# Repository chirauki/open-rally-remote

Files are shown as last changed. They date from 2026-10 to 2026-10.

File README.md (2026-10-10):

# Open Rally Remote

An open-source Bluetooth handlebar remote for motorcycle navigation and digital roadbooks. The project aims to keep the unit compact, rugged, affordable, and buildable one unit at a time by individual makers.

## Project status

Requirements and the first-version concept are being defined. No hardware design or compatibility claim has been validated yet.

See the [project brief](docs/project-brief.md) for the current goals, proposed design, constraints, and development plan. The current [control mapping draft](docs/control-mapping.md) records proposed app profiles and the compatibility checks still needed. The [prototype plan](docs/prototype-plan.md) compares controller candidates and lays out a bench proof of concept. The [XIAO breadboard assembly guide](docs/breadboard-assembly.md) gives a Spain-sourced bill of materials and wiring diagram for the temporary input fixture.

The proposed [firmware specification](docs/firmware-spec.md) defines the first BLE HID approach, input and gesture behavior, app-profile boundaries, bench validation, and the product requirement for phone-based BLE firmware updates.

The [development environment guide](docs/development-environment.md) explains how to set up Arduino IDE 2 for the purchased XIAO nRF52840, upload a smoke-test sketch, and use the Serial Monitor. The [mechanical CAD notes](docs/mechanical-concept.md) document the current NAVCOMM-referenced split-ring concept, with broad tapered shoulders joining the control pod to the clamp, raised external controls, and a 23 mm target width along the bar.

The [battery study](docs/battery-study.md) compares battery options and settles on a removable remote with a fixed LiPo pouch, shared between bikes on a bayonet base and charged off the bike (issue #1). It waits on bench and bike measurements; no CAD has changed yet.

The [joystick PCB](electronics/joystick-pcb/README.md) is a KiCad design for the four joystick switches and the 5 V input protection, with Gerbers and a BOM; it has not been built yet.

The first [XIAO diagnostic firmware](firmware/xiao-nrf52840/README.md) reads the breadboard switches and sends BLE HID keyboard events. It compiles and reads the joystick center as a chord of the direction switches, but has not yet been tested on the purchased hardware; app profiles and mobile OTA updates remain future work.

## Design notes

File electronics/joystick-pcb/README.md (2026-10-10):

# Joystick PCB — V0.23

The joystick PCB carries the four C&K KSC2 switches under the stick's cross disc, and the 5 V input protection for the whole remote. It fits the V0.23 enclosure ([CAD](../../mechanical/cad/complete-remote-v0.23.scad), [notes](../../docs/mechanical-concept.md)).

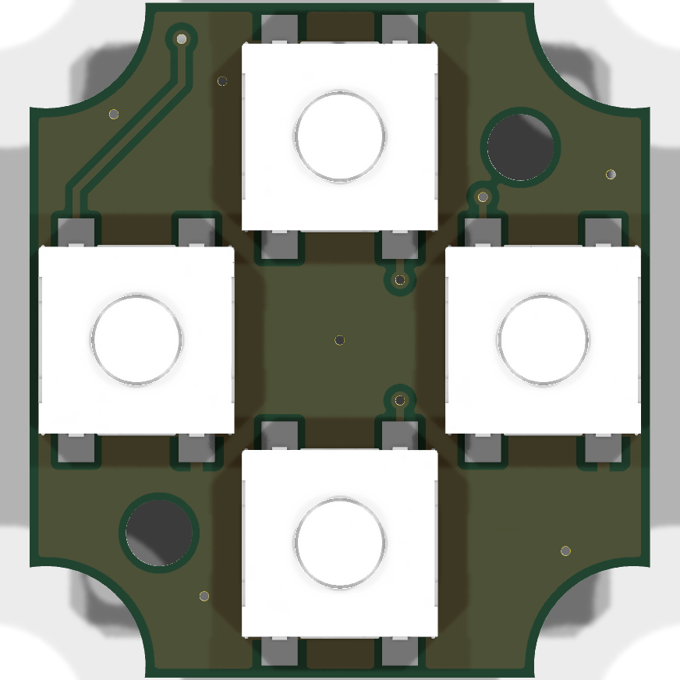
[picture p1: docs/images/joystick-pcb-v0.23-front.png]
Front: the four switches, facing the cover.


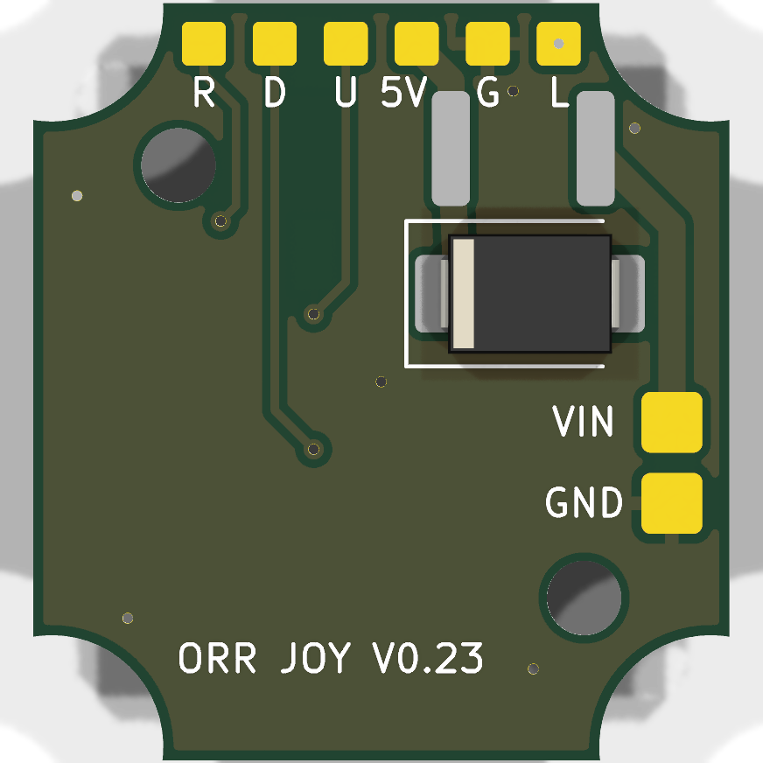
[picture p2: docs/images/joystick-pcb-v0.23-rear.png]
Rear: input pads, PTC fuse (pads only, no 3D model in the stock library), TVS diode and the six wire pads to the XIAO.


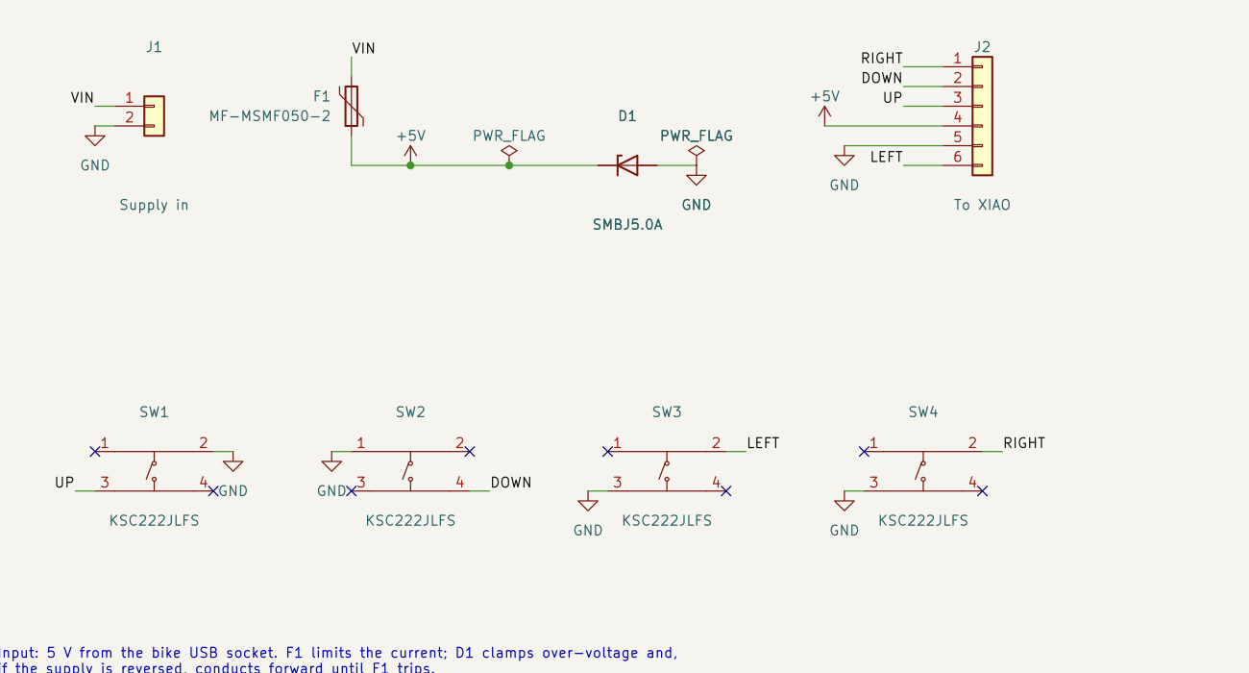
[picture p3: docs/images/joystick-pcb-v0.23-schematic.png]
Schematic.


Status: designed and checked in KiCad (ERC, DRC and schematic parity clean). Not yet built.

## Board

- Two layers, 1.6 mm FR-4, 1 oz copper. Ground pour on both sides.
- Outline 20.6 × 22.4 mm, with a 3.3 mm radius notch at each corner for the lower cover-screw bosses. The same numbers are in the CAD (`joy_pcb_hx`, `joy_pcb_hy`, `joy_pcb_notch_r`).
- Rules: 0.2 mm clearance, 0.25 mm signal tracks, 0.8 mm supply tracks, 0.6/0.3 mm vias, 0.3 mm copper to edge. These are within standard JLCPCB and PCBWay limits.
- Two Ø2.2 mm holes for M2 × 8 button-head screws into the joystick plate standoffs. The head must be no more than Ø3.5 × 1.1 mm (ISO 7380 style): a pan head touches a 12 mm wide USB-C plug in the XIAO when the cover is off.

Board coordinates are seen from the front (switch side, facing the cover). +x is the rider's right, +y is down the facet, away from button C.

## Circuit

| Net | Front | Rear |
|---|---|---|
| UP, DOWN, LEFT, RIGHT | One pad of each switch | Wire pads U, D, L, R to XIAO D3, D4, D5, D6 |
| GND | The diagonally opposite pad of each switch | Wire pad G to XIAO GND; input pad GND |
| VIN | — | Input pad VIN, through F1 |
| +5V | — | After F1; clamped by D1; wire pad 5V to the XIAO 5V pin |

- **Switches.** Each switch uses one diagonal pair of its four pads. Whether the part pairs pads 1-2 or 1-3 internally, a diagonal pair always spans the contact, so the internal pairing does not need to be confirmed. The other two pads are soldered but not connected.
- **Centre press.** There is no fifth switch. Pushing the stick straight in closes all four; the firmware reads the chord as the centre press (see the [firmware specification](../../docs/firmware-spec.md)).
- **F1.** Bourns MF-MSMF050-2, PTC resettable fuse, 1812: 0.5 A hold, 1 A trip, 15 V maximum.
- **D1.** Littelfuse SMBJ5.0A, unidirectional TVS, 600 W, 5.0 V stand-off. It clamps transients on the supply. If the supply is reversed, it conducts forward and F1 trips. The 15 V rating of F1 also covers a supply wired to 12 V by mistake; 6 V polyfuses, common in 1206, would not.
- The XIAO takes its supply from the 5V wire pad, not from the cable directly. In Seeed's XIAO nRF52840 V1.2 schematic (KiCad project dated 2026-08-28, from the Seeed wiki), the 5V header pin is the same net as the USB-C VBUS pins, with no diode or switch between them. The Schottky diode on the XIAO sits after that net, in front of its 3.3 V regulator. So the bike supply and a USB-C cable would be connected straight together, and each could feed current into the other. F1 limits that current to its 0.5 A hold rating, but that is still enough to stress a computer's USB port or the bike's socket. Do not connect USB-C while the bike supply is connected. The board revision bought may differ from V1.2; check its silkscreen.

## Placement against the enclosure

The CAD checks the PCB against the housing, cover, gasket, plate, stick, XIAO and USB-C plug:
- Front: the switch bodies and pads; the two standoffs clear the pads.
- Rear, everywhere: 1.0 mm for solder joints, vias and screw heads (1.1 mm).
- Rear, upper half (towards button C) and the two side strips |x| ≥ 6.3 mm: 3.0 mm. All rear parts and wire pads are in these zones. The lower middle stays low because a USB-C plug in the XIAO (cover off) passes close behind it.

Route the supply cable from the gland along the side wall to the VIN and GND pads, and the six XIAO wires from the top edge.

## Parts

| Ref | Part | LCSC | Side |
|---|---|---|---|
| SW1–SW4 | C&K KSC222JLFS, sealed tact switch, 2 N | C221728 | Front |
| F1 | Bourns MF-MSMF050-2 | C17313 | Rear |
| D1 | Littelfuse SMBJ5.0A | C83333 | Rear |
| J1, J2 | Wire pads (no part) | — | Rear |

The LCSC numbers were checked against the LCSC listings and the EasyEDA part data on 2026-10-10; stock and prices change.

The KSC2 land pattern comes from the LCSC/EasyEDA footprint for C221728. Its pads reach 0.95 mm beyond the body, so the joints can be reached with a fine iron tip or hot air.

## Fabrication files

`fab/` holds the outputs for the current board:
- `joystick-gerbers.zip` and `gerbers/`: copper, mask, paste, silkscreen, outline, and separate plated and non-plated Excellon drill files.
- `joystick-bom.csv`: grouped BOM with MPN and LCSC numbers.
- `joystick-pos.csv`: placement file (KiCad format, mm). JLCPCB expects its own column names and often needs rotation corrections for some parts; check the placement preview before ordering assembly.
- `joystick-schematic.pdf`.

Assembly on both sides costs more at most assembly services. Ordering assembly of the front (four switches) and hand-soldering F1 and D1 on the rear is the cheaper option; both are large parts.

## Regenerating

The board and schematic are generated by script, so the CAD numbers and the KiCad files stay in step. Edit `design.py` (placement, nets, routing), then run from this directory:

```
/Applications/KiCad/KiCad.app/Contents/Frameworks/Python.framework/Versions/Current/bin/python3 gen_pcb.py
```

`gen_pcb.py` writes `joystick.kicad_pcb` and calls `gen_sch.py` for `joystick.kicad_sch`. Then check and export:

```
K=/Applications/KiCad/KiCad.app/Contents/MacOS/kicad-cli
$K sch erc --severity-all joystick.kicad_sch
$K pcb drc --schematic-parity --severity-all joystick.kicad_pcb
$K pcb export gerbers --layers F.Cu,B.Cu,F.Paste,B.Paste,F.SilkS,B.SilkS,F.Mask,B.Mask,Edge.Cuts --subtract-soldermask -o fab/gerbers/ joystick.kicad_pcb
$K pcb export drill --format excellon --excellon-separate-th --generate-map --map-format gerberx2 -o fab/gerbers/ joystick.kicad_pcb
$K pcb export pos --format csv --units mm --side both --exclude-dnp -o fab/joystick-pos.csv joystick.kicad_pcb
$K sch export bom --fields 'Reference,Value,Footprint,Manufacturer,MPN,LCSC,${QUANTITY}' --labels 'Reference,Value,Footprint,Manufacturer,MPN,LCSC,Qty' --group-by 'Value,Footprint' --exclude-dnp -o fab/joystick-bom.csv joystick.kicad_sch
```

Tested with KiCad 10.0.6 on macOS. Run without a configured KiCad (no global library tables), ERC and DRC also report that the stock `Fuse`, `Diode_SMD` and symbol libraries are not configured; those warnings go away once KiCad has been opened once and has created its default tables.

The project tables (`fp-lib-table`, `sym-lib-table`) add the local `orr` library: the KSC2 footprint and 3D model, the wire-pad footprints, the standoff hole and the KSC222JLFS symbol.

## Open points

- Measure the switch height on the real parts: together with the printed plate, ball, disc and standoffs it sets the 0.05 mm rest gap under the disc.
- Decide whether to add a series Schottky diode after F1, so that USB-C can stay connected with the bike supply on. It would cost about 0.3–0.4 V at the XIAO, ahead of its own diode and regulator, and it needs a place on the rear of the board.
- Check the placement file rotations with the assembler's preview.

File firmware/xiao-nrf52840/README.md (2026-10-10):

# XIAO nRF52840 Bench Firmware

This folder contains the first diagnostic firmware for the Seeed XIAO nRF52840. It reads the switches and acts as a BLE HID keyboard. It is for bench testing only; it does not implement the final TerraPirata, OsmAnd, or DMD2 profiles and is not suitable for use while riding.

## Upload

Follow the [development environment guide](../../docs/development-environment.md), then open `open-rally-remote.ino` in Arduino IDE 2. Select **Seeed XIAO nRF52840** and the XIAO's USB port, then click **Verify** and **Upload**.

The sketch uses the `Seeed nRF52 Boards` package and its bundled Adafruit Bluefruit BLE HID library. It also includes `Adafruit_TinyUSB.h` to support the XIAO's USB serial diagnostics with this board package.

## Wiring

Wire each normally-open switch between its GPIO and GND:

| XIAO pin | Input | Diagnostic output |
|---|---|---|
| D0 | Button A | Short `A`, long `B`, double `C` |
| D1 | Button B | Short `D`, long `E`, double `F` |
| D2 | Button C | Short `G`, long `H`, double `I` |
| D3 | Joystick up | Hold Up Arrow |
| D4 | Joystick down | Hold Down Arrow |
| D5 | Joystick left | Hold Left Arrow |
| D6 | Joystick right | Hold Right Arrow |
| D7 | Joystick center switch, breadboard only | Short `J`, long `K`, double `L` |

The V0.22/V0.23 hardware has no D7 switch: pushing the stick straight in closes all four direction switches, and the sketch reads three or more closed together as the center press (see the [firmware specification](../../docs/firmware-spec.md#5-input-processing-and-gesture-rules)). This is the default, `CENTER_FROM_CHORD = true`, and D7 is then not read. For the breadboard, where a straight push cannot be made, set `CENTER_FROM_CHORD` to `false` near the top of the sketch to read a separate center switch on D7.

In chord mode, a direction key-down is held back for the 40 ms chord window (`CHORD_WINDOW_MS`) after the first direction closes:
- If three or more directions close inside the window, the sketch sends the center gesture and no arrow key until all directions are released.
- If two opposite directions are closed, no arrow key is sent.
- A tilt released inside the window is sent as one arrow tap.
- A push slower than the window first sends the arrow of the first switch, then releases it and sends the center gesture.

All connected pins use `INPUT_PULLUP`: open/released reads HIGH, pressed reads LOW. Do not connect an input to 3.3 V or 5 V.

## First test

1. Upload the sketch and open the Serial Monitor at 115200 baud.
2. Pair **Open Rally Remote** from the phone's Bluetooth settings.
3. Open a keyboard tester or a harmless text field, then press each control. Letters identify discrete gestures; joystick directions send held arrow-key reports.
4. Confirm short presses, long presses, double presses and release behavior. On the joystick, confirm that a straight push gives one center gesture and no arrow key, and that tilts and diagonals give no center gesture.

The short event is intentionally delayed by the 300 ms double-press window. Initial timings are set near 30 ms debounce, 600 ms long press, 300 ms double press, 40 ms chord window and 50 ms key-down duration. With the chord window, an arrow key-down follows the switch by about 70 ms.

The letters are diagnostic keys and may trigger actions in a navigation app. Do not test this firmware in an app while riding. The target app profiles and BLE firmware update/OTA support are not implemented in this sketch.

## Build check

The sketch was compiled on 2026-10-10 with `arduino-cli` and Seeed nRF52 Boards 1.1.13 for `Seeeduino:nrf52:xiaonRF52840`, in both center modes, with no warnings from the sketch. The package's own GCC 9 toolchain is an Intel binary and did not run on the Apple Silicon build machine without Rosetta, so the check used Arm GNU Toolchain 13.3. The Arduino IDE on a machine that runs the package toolchain may still report something different.

The chord logic was also run on the host against mocked switch timelines (tilt, short tilt, diagonal, staggered push, long and double push, slow push, opposite pair). It has not yet run on the XIAO or the real switches.

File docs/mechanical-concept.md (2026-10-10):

# Complete Mechanical CAD — V0.23 Joystick PCB

V0.23 fits the V0.22 joystick to a real PCB, now designed in KiCad: the [joystick PCB](../electronics/joystick-pcb/README.md) carries the four switches and the 5 V input protection. The housing, cover, gasket, stick and knob are unchanged from V0.22; the joystick plate's standoffs moved. The changes are listed under [Changes from V0.22](#changes-from-v022).

V0.22 put a joystick back on the lower facet, built from low-cost parts, and widened the control end of the pod from 23 to 26 mm. The clamp ring and the rear of the pod stay 23 mm wide along the bar.

The joystick is a steel pin with a printed ball. The ball pivots against a seat in a printed joystick plate. Under the ball, a cross-shaped disc rests on four C&K KSC2 sealed tact switches, whose springs centre the stick. Tilting the stick presses one switch; pushing it straight in presses all four, which the firmware reads as the centre press. The parts cost a few euros. The Ruffy MHS of V0.20 was listed at about £149, and the APEM NV, the closest commercial alternative found, at $143.

All printed housing parts are still slices of one outer solid: the convex hull of the pod outline and the Ø44 mm clamp circle, 23 mm wide along the bar, plus the 26 mm control end. Offsets of the folded front cut the cover and gasket from it; the diametral clamp split cuts the cap. Supplier and purchase unknowns remain open and are listed at the end; they are marked `MEASURE` in the CAD.

The remote mounts on the left side of the bar only, never the right. The turn-signal switch that the folded front clears is on the left switchgear.

**Current parametric concept:** [complete-remote-v0.23.scad](../mechanical/cad/complete-remote-v0.23.scad)

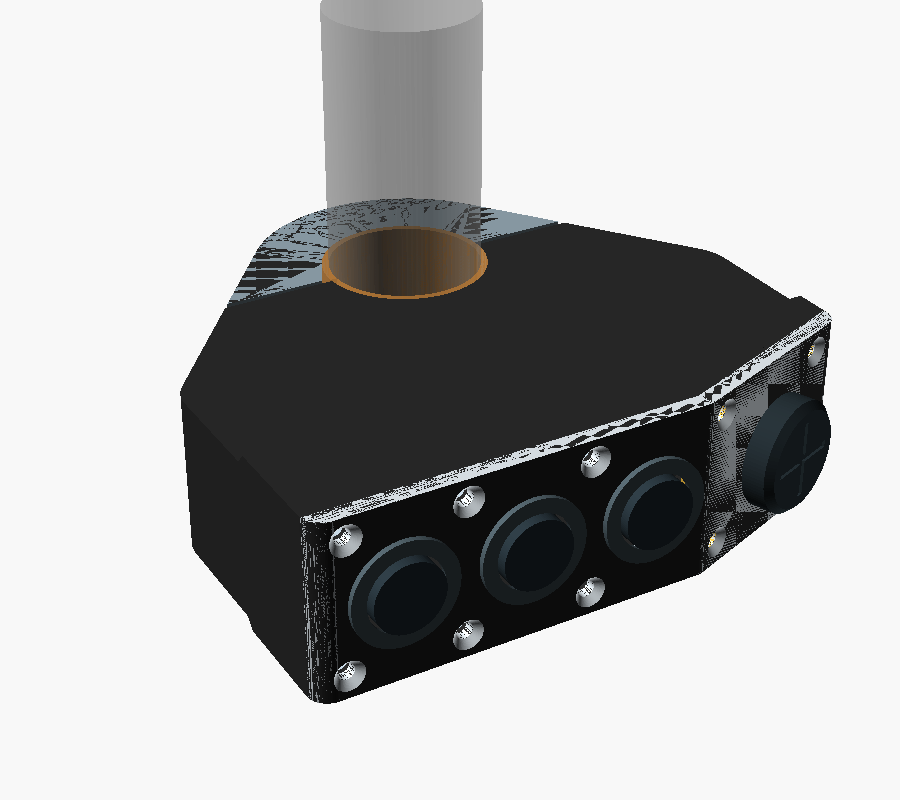
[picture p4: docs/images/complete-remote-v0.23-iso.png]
V0.23 assembly, isometric view from the control side.


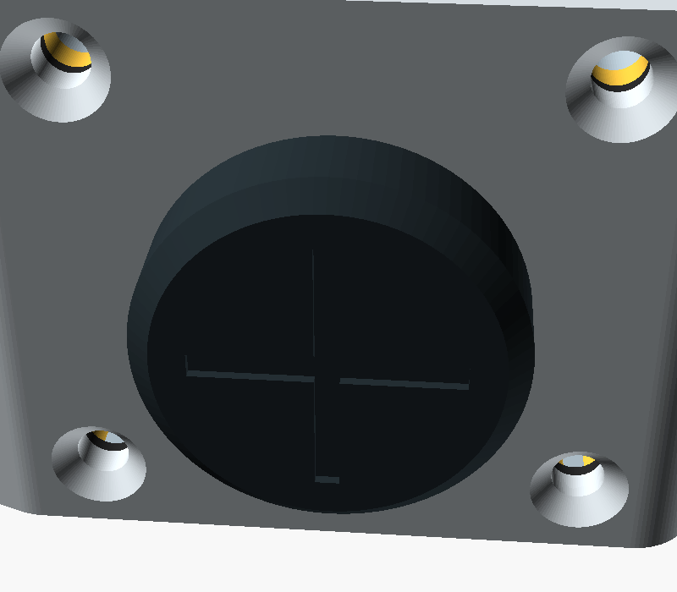
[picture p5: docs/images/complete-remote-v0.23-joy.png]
V0.23 joystick knob on the lower facet, between the four lower cover screws. The engraved cross shows the four directions.


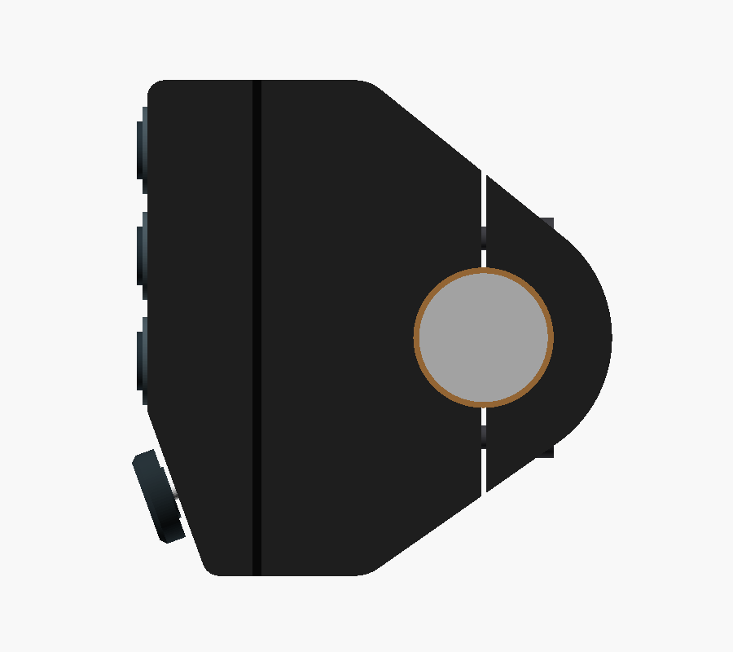
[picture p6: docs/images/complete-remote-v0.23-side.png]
V0.23 seen along the bar: the upper facet with buttons A, B, C and the lower facet with the joystick, turned 20 degrees toward the bar.


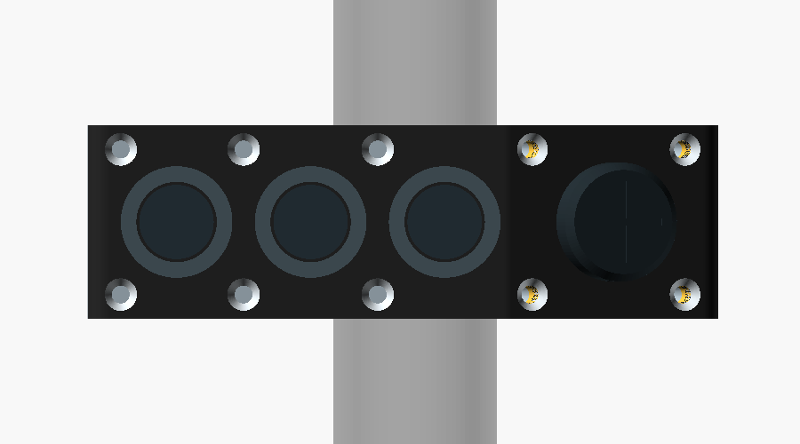
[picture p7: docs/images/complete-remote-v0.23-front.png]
V0.23 control cover seen from the rider's side.


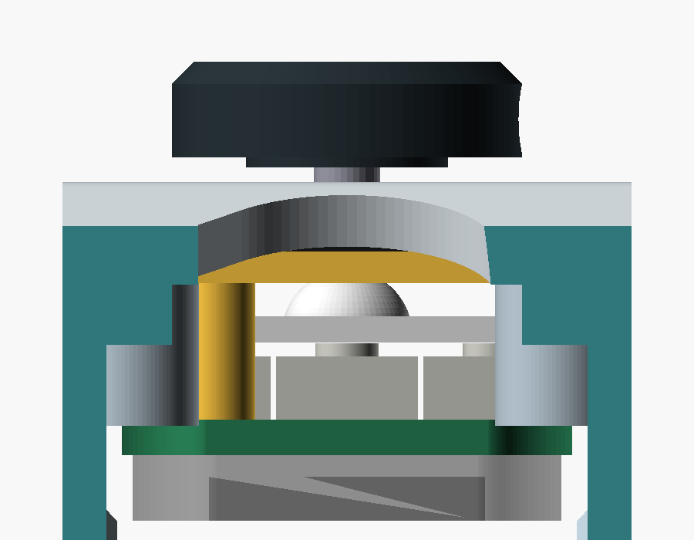
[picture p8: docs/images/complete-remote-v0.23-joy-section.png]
V0.23 section through the joystick axis, drawn with the cover at the bottom: knob, cover, sheet gasket gripping the stick, joystick plate with the ball seat, ball and cross disc, switches, PCB on its standoffs, and the rear component zone behind it.


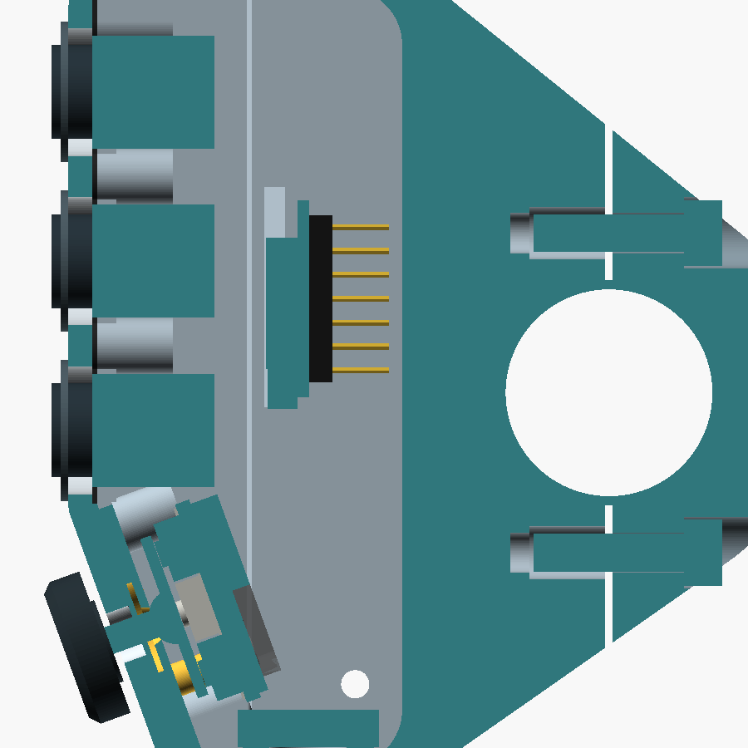
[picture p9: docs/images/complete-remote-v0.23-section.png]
V0.23 section through the middle of the pod.


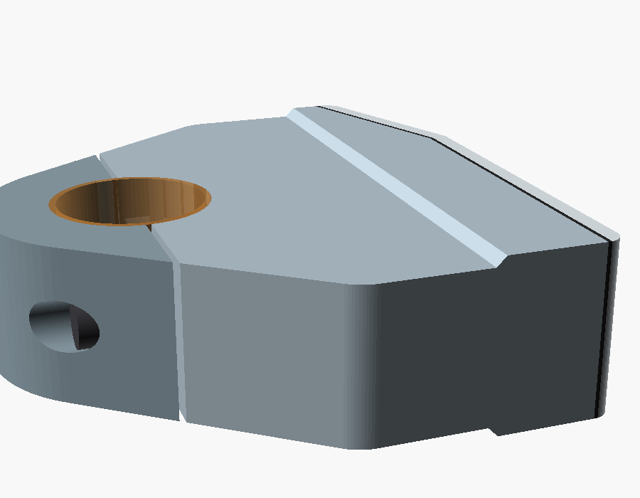
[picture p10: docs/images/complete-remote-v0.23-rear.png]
V0.23 from the back and below: the 45° chamfer between the 26 mm control end and the 23 mm clamp.


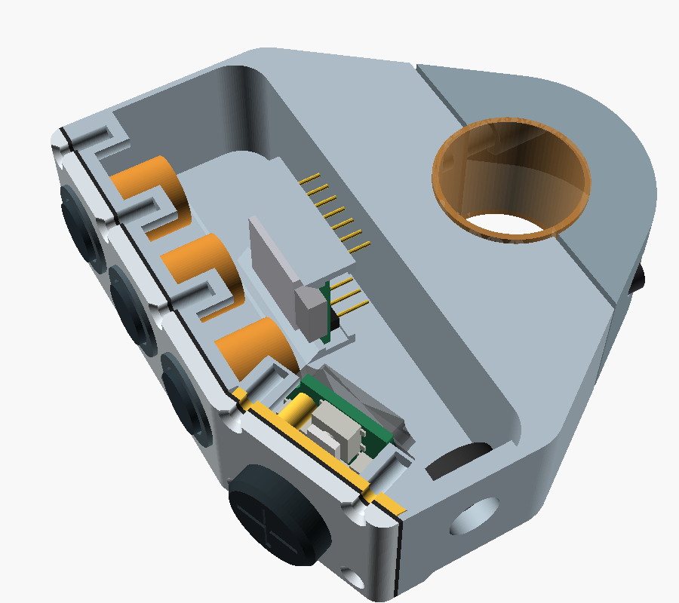
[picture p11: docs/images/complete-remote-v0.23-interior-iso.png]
V0.23 interior with the upper axial wall removed. The joystick plate (yellow), the stick and the PCB sit behind the lower facet.


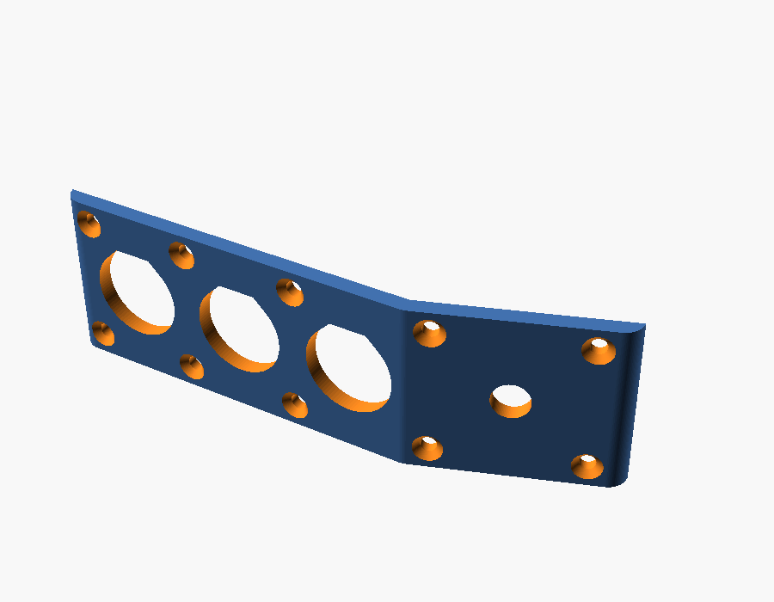
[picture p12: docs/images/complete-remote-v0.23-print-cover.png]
V0.23 cover in its print orientation, on its axial face.


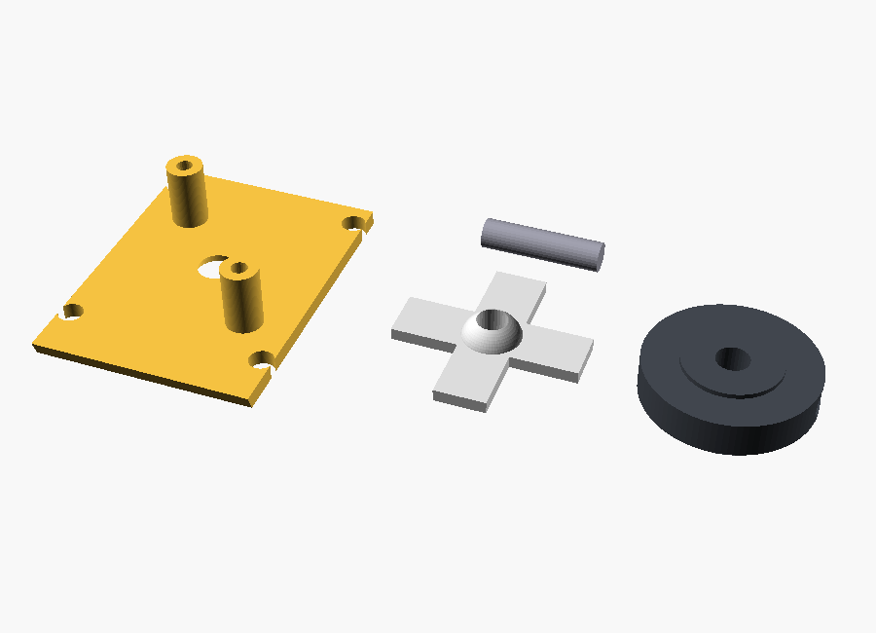
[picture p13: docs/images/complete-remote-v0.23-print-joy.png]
V0.23 joystick parts in their print orientations: the plate on its sheet side with the two PCB standoffs up, the ball and disc on the disc, the knob on its top face, and the Ø3 × 12 mm steel pin (bought).


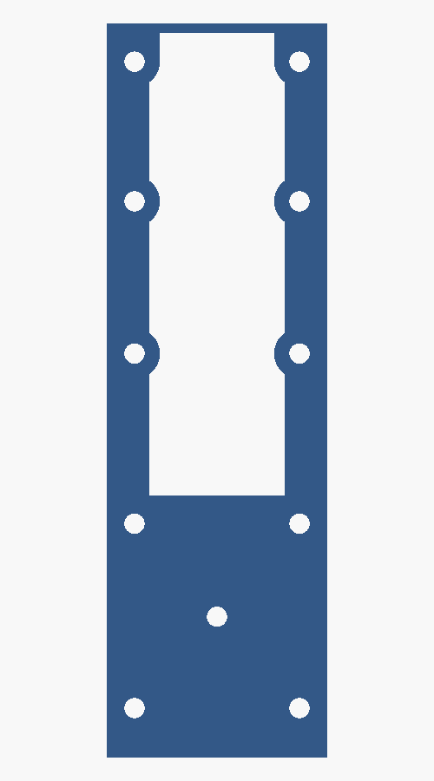
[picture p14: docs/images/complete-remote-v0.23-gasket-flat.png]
V0.23 gasket unfolded flat: wall land on the upper facet, a full sheet with the stick hole on the lower facet.


All images are direct OpenSCAD renders of the V0.23 file. The PCB images are on the [joystick PCB page](../electronics/joystick-pcb/README.md).

## Changes from V0.22

The LCSC land pattern for the KSC222JLFS (C221728) puts its pads 0.95 mm outside the switch body, on two opposite sides. The V0.22 layout had not allowed for that.
- **Switch orientation.** All four switches turn 90°. The pad rows of the up and down switches run along the facet; those of the two bar-axis switches run across it. The nearest pads of neighbouring switches are then 1.55 mm apart.
- **Standoffs.** They move from (∓5.6, ±5.4) to (∓6.0, ±6.4) mm in the joystick frame, 0.55 mm clear of the switch pads.
- **PCB outline.** A 20.6 × 22.4 mm rectangle with a 3.3 mm radius notch around each lower cover-screw boss. The boss ends reach 0.25 mm past the PCB front face, so the board must clear them. The CAD and the KiCad board use the same numbers.
- **Rear zone.** 1.0 mm behind the whole board for solder joints, vias and screw heads, and 3.0 mm in the upper half and in the two side strips for the TVS diode (2.45 mm maximum), the PTC fuse and the soldered wires. The lower middle stays at 1.0 mm because a USB-C plug in the XIAO passes close behind it when the cover is off.
- **PCB screws.** M2 × 8 button heads, at most Ø3.5 × 1.1 mm. A pan head (1.6 mm) would touch the 12 mm wide USB-C overmold envelope with the cover off.
- **Power input.** The supply cable now goes to the joystick PCB, through a PTC fuse and a TVS diode, and the PCB feeds the XIAO's 5V pin.
- **Firmware.** The specification now describes the four-switch chord as the centre press; D7 is unused. The diagnostic sketch implements the chord; a separate centre switch on D7 remains as a build option for the breadboard.

## V0.22 changes from V0.21, still current

V0.21 replaced the joystick with four Ø7 mm keys. That direction was dropped, for three reasons:
- Ø7 mm keys with 1.6 mm between them are too small for gloves; a reference guideline asks for at least Ø10 mm for a bare fingertip.
- On the 20° lower facet, flat keys are hard to see, and the thumb has to press them from below.
- A joystick sticks out and is pushed sideways, so it works on that facet.

V0.22 keeps from V0.21 the sheet gasket and the plate that clamps it, and replaces the keys with a joystick.

- **Joystick mechanism.** In the joystick frame, from the outside in:
  - A Ø16 mm knob stands 5.5 mm proud. A Ø9.2 mm hub on its underside is 0.7 mm above the cover; its rim is 1.15 mm above.
  - The stick is a Ø3 × 12 mm steel dowel pin (ISO 8734). It passes through a Ø5.6 mm hole in the cover, and the sheet gasket grips it through a Ø2.4 mm hole. Steel is stronger than a printed Ø3 mm stick, and its smooth surface seals better against the sheet.
  - A printed Ø6 mm ball bears against the back edge of a Ø3.6 mm hole in the 1.5 mm joystick plate. That edge is the pivot, 7.0 mm behind the outer face. The pin is pressed into a bore through the ball and disc.
  - A cross disc, 1.2 mm thick, under the ball rests 0.05 mm above the actuators of four KSC2 switches. The switches are 6.75 mm from the axis, two along the facet (up toward button C, down) and two along the bar.
  - The PCB screws to two standoffs on the plate. Its front face is 10.85 mm behind the outer face; the rear zone ends at 13.45 mm, or 15.45 mm where the rear parts are (V0.23). The MHS body reached 16 mm.
  - The ball and disc are one printed part. The knob slides onto the pin from outside after assembly, and an M2 × 4 grub screw in a radial M2 heat-set insert clamps it. It comes off with a hex key; nothing is glued.
- **Feel and limits.**
  - A direction trips at no more than 4.7° of tilt. At that point the knob top has moved at most 1.0 mm.
  - The knob rim meets the cover at 8.2° of tilt, and the hub at 0.7 mm of push. That is past the switches' 0.55 mm worst case (rest gap plus 0.5 mm maximum travel), so a hard press with a glove ends on the cover, not on the switches.
  - The disc has room to tilt 9.5° before it meets the plate.
  - The switches' own springs centre the stick and hold the ball on its seat. There is no separate spring.
- **Centre press.** Pushing the stick straight in presses all four switches. The firmware reads that chord as the centre press (three or more switches within a short window) and otherwise reports the held directions. A fifth switch would have to sit on the axis, where the ball and disc are.
- **Wider control end.** For X below −38 mm, which covers the cover, the buttons and the joystick, the pod is 26 mm wide with 2 mm axial walls, leaving a 22 mm cavity. A 45° chamfer of 1.5 mm per side (`pod_step`) joins it to the 23 mm part; the walls in the chamfer are at least 1.1 mm thick, and the chamfer faces up when the housing prints. The clamp ring, the shoulders and the XIAO area keep 23 mm with 1 mm walls. The 23 mm comes from the NAVCOMM manual's minimum free space on the bar between grip and switchgear. It applies to what sits on the bar, not to the control end 40–60 mm from the bar axis. The 2 mm walls give four perimeters instead of two, which seals and prints better. The cover screws stay 3.25 mm from the outer faces, so their bosses intrude 1 mm less into the cavity.
- **Joystick plate.** It is the V0.21 keypad plate with a seat hole, a 0.6 mm pocket in front so the sheet can follow the stick, and 6.25 mm standoffs for the PCB. The four lower cover screws (M2 × 10) still clamp it and the sheet.

### V0.21 changes, still current

- **Sheet gasket on the lower facet.** On the lower facet the gasket is a full sheet between the cover and the plate. It seals the cover joint and the joystick opening. The upper facet keeps its wall land.
- **Lower cover screws.** M2 × 10 through the plate, 5.4 mm into the inserts; their bosses start behind the plate. The six upper-facet screws stay M2 × 8.

### V0.20 changes, still current

- **Folded front.** The fold line is 12.5 mm below the bar axis, between button C and the joystick. The lower facet is 30 mm long and turns 20° toward the bar (`fold_angle`), so its lower end sits 10.3 mm closer to the bar. This clears the thumb's path to the turn-signal switch, which the straight V0.19 face obstructed. The joystick axis is 14.5 mm below the fold.
- **Why 20° and not 30°.** At 30° the end wall becomes too short for the gland lock nut beside the corner screw bosses. The 30° values are noted next to `fold_angle` in the CAD.
- **Pod length.** Buttons at Y = 32, 14, −4 mm; the pod spans Y = −40.7 to 44 mm (84.7 mm). The axis-to-button-C distance is 57.5 mm perpendicular to the bar.
- **Cover gasket.** 0.6 mm when compressed: printed 0.8 mm thick in a soft TPU, or cut from 0.8–1 mm silicone or EPDM sheet using the flat model as a template. On the upper facet the housing land is the wall plus a 3 mm lip inside both axial walls, and a Ø6 mm pad around every screw.
- **Cover screws.** Ten countersunk M2 screws in pairs at five positions. The largest spacing along the perimeter is 21.8 mm.
- **Cover printing.** The cover prints on its axial face, because the fold would need support face down.
- **Cable gland.** In the bottom end wall at X = −32 mm. `cable_at_bottom = false` moves it to the top end wall.
- **Vent.** A Ø3 mm hole in the Z = 0 axial wall at the low end takes an adhesive ePTFE vent label inside.
- **XIAO.** At Y = 10 mm, so a USB-C plug clears the lower screw bosses when the cover is off.

## Interior space check

The OpenSCAD console reports these values; the boolean checks below were run on the rendered meshes.

| Check | Result |
|---|---|
| Button bodies vs housing, cover, gasket | No overlap |
| Joystick switches, pads and PCB with its rear zone vs housing, cover, gasket, stick | No overlap |
| Joystick switches and PCB vs joystick plate | Contact only (PCB on the standoffs) |
| Stick and knob vs cover, plate, housing at rest | No overlap; the ball touches its seat |
| Stick vs gasket | 1.5 mm³ overlap by design: the Ø2.4 mm sheet hole is stretched over the Ø3 mm stick |
| Stick and knob tilted to the knob stop (8.2°), four directions and one diagonal | Clear of the plate, cover and housing; the disc only meets the switch actuators, the rim only touches the cover |
| Knob (also tilted) vs button bezels and caps | No overlap |
| Pin vs ball and disc | 0.67 mm³ overlap by design: press fit in the Ø2.95 mm bore |
| Stick and knob pushed to the knob stop (0.7 mm) | Clear of the plate, cover and housing |
| Joystick plate vs housing, cover | No overlap; contact with the shortened bosses |
| Plate, stick and PCB vs buttons, XIAO, XIAO slide-in path, gland nut, vent | No overlap |
| PCB rear zone and screw heads vs USB-C plug (cover off) | Contact only (0.00 mm³) at the lower screw head |
| Cover screws vs joystick, buttons, XIAO; countersinks vs knob | No overlap |
| XIAO envelope vs housing | No overlap in place, and none along a 22 mm slide-in path |
| Wiring space between button rear ends and XIAO component side | 5.5 mm |
| XIAO pin tips to cavity rear wall | 1.4 mm |
| USB-C plug (12 × 6.5 × 25 mm overmold) with the cover off | Clear of the housing and the gland nut |
| Gland lock nut (Ø15 × 4 mm envelope); vent label area | Contact only with the housing faces they sit on |
| Wall around the M2 and M4 insert holes | At least 0.8 mm and 1.2 mm |
| Cover vs housing; gasket vs cover and housing; cap vs housing | Contact only, no overlap |
| Bar and liner (Ø24 mm) leaving the body toward the cap side | Clear |
| Each printed part | One closed solid |

The tightest points are now:
- the 1.4 mm behind the XIAO pins;
- the lower PCB screw head against the USB-C plug envelope with the cover off (contact). With a plug wider than 12 mm, lift the joystick plate out first; it is loose once the cover is off;
- 0.55 mm between the PCB standoffs and the switch pads, and 0.3 mm between the PCB notches and the lower cover-screw bosses;
- the stack that sets the 0.05 mm rest gap under the disc: switch height, printed plate, ball and disc, and the standoffs. If the stick rattles or a switch is pressed at rest, shim or sand under the PCB standoffs.

## Sealing

V0.23 aims for rain and spray resistance, not an IP rating. It has not been tested.

1. **Buttons.** Use buttons rated for front-panel sealing (IP67 or better), with their panel gasket. This has not been verified for the APEM IS order codes; check the datasheets before buying.
2. **Joystick.** The cover hole is open to the outside. The sheet gasket is the seal there: it is clamped all round the hole and grips the stick. A printed TPU sheet that flexes with every stick movement may tear or creep; a cast silicone sheet would last longer.
3. **Cover joint.** The gasket and ten screws. On the lower facet the sheet is clamped over the whole facet. Elsewhere the land is now the 2 mm wall of the wide part.
4. **Cable.** An IP68 M8 gland matched to the cable diameter. Seal the outer thread with neutral-cure silicone.
5. **Vent.** An adhesive ePTFE vent label over the Ø3 mm hole, inside. Without it, temperature cycles pump humid air into a sealed box, and the water condenses inside. Mount the unit so the vent faces down or sideways, not into spray.
6. **Electronics.** Coat the XIAO, the joystick PCB and all solder joints with conformal coating (acrylic or silicone). Keep it off the USB-C socket, the switch actuators, and the vent membrane.
7. **Printed walls.** The narrow rear part still has 1 mm walls, only two perimeters with a 0.4 mm nozzle, and FDM layers can leak. Print PETG hot and slow for good layer bonding, or seal the outside with a thin coat of epoxy or lacquer.

## Printing

| Part | Mode | Orientation | Material (suggested) |
|---|---|---|---|
| Housing | `print_housing` | Upper facet on the bed | PETG or ASA |
| Clamp cap | `print_cap` | Axial face on the bed | PETG or ASA |
| Control cover | `print_cover` | Axial face on the bed | PETG or ASA |
| Joystick plate | `print_joy_plate` | Sheet side on the bed | PETG |
| Ball and disc | `print_ball_disc` | Disc on the bed | PETG |
| Knob | `print_knob` | Top face on the bed | PETG or ASA |
| Gasket | `print_gasket` | Flat, 0.8 mm | Soft TPU (85A or softer), or cut from silicone/EPDM sheet |
| Liners ×2 | `liner_main`, `liner_cap` | Axial face on the bed | TPU 95A |

No part needs supports.
- **Housing:** the walls are vertical, the lower facet is an open edge in the air, the lower screw bosses lean 20°, and the cavity's rear wall bridges 21 mm. The XIAO rails have 45° chamfers. It stands on its thin front rim, so use a brim.
- **Cover:** the Ø5 mm stick hole is small enough to bridge. It stands on a 2.5 mm edge, so use a brim.
- **Ball and disc:** the ball above the disc narrows upward. Test the press fit of the pin in the Ø2.95 mm bore (`pin_bore`) before assembly.
- **Knob:** the radial insert hole is horizontal and small enough to bridge.
- **Inserts:** use 100% infill or at least four perimeters around the M4 insert holes.
- **Gasket:** TPU 95A is probably too hard to seal at 0.2 mm compression; prefer a softer TPU or a cut sheet gasket. If you cut the sheet, punch the Ø2.4 mm stick hole.

## Assembly

1. Press the two M4 inserts into the housing split face and the ten M2 inserts into the housing screw bosses with a soldering iron.
2. Mount the three buttons in the cover.
3. Solder the four KSC2 switches to the front of the joystick PCB, and the PTC fuse and TVS diode to the rear (or order the board assembled).
4. Push the stick through the joystick plate from the back, so the ball sits in its seat. Screw the PCB onto the plate standoffs with two M2 × 8 button-head screws (head at most Ø3.5 × 1.1 mm); the disc rests on the switches.
5. Solder six wires from the rear pads of the joystick PCB to the XIAO: U, D, L, R to D3–D6, G to GND and 5V to the 5V pin. Lead them away from the top edge of the PCB. Solder the button wires as before.
6. Pass the power cable through the gland in the bottom end wall, lead it along the side wall, and solder its wires to the VIN and GND pads on the rear of the joystick PCB. The USB-C plug cannot pass through an M8 gland.
7. Slide the XIAO into the rails along +Y until it stops. Secure its free end with a drop of hot glue or silicone. Apply conformal coating to both boards.
8. Stick the vent label inside over the vent hole.
9. Lay the cover face down and the gasket on it, folded at the fold line. Push the stick through the sheet hole and the cover hole, and lay the plate on the lower-facet sheet with its screw holes over the cover's.
10. Lower the housing onto the stack; its walls locate the plate. Turn the assembly over and fit the six M2 × 8 screws on the upper facet and the four M2 × 10 screws on the lower facet. Tighten evenly in a cross pattern.
11. Press the M2 insert into the knob. Slide the knob onto the pin with a 0.7 mm shim between the hub and the cover, and tighten the M2 × 4 grub screw on the pin.
12. Fit the liner halves, place the housing on the bar, fit the cap from behind, and tighten the two M4 × 16 bolts evenly.

To program over USB, remove the cover. Take the knob off first by loosening its grub screw. The USB-C socket is on the component side at the lower end of the board and opens toward the bottom of the pod; a plug fits there with the cover off. Each opening disturbs the gasket, so BLE firmware updates remain a firmware requirement.

## Hardware

| Item | Qty |
|---|---:|
| M4 × 16 ISO 4762 socket-head screw | 2 |
| M4 heat-set insert, short (hole Ø5.6 × 8.1 mm in CAD) | 2 |
| M2 × 8 ISO 10642 countersunk screw (upper facet) | 6 |
| M2 × 10 ISO 10642 countersunk screw (lower facet) | 4 |
| M2 heat-set insert, about 4 mm long (hole Ø3.2 × 6 mm in CAD) | 10 |
| C&K KSC2 sealed tact switch, 2 N, J-bend (for example KSC222JLFS) | 4 |
| [Joystick PCB](../electronics/joystick-pcb/README.md), 20.6 × 22.4 mm, 1.6 mm, with the Bourns MF-MSMF050-2 PTC fuse and Littelfuse SMBJ5.0A TVS diode | 1 |
| M2 × 8 button-head screw, head at most Ø3.5 × 1.1 mm (joystick PCB) | 2 |
| M8 × 1.25 IP68 cable gland for 3–5 mm cable | 1 |
| Adhesive ePTFE vent label, about Ø10 mm, for a Ø3 mm hole | 1 |
| Ø3 × 12 mm steel dowel pin, ISO 8734 (joystick stick) | 1 |
| M2 × 4 grub screw and M2 heat-set insert (knob) | 1 each |
| Conformal coating, neutral-cure silicone | small amounts |

The KSC2 J-bend terminals sit under the switch body. The LCSC land pattern used on the PCB extends 0.95 mm beyond the body, so a fine iron tip or hot air can reach the joints; having the board assembled is the easier option. The gull-wing version (`G`) has a different land pattern and does not fit this PCB.

## NAVCOMM reference

The [NAVCOMM product page](https://hesaparts.com/product/navcomm/) is the project's stated reference. Its [official user manual](https://hesaparts.com/wp-content/uploads/2025/02/EN/NAVCOMM%20USER%20MANUAL.pdf) specifies a 22 mm handlebar, at least 23 mm of space between the grip and the motorcycle's switchgear, rotation of the unit to suit the rider's reach, and fixing with two M4 screws and a flange. The control arrangement is one function button, two function/zoom buttons, and a lower four-way joystick.

V0.8 follows those functional and packaging cues while keeping original geometry. The CAD uses 23 mm as the target width along the bar, matching the manual's minimum installation gap; the manual does not publish the NAVCOMM's own overall width. Two parallel M4 bolts on either side of the bar close the rear clamp cap; ten M2 screws hold the control cover. The side panel keeps button presses perpendicular to the bar and can rotate around the bar before tightening.

## Sourced dimensions and design targets

| Feature | CAD value | Basis |
|---|---:|---|
| XIAO nRF52840 board outline | 21 × 17.8 mm | Seeed Studio published dimensions |
| APEM IS button panel opening | Ø13.6 mm | APEM IS series drawing |
| APEM reduced bezel option | 15 mm | APEM IS series options; confirm exact ordered variant |
| KSC2 switch | 6.2 (+0.3) × 6.2 (+0.3) mm body, 3.5 mm to the actuator top, Ø2.9 mm actuator; 2 N, 0.35 ± 0.15 mm travel (KSC22x) | C&K KSC2 datasheet; modelled at 6.5 mm |
| Handlebar | Ø22 mm nominal | Project target; measure the actual straight section |
| Integrated clamp | Ø44 mm outer diameter, Ø24 mm bore | Diametral split into two 180-degree halves with a 0.8 mm clamping gap |
| Clamp radial section | 10 mm | Derived from Ø44 mm outer diameter and Ø24 mm bore; not strength-validated |
| Pod-to-clamp shoulders | Tangent lines from the 7 mm rear pod corners to the Ø44 mm ring | Convex hull of pod outline and clamp circle, following the marked silhouette |
| Pod front corners | 3 mm radius | Leaves a flat cover face for the M2 screws |
| Folded front | Upper facet normal to the pod axis; lower facet turned 20° toward the bar, fold 12.5 mm below the bar axis | Clears the thumb's path to the turn-signal switch; the angle is a parameter |
| Pod cavity corners | 2 mm front, 6 mm rear | 1 mm inset from the outer corners |
| Clamp liner | 1 mm radial TPU liner gives Ø22 mm nominal inner diameter | Parametric target; tune to measured bar and print process |
| Enclosure envelope | 79.5 × 84.7 mm in the plane of the clamp; 23 mm along the bar at the clamp, 26 mm at the control end | Bar footprint from the manual's 23 mm installation clearance |
| Button direction | Button axes perpendicular to the handlebar axis | Layout requirement |
| Case wall / cover | 2.0 mm axial walls at the control end, 1.0 mm in the narrow part and at the ends / 2.5 mm cover | Cover within the APEM IS panel range |
| Control layout | Buttons at Y = 32, 14, −4 mm (18 mm pitch) on the upper facet; joystick axis 14.5 mm below the fold on the lower facet, 23 mm from button C measured over the surface | Layout target; confirm glove access and supplier bezel sizes |
| Clamp fasteners | Two parallel M4 × 16 ISO 4762 bolts at ±17 mm from the bar axis; Ø7.6 mm counterbores 8 mm from the split face; Ø5.6 × 8.1 mm insert holes | 7.6 mm grip, 7.6 mm engagement, 2.85 mm wall to bore; confirm against the bought bolts and inserts |
| Cover fasteners | Six M2 × 8 (upper facet) and four M2 × 10 (lower facet, through the joystick plate) ISO 10642 countersunk screws; Ø3.2 × 6 mm insert holes in Ø6 mm bosses | Spaced 16.5–21.8 mm along the perimeter to compress the gasket; confirm against the bought inserts |
| Cover gasket | 0.6 mm compressed (0.8 mm printed or cut) | Upper facet: 1 mm on the walls, 4 mm with the lip, Ø6 mm around each screw. Lower facet: full sheet on the joystick plate, Ø2.4 mm hole stretched over the stick |
| Pod width | 23 mm along the bar at the clamp and the rear of the pod; 26 mm for X < −38 mm | 23 mm from the NAVCOMM manual's minimum free space on the bar; the control end is 40–60 mm from the bar axis |
| Joystick | Ø16 mm knob 5.5 mm proud, hub 0.7 mm and rim 1.15 mm above the cover; Ø3 × 12 mm steel pin; Ø6 mm ball on a Ø3.6 mm seat edge, pivot 7.0 mm behind the face; 1.2 mm cross disc 0.05 mm above four KSC2 at 6.75 mm | Trips at ≤ 4.7° tilt; knob stop at 8.2° or 0.7 mm push; disc room 9.5° |
| Joystick plate | 1.5 mm, behind the sheet; Ø3.6 mm seat hole opening to Ø4.8 mm at the front; Ø10 × 0.6 mm sheet pocket; two Ø3.6 mm standoffs, 6.25 mm tall, at (∓6.0, ±6.4) mm from the stick axis | Printed PETG; clamped by the four lower cover screws |
| Joystick PCB | 20.6 × 22.4 mm with four R3.3 mm boss notches; front face 10.85 mm behind the outer face, 1.6 mm thick; rear zone 1.0 mm, 3.0 mm in the upper half and the side strips | KiCad design in electronics/joystick-pcb; switch land pattern from LCSC C221728 |
| Cable entry | Ø8.2 mm hole in a 3 mm area of the bottom end wall | Seat for an M8 gland; verify after selecting the gland and cable |
| Vent | Ø3 mm hole in the axial wall at the low end, Ø10 mm flat area inside | For an adhesive ePTFE vent; verify against the chosen vent |
| USB cable jacket | 3–5 mm range candidate | Hummel M8 gland example; measure actual cable |
| XIAO PCB / header spacer / pins | 1.2 / 2.5 / 6 mm | Allowances for the pre-soldered version; measure the bought board |

Seeed lists the XIAO board at 21 × 17.8 mm and provides a [2D DXF drawing](https://wiki.seeedstudio.com/XIAO_BLE/). The purchased variant has pre-soldered headers; V0.22 keeps the board parallel to the control cover, behind the control bodies, with the header pins pointing away from the controls. The 2.5 mm spacer and 6 mm pin length are allowances, not supplier dimensions. The [Kiwi listing](https://www.kiwi-electronics.com/en/seeed-studio-xiao-nrf52840-pre-soldered-20402) confirms the headers are pre-soldered. Check the actual header, USB-C, antenna, and component clearances against the printed cavity before finalizing it.

The C&K [KSC2 datasheet](https://www.ckswitches.com/products/switches/product-details/Tactile/KSC2) gives the 6.2 × 6.2 mm body with +0.3 mm tolerance, the 3.5 mm soft-actuator height, a Ø2.9 mm actuator, the IP67 rating, and the travel per force code: 0.3 ± 0.2 mm at 1.6 N, 0.35 mm at 2 N, and 0.5 ± 0.2 mm at 3.5 N and 5.5 N. The knob stop at 0.7 mm of push covers the 2 N types (0.05 mm rest gap plus 0.5 mm maximum travel); the 3.5 N and 5.5 N types can travel 0.7 mm and would need a larger gap. V0.20's Ruffy MHS joystick was listed at about £149 for one unit at Farnell UK, and the APEM NV 5-way (NVH1D1C1CP2S) at $143.34 at Mouser.

APEM's [IS series page](https://www.apem.com/panel-switches/pushbutton-switches/is) gives the Ø13.6 mm panel cutout, 13 mm behind-panel depth, 1.5–4 mm panel range, and 15 mm reduced-bezel option. Order-code availability and the reduced-bezel variant's exact drawing must be confirmed before selecting the production switch.

## Open unknowns before printing

These are the only items that block a confident first print. Each is a parameter in the CAD.

- **Buttons:** exact APEM IS order codes, sealing rating, nut sizes behind the panel, terminal length, and wire exit.
- **Joystick:** measure the KSC2 height and the printed plate, ball and disc; together with the standoffs they set the 0.05 mm rest gap (`joy_rest_gap`). The feel (4.7° to trip, 2 N per direction, about 8 N for the centre chord) and the Ø16 mm knob need a check with gloves.
- **XIAO:** PCB thickness, header spacer height, pin length, and component height. Adjust `xiao_pcb`, `xiao_header_plastic`, `xiao_pin_length`, and `xiao_component_h`; the render stops if the pins reach the rear wall.
- **Inserts:** hole diameters and depths for the actual M4 and M2 inserts.
- **Handlebar and liner:** measured bar diameter, and the 0.8 mm clamping gap tuned to the printed TPU liner.
- **Cable gland:** thread, lock-nut size (Ø15 × 4 mm assumed), and cable diameter.
- **Vent:** label diameter and required hole size.
- **Gasket:** material, whether 0.2 mm of compression seals on a 1 mm land, and how long a printed TPU sheet lasts flexing with the stick.
- **Fold angle:** 20° is chosen to clear the turn-signal switch while keeping the gland at the bottom, but it has not been checked on the bike.

Not addressed by this concept: IP rating, impact, vibration, and fatigue strength. These need physical testing.

## Earlier versions

V0.1–V0.22 remain available for comparison. V0.22's PCB standoffs would overlap the pads of the real KSC2 land pattern; build V0.23. V0.21 should not be built: its Ø7 mm keys are too small for gloves and hard to press on the folded facet. V0.20 uses the Ruffy MHS panel joystick, which costs about £149 and fills the 23 mm pod width. V0.19 has a straight control face that gets in the way of the turn-signal switch, and no gasket. V0.18 is installable, but its cover does not match the housing and it has no cover, board, or gland mounting. V0.17 should not be printed: its 250-degree body cannot pass the handlebar. V0.13–V0.16 are superseded attempts at the shoulder silhouette and should not be printed. V0.13 left gaps at the shoulders. V0.14 dropped most of the pod through an incorrectly closed polygon. In V0.15 and V0.16 the same polygon traced the clamp arc as an inner boundary, so the fixed 250-degree ring was missing and only the removable cap surrounded the bar.

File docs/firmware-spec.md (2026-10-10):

# Firmware Specification — First BLE HID Prototype

**Status:** proposed implementation contract for the bench prototype. BLE pairing, key delivery, gesture timings, and every app profile remain unvalidated until tested with the purchased XIAO and real phones.

## 1. Purpose and scope

The first firmware should prove that the XIAO nRF52840 can read the temporary switches and operate as a Bluetooth remote with Android and iOS. It will expose standard keyboard input so supported apps can receive familiar key events. It will not depend on a companion phone app or a project-specific GATT service.

This is a bench prototype. It is not riding-ready and does not establish weather resistance, vibration resistance, or app compatibility.

## Product requirement: wireless firmware updates

The released remote must be updateable by the owner from an Android or iOS phone over Bluetooth LE, without connecting the remote to a computer. USB remains the power input; it must not be required as a data connection for routine updates.

The final hardware and firmware architecture must provide:

- A BLE DFU bootloader and a phone-based update workflow that is documented for both Android and iOS.
- A deliberate way to enter update mode, with the ordinary HID remote connection suspended during the update.
- Signed update packages, version/product checks, and a rollback-safe update design (preferably dual-bank: retain the last working image until the new image boots successfully).
- Recovery behavior for interrupted transfer or power loss. The device must not be left unusable if an update is interrupted; verify this experimentally before release.
- Publicly downloadable firmware packages and clear release notes. A dedicated companion app is not yet a requirement if an existing, maintained DFU app works on both phone platforms with the chosen bootloader.

### Important XIAO bootloader check

The XIAO is the right board for the first HID prototype, but do not assume its factory bootloader can perform BLE OTA updates. In a 2025 public response, Seeed said it did not have an official solution or documentation for Bluetooth DFU on the XIAO nRF52840. Treat OTA on this purchased XIAO as an investigation, not an available feature. Before choosing the final controller, verify the bootloader, update package format, Android app, iOS app, image authentication, and recovery path together.

Nordic provides a mobile DFU app for Android and iOS for nRF5 SDK bootloaders. Its documentation distinguishes that flow from nRF Connect SDK firmware, which uses the nRF Connect Device Manager app. Adafruit's nRF52 bootloader is another technical reference: it describes BLE OTA, signed updates, and optional dual-bank updates, but the XIAO is not listed among its officially supported boards. Porting a bootloader or changing the final controller may therefore be necessary. See [Nordic DFU mobile app](https://www.nordicsemi.com/Products/Development-tools/nRF-Device-Firmware-Update), [Nordic FOTA guide](https://nrfconnectdocs.nordicsemi.com/ncs/latest/nrf/app_dev/device_guides/nrf52/fota_update.html), [Seeed's XIAO bootloader discussion](https://github.com/Seeed-Studio/wiki-documents/discussions/2071), and [Adafruit nRF52 bootloader](https://github.com/adafruit/Adafruit_nRF52_Bootloader).

Do not replace or modify the XIAO bootloader during the initial BLE HID bring-up. First establish the input and navigation behavior, then test OTA on a spare development board so a failed bootloader experiment cannot interrupt the main prototype.

## 2. Development setup and upload workflow

The first firmware will be written and uploaded with **Arduino IDE 2** on a computer. The XIAO connects over a USB-C data cable; no separate programmer is required. Arduino IDE compiles the sketch for the selected XIAO board and uploads it over USB. Its Serial Monitor can show GPIO and BLE diagnostics during development.

1. Install and open [Arduino IDE](https://www.arduino.cc/en/software/).
2. In the IDE settings, add Seeed's board index URL: `https://files.seeedstudio.com/arduino/package_seeeduino_boards_index.json`.
3. Open Boards Manager, search for **Seeed nRF52 Boards**, and install it. Seeed recommends this board package for the XIAO's Bluetooth functions; use the standard nRF52 package rather than the mbed-enabled package for this BLE prototype.
4. Connect the pre-soldered XIAO to the computer with a USB-C **data** cable.
5. Select **Seeed XIAO nRF52840** under the Seeed nRF52 boards and choose the port that appears for the board.
6. Open the project's `.ino` sketch, use **Verify** to compile, then **Upload** to flash it. Pair the remote from the phone's Bluetooth settings after the HID firmware is running.

An initial diagnostic sketch is now available at [firmware/xiao-nrf52840/open-rally-remote.ino](../firmware/xiao-nrf52840/open-rally-remote.ino). It uses the Seeed nRF52 board package and its bundled Bluefruit HID keyboard API. It is a starting point. It compiles and implements the center chord below, but has not yet been checked on the purchased hardware.

Seeed's [XIAO nRF52840 guide](https://wiki.seeedstudio.com/XIAO_BLE/) documents Arduino IDE setup and the board package. Arduino's [IDE 2 board manager tutorial](https://docs.arduino.cc/software/ide-v2/tutorials/ide-v2-board-manager/) explains installing board support packages.

## 3. Bluetooth transport

- Implement the Bluetooth SIG **HID over GATT Profile (HOGP)** as a BLE peripheral.
- Present as a standard keyboard HID device; phones act as the BLE central and HID host.
- Use the standard keyboard report protocol with key-down and key-up reports. Do not send text strings or app-specific proprietary packets.
- Start with one bonded phone at a time. Reconnect to the last bonded host after power-up. Provide a documented way to clear the bond during development; choose the physical reset gesture after the first bench test.
- Use a stable, recognizable device name such as `Open Rally Remote` and a distinct manufacturer/product string if the selected library supports it.
- The current Seeed/Bluefruit `BLEHidAdafruit` convenience class uses a stock HID descriptor that includes keyboard, Consumer Control, and mouse collections. The diagnostic sketch sends keyboard reports only; it does not send media, mouse, or gamepad data. If the extra advertised collections affect phone pairing or app compatibility, replace this helper with a keyboard-only HID descriptor before treating the transport as validated. Do not add a custom GATT service to the first build.

HOGP is the Bluetooth SIG profile for exposing HID input over BLE/GATT. Android documents BLE central/GATT support, and OsmAnd documents keyboard input on Android and iOS. Those facts make this a sensible first path, but they do not guarantee every key or gesture works identically on every phone. See [Bluetooth SIG HOGP](https://www.bluetooth.com/specifications/specs/hid-over-gatt-profile-hogp/), [Android BLE overview](https://developer.android.com/develop/connectivity/bluetooth/ble/ble-overview), and [OsmAnd external input devices](https://www.osmand.net/docs/user/map/interact-with-map/).

## 4. Inputs and electrical behavior

| XIAO pin | Input | Released | Pressed |
|---|---|---|---|
| D0 | Button A | HIGH | LOW |
| D1 | Button B | HIGH | LOW |
| D2 | Button C | HIGH | LOW |
| D3 | Joystick up | HIGH | LOW |
| D4 | Joystick down | HIGH | LOW |
| D5 | Joystick left | HIGH | LOW |
| D6 | Joystick right | HIGH | LOW |
| D7 | Not used (reserved) | — | — |

Configure every connected input as `INPUT_PULLUP`. A closed switch joins the input to GND. Do not connect a switch input to 3.3 V or 5 V. D7 is not connected in the V0.22/V0.23 hardware and must be ignored.

The joystick has no separate center switch. Its stick sits on four C&K KSC2 switches (see the [joystick PCB](../electronics/joystick-pcb/README.md)); tilting closes one switch, or two adjacent ones on a diagonal, and pushing the stick straight in closes all four. The knob reaches its push stop only after every switch has tripped, so a full push always closes all four. The firmware derives the center input from this chord (section 5).

The final hardware may use a different pin map. Keep the pin assignments in one configuration table so they can be changed without rewriting input and HID logic.

## 5. Input processing and gesture rules

These values are initial tunable settings, not final ergonomic decisions:

| Setting | Initial value | Behavior |
|---|---:|---|
| Scan interval | 5–10 ms | Sample all inputs from one non-blocking loop or equivalent task. |
| Debounce | 30 ms | Accept a new stable state only after it remains unchanged for this interval. |
| Long-press threshold | 600 ms | Emit one long-press action when the control remains pressed for this duration. |
| Double-press window | 300 ms | Two short presses of the same control inside the window produce one double-press action. |

Gesture state machine for Buttons A, B, C, and the derived center input:

1. On a debounced press, record the start time; do not emit a key yet when short/double discrimination is active.
2. If the control is still down at the long-press threshold, emit its long action once. Suppress short and double actions for that press.
3. If it is released before the threshold, wait for the double-press window. A second debounced press of the same control inside the window cancels the pending short action and emits one double action after that second press is released (unless it becomes a long press).
4. If the window expires without a second press, emit one short action.
5. A second press of a different control does not cancel the first control's pending short action.

This means a short action can be delayed by up to the double-press window. Profiles that do not use double press may disable double recognition for the affected control and emit short actions on release. Record any profile-specific exception in the mapping table.

Center chord: treat the center as pressed when at least three direction inputs are closed, and released when none is. When a direction first closes, hold its key-down for a chord window (initially 40 ms, tunable). If three or more directions close inside the window, report the center press instead and send no direction keys until all four are released. Otherwise send the held directions as usual. Two opposite directions closed together can only come from a push, so they also suppress direction keys. The window delays direction key-down by up to its length; measure whether that is noticeable on hardware.

Joystick directions are held inputs: send the mapped key-down while the direction is held and the matching key-up on release. Do not synthesize repeated key-down reports in firmware. The host/app may repeat a held key; test whether this produces useful map panning and document device-specific behavior. Opposite directions pressed together should cancel each other. Other simultaneous directions must not corrupt the HID report.

Do not block the input scan while waiting for a gesture timeout. Keep a separate state and timer for each gesture-capable control so buttons can be used independently.

## 6. HID report behavior and reliability

- Every discrete action is a complete key press followed by a key release. Never leave a key logically held after a tap.
- Send a release report after each discrete press. Send an all-keys-released report after disconnect, profile change, reset, or any input-state recovery event.
- For held joystick directions, track each held direction and send the current set of keys, not unrelated successive key presses.
- Use a standard keyboard report with at least six-key rollover. The controls should not normally require more than four simultaneous direction keys, but verify combinations and gracefully handle the report limit.
- Do not emit a key repeatedly while a physical button remains held unless a tested app profile explicitly requires host key repeat.
- Ignore input events while BLE is disconnected, then resume cleanly after reconnect. Do not queue old actions for later delivery.
- Avoid unnecessary flash writes. Store profile/configuration only when it changes.

## 7. Profiles and mappings

The semantic app assignments below follow the project’s [control-mapping draft](control-mapping.md). A semantic action (for example, “reset partial odometer”) is not itself a HID keycode. The concrete HID usage for each action must be selected from the target app’s documented input options or discovered in a key tester, then verified on both phone platforms where the app is available.

| Profile | Button A | Button B | Button C | Joystick |
|---|---|---|---|---|
| TerraPirata | Short: reset partial odometer; long: lock/unlock screen | Short: increase the main odometer | Short: decrease the main odometer | Directions/center remain configurable pending TerraPirata mode validation. |
| OsmAnd | Short: change orientation (`D`) | Short: zoom in (`+`) | Short: zoom out (`-`) | Up/down/left/right: arrow keys; center short: current position (`C`). |
| DMD² / DMD Next | Short: map-follow toggle | Short: zoom in | Short: zoom out | Directions: pan; center initially unassigned. Configure emitted keyboard keys and any supported long-press action in DMD’s Generic Remote mapping. |
| Diagnostic | Short/long/double: `A`/`B`/`C` | Short/long/double: `D`/`E`/`F` | Short/long/double: `G`/`H`/`I` | Arrows while held; center short/long/double: `J`/`K`/`L`. |

The diagnostic profile uses ordinary letter keys only to make event identities easy to see in a keyboard tester. Do not use it while a navigation app is active because those letters may trigger app actions.

### Mapping limits to preserve

- **TerraPirata:** its official material recommends its dedicated remote mode or app compatibility mode, including for iOS. Do not claim generic HID equivalence until the physical events and mode have been tested. Its dedicated mode’s exact key usages for this DIY remote are currently unknown.
- **OsmAnd:** its current docs list `C` for current position, `D` for map orientation, arrow keys for map movement, `+`/`=` for zoom in, and `-` for zoom out. A `+` may be represented by the HID `Equal` usage with Shift, depending on keyboard layout; validate the actual output on Android and iOS. The long-press `N`/`S`/`M` actions proposed in the mapping draft are candidates only, not defaults in this first implementation. Double actions remain configurable and have no default mapping.
- **DMD² / DMD Next:** the project mapping is A follow toggle, B zoom in, and C zoom out. DMD documents generic keyboard/HID remote mapping, but generic remotes do not receive all features of its own remotes; in particular, do not promise native double-tap behavior. DMD² is Android-only according to its current FAQ.

For the first firmware build, compile-time profile selection is sufficient. Do not implement a mode-change gesture until a physical UI has been agreed and tested; this avoids accidental mode changes while riding. The diagnostic profile should be available even if app-specific mappings are unfinished.

## 8. Initial implementation phases

1. **GPIO and BLE proof:** upload the [initial diagnostic sketch](../firmware/xiao-nrf52840/README.md), pair Android and iOS separately, and confirm every connected switch reports the expected key. Validate active-low behavior, the center chord, and key release.
2. **Gesture proof:** measure short/long/double recognition with the temporary switches. Adjust timings only after the initial values have been observed on hardware.
3. **Reliability check:** test reconnect, held arrows, opposing direction cancellation, and release behavior after disconnect.
4. **App mapping:** implement semantic profiles and bind tested HID usages to each action. Keep unverified bindings marked experimental.
5. **Bench compatibility:** complete the [validation matrix](control-mapping.md#bench-validation-matrix) and record phone, OS, app version, profile, actual key event, and action result.

## 9. Validation checklist

| Area | Pass condition | Android | iOS |
|---|---|---|---|
| Pairing | Appears as a keyboard/HID remote, pairs, and reconnects to the bonded phone | Pending | Pending |
| Input scan | Each of D0–D6 works once; D7 is ignored | Pending | Pending |
| Debounce | One press produces one event; switch bounce produces no duplicates | Pending | Pending |
| HID release | Every discrete key has a matching release; disconnect cannot leave a key stuck | Pending | Pending |
| Directions | Held arrows pan as expected; release stops movement; opposing directions cancel | Pending | Pending |
| Gestures | Short, long, and double are distinct at the chosen thresholds; no dropped/doubled action | Pending | Pending |
| TerraPirata | Required remote/compatibility mode accepts each mapped action | Pending | Pending |
| OsmAnd | A/D, B/+, C/−, arrows, and center/C perform the intended actions | Pending | Pending |
| DMD² | A follow, B zoom in, C zoom out, and joystick pan work through Generic Remote mapping | Pending | N/A |
| Center chord | A straight push gives one center event and no direction keys; tilts and diagonals give no center event | Pending | Pending |

## Product OTA validation checklist

| Test | Pass condition | Android | iOS |
|---|---|---|---|
| Phone-only update | Install a published update package over BLE without a computer or USB data connection | Pending | Pending |
| Image authentication | Reject an unsigned, corrupted, or wrong-product image | Pending | Pending |
| Interrupted transfer | Disconnect BLE or remove power during transfer; recover automatically to the existing or update-ready state | Pending | Pending |
| Failed first boot | A broken new application image rolls back to the previous working firmware | Pending | Pending |
| Version handling | Reject downgrade or incompatible version unless a deliberate recovery procedure is used | Pending | Pending |
| Normal use after update | Reconnect as a HID remote and retain the user's selected profile and settings | Pending | Pending |

## References

- [Seeed Studio: XIAO nRF52840 Arduino setup and examples](https://wiki.seeedstudio.com/XIAO_BLE/)
- [Arduino: IDE 2 board manager tutorial](https://docs.arduino.cc/software/ide-v2/tutorials/ide-v2-board-manager/)
- [Nordic: nRF Device Firmware Update mobile app](https://www.nordicsemi.com/Products/Development-tools/nRF-Device-Firmware-Update)
- [Nordic: FOTA update on nRF52](https://nrfconnectdocs.nordicsemi.com/ncs/latest/nrf/app_dev/device_guides/nrf52/fota_update.html)
- [Seeed: public XIAO nRF52840 Bluetooth DFU discussion](https://github.com/Seeed-Studio/wiki-documents/discussions/2071)
- [Adafruit: nRF52 bootloader and OTA features](https://github.com/adafruit/Adafruit_nRF52_Bootloader)
- [Bluetooth SIG: HID over GATT Profile](https://www.bluetooth.com/specifications/specs/hid-over-gatt-profile-hogp/)
- [Android Developers: Bluetooth Low Energy overview](https://developer.android.com/develop/connectivity/bluetooth/ble/ble-overview)
- [OsmAnd: external input devices and keyboard key assignments](https://www.osmand.net/docs/user/map/interact-with-map/)
- [TerraPirata: Bluetooth remote compatibility](https://terrapirata.com/bluetooth-remotes/)
- [HesaParts NAVCOMM user manual](https://hesaparts.com/wp-content/uploads/2025/02/EN/NAVCOMM%20USER%20MANUAL.pdf)
- [DMD²: devices and generic remotes](https://docs.dmdnavigation.com/dmdnext/devices/)
- [DMD² FAQ: generic-remote behavior](https://docs.dmdnavigation.com/faq/)

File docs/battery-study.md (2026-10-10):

# Battery Power and Removable Remote — Study

This study looks at battery power for the remote and at [issue #1](https://github.com/chirauki/open-rally-remote/issues/1), a removable remote on a fixed handlebar base. It starts from V0.23 ([mechanical notes](mechanical-concept.md), [joystick PCB](../electronics/joystick-pcb/README.md)). No CAD has changed yet; the fits below are 2D checks against the V0.23 geometry.

**Status:** study only. Nothing here has been built or measured.

## Direction chosen

Decided on 2026-10-10, after the first version of this study:
- **The main goal of issue #1 is to share one remote between several bikes.**
- **No wiring to the bike.** The remote runs on its own battery only.
- **Removable remote or swappable battery, not both.** Each one alone solves the battery problem; together they add a second seal, a second wear point and pod length for little gain.
- **Therefore: a removable remote with a fixed LiPo pouch**, on a [bayonet around the bar](#removable-remote-issue-1) with one base per bike. It is charged off the bike through [sealed contacts](#charging-without-bike-wiring) on its back.
- The swappable 16340 is not pursued. Its analysis stays below as the alternative for a remote that stays on one bike.

Next steps wait for parts and measurements; see [Open measurements](#open-measurements).

## Summary

- The V0.23 cavity has no room for a swappable cell. The free spaces are about 14 × 19 × 20.6 mm behind buttons A and B, and a 13 × 26 mm strip (in the plane of the clamp) in the solid shoulder between the cavity and the clamp ring.
- A flat 6 × 20 × 22 mm LiPo, not swappable, fits in V0.23 without growing the housing. It crosses the cavity rear wall into the shoulder. It still fits when the ring keep-out grows by up to 6 mm for the removable remote's saddle.
- A swappable 16340 (RCR123A) cell needs a 20 × 44 mm footprint, including its tube and cap. That fits only if the upper end of the pod grows from 44 to about 64 mm above the bar axis, which makes the pod 20 mm longer.
- The XIAO nRF52840 already has a LiPo charger and battery pads. It cannot take a primary cell (CR2450, CR123A) safely, because it would try to charge it.
- A twist mount like a bike-computer quarter-turn does not suit this remote: the twist would swing the 85 mm pod across the bar into the grip and switchgear. A bayonet that turns around the bar keeps the remote in its 23 mm slot.

## What the XIAO nRF52840 provides

From Seeed's XIAO nRF52840 V1.2 KiCad project, exported to a netlist with KiCad 10:

| Function | Circuit |
|---|---|
| Charger | TI BQ25101 linear charger, from VBUS. ISET is 2.7 kΩ, about 50 mA, with a second 2.7 kΩ to P0.13 (`HICHG`): drive P0.13 low for about 100 mA. Seeed lists 50/100 mA. |
| Battery pads | `BAT` pad, on the BQ25101 output. |
| Power path | A MOSFET (LP0404N3T5G) with its gate on VBUS connects the battery to VIN when VBUS is absent. With VBUS present, VIN comes from VBUS through a Schottky diode (SDM20U40), and the battery only charges. |
| Regulator | SGM2040 3.3 V LDO, 250 mA, from VIN. |
| Battery voltage | 1 MΩ / 510 kΩ divider from VBAT to P0.31 (AIN7), switched by P0.14 (`READ_BAT`, active low). |
| Charge status | BQ25101 `CHG` to P0.17, and a charge LED. |
| 5V header pin | Same net as USB-C VBUS, with nothing between them (see the [joystick PCB notes](../electronics/joystick-pcb/README.md#circuit)). |

Consequences:
- **A rechargeable Li-ion or LiPo cell on the `BAT` pad is charged whenever the 5V pin or USB-C has power.** The charger enable is not wired to a GPIO, so the firmware cannot turn charging off.
- **A primary lithium cell (CR2450, CR2477, CR123A) must not go on the `BAT` pad.** The charger would try to charge it whenever 5 V is present. A coin-cell design like the Remotek One needs its own board without a charger.
- With 5 V present (charge contacts or USB-C), the remote runs from 5 V and charges the cell at the same time.

## Battery options

| Cell | Size | Capacity | Swappable | Fits V0.23 | Pod growth |
|---|---|---|---|---|---|
| LiPo pouch with protection board (for example 602020) | about 6 × 20 × 22 mm | about 180–250 mAh in listings | No | Yes, across the cavity rear wall | None |
| 16340 / RCR123A Li-ion, protected | Ø16.5–17 × 33.8–36 mm | 650–950 mAh in manufacturer listings | Yes | No | Top end 44 → about 64 mm |
| 14250 Li-ion (½ AA) | Ø14–14.5 × 25–26 mm | 300–600 mAh, vendor claims only; no manufacturer datasheet found | Yes | No | Top end 44 → about 56 mm |
| 10440 Li-ion (AAA size) | Ø10.5 × 44.5 mm | about 350 mAh (typical, not verified) | Yes | No | Top end 44 → about 64 mm |
| CR2450 coin cell | Ø24.5 × 5 mm | about 620 mAh (typical, not verified) | Yes | No | Not usable with the XIAO |

The 16340 was the candidate for a swappable cell, before the [direction chosen](#direction-chosen) dropped it:
- **Capacity.** It holds three to four times the energy of the pouch that fits.
- **Supply.** Protected 16340 cells and their chargers are sold for flashlights.
- **Sealing.** A screw cap with an O-ring, as on a flashlight, is a well-proven sealed battery closure.

The 16340 is the same size as the primary CR123A (3 V). A CR123A in the remote would be charged by the XIAO; see [Risks](#risks).

### Fit method

The checks use the V0.23 2D profiles in the plane of the clamp, with these keep-outs:
- a 1 mm outer wall;
- 1.5 mm around the clamp ring;
- the XIAO with its pins and rails;
- the buttons, plus 5 mm behind them for wires;
- everything below the fold.

The cell's footprint, including its tube and cap, is searched over positions and angles in 5° steps. The cell's diameter runs along the bar. A 17–20 mm tube fits in the 23 mm width, leaving 1.5–3 mm of wall on each side.

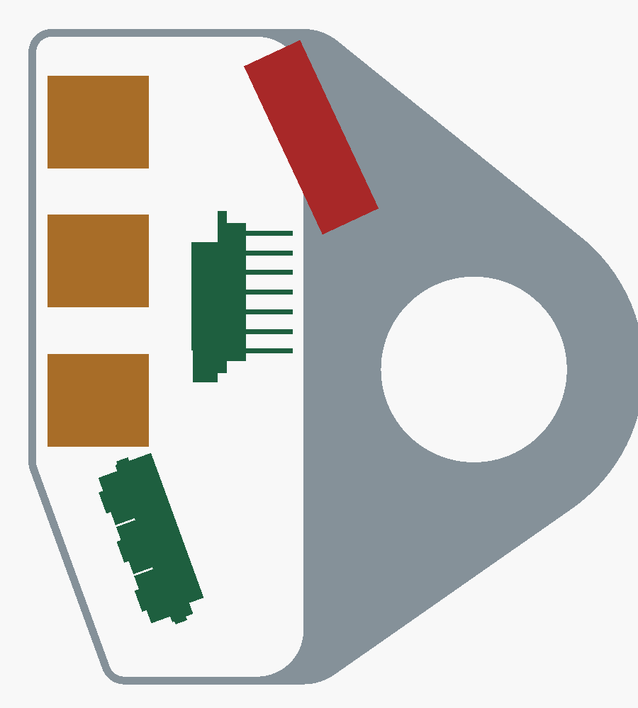
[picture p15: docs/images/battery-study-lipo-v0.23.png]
V0.23 profile with a 6 × 20 × 22 mm LiPo pouch (red, 8 × 24 mm footprint with clearance) in the free space behind the XIAO pins, crossing the cavity rear wall into the shoulder. Buttons in orange, XIAO and joystick PCB in green.


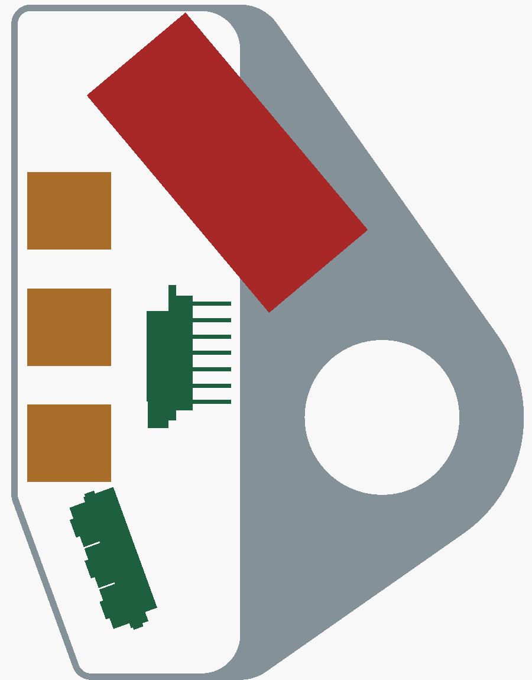
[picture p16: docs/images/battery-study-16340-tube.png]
The same profile with the top end raised to 64 mm: a 16340 tube (red, 20 × 44 mm footprint) runs diagonally from behind button A into the upper shoulder. The cap end can open on the shoulder face.


For the removable remote, the same search was rerun with the ring keep-out grown to leave room for a saddle around the ring:

| Extra radial keep-out around the ring | 8 × 24 mm (6 mm pouch) | 10 × 24 mm (8 mm pouch, same outline) | 8 × 34 mm or longer |
|---|---|---|---|
| 0 mm (V0.23) | Fits, at −65° | Fits, at −60° | No fit |
| 4 mm | Fits, at −45° | Fits, at −25° | No fit |
| 6 mm | Fits, at −20° | Not checked | Not checked |

An 8 mm thick pouch of the same 20 × 22 mm outline would hold more charge; its capacity has not been checked against a listing. A pouch longer than about 25 mm does not fit above the fold. The pouch is 20 mm along the bar, inside the 21 mm cavity of the 23 mm part.

The 16340 tube runs diagonally, at 50° to the bar-to-cover direction, from the top of the cavity into the upper shoulder. The cap end can open on the shoulder face, where it can be reached with the remote on the bar. Growing the top end by 20 mm has not been checked against the bike: mirrors, brake reservoir and switchgear. It needs measuring before CAD work.

## Power architecture

Two ways to connect the cell:

| | A: cell on the XIAO `BAT` pad | B: cell into the 5V pin through a diode |
|---|---|---|
| Charging | On board, at 50 or 100 mA, from the charge contacts or USB-C; a 16340 could also go in an external charger | External charger only |
| Voltage loss | Only the MOSFET | Two Schottky drops, ours and the XIAO's (about 0.4–0.6 V together). At 3.0 V the 3.3 V rail falls to about 2.5 V. |
| Primary CR123A | Unsafe: it gets charged | Allowed, but only with a diode that blocks any charge current |
| Battery voltage reading | Built-in divider on AIN7 | Needs a divider on another pin |

**Recommendation: A, with rechargeable cells only.** It needs no extra parts and keeps the full voltage. A 250 mAh pouch takes about 5 h at 50 mA or 2.5 h at 100 mA; a 900 mAh 16340 would take about 18 h or 9 h.

The 100 mA rate should be checked against the cell's maximum charge current. The listings above do not all give a maximum charge current; check the chosen cell's datasheet.

## Runtime estimate

There is no measurement on this firmware yet; the BLE current of the XIAO with Bluefruit is the main unknown. The published figures found:
- XIAO with Arduino/Bluefruit sleep: about 22 µA, measured by a forum user.
- System OFF: 2–3 µA.
- An nRF52840 connected over BLE: from about 0.2 mA (power-profiler estimate at a 40 ms interval) to about 1 mA (a forum report).

| Average current | 250 mAh pouch | 900 mAh 16340 |
|---|---|---|
| 1 mA (connected, short interval) | 10 days | 37 days |
| 0.3 mA (connected, with peripheral latency) | 35 days | 125 days |

These are continuous-connection figures. With the firmware sleeping while the bike is parked and reconnecting on a press, the runtime would be much longer. Measure before choosing a cell; see [Firmware](#firmware).

## Sealing

| Opening | Seal | Risk |
|---|---|---|
| Battery tube cap (new) | Radial O-ring on a smooth land inside the tube mouth, not on the thread | An FDM bore is rough and slightly oval; the land may need reaming, a glued-in sleeve, or a printed and sanded land. Measure leakage on a test piece. |
| Cap electrical contact | Spring in the cap on the cell's negative end, closing through a contact ring at the tube mouth inside the O-ring | The contact and its wire stay inside the seal. Contacts corrode if water gets past the O-ring. |
| Cable gland (current) | Unchanged, if the cable stays | — |

The tube is a separate sealed volume from the electronics cavity. Only two wires pass from the tube into the cavity, sealed when printed or potted. A leak at the cap then wets the cell and its contacts, not the boards.

## Removable remote (issue #1)

A concept, not yet modelled. The goal is to move one remote between bikes without tools. Each bike keeps its own base.

### Split

- **Base.** A clamp ring that stays on the bar, with two halves and two M4 bolts as now. It has no electronics. Bases come in variants for each bar size; see [Universal fit](#universal-fit).
- **Remote.** The pod, the two shoulders, the XIAO, the joystick PCB and the LiPo pouch. Its back is a saddle around the front of the base ring.

### Why a bayonet around the bar

A twist mount turns the device about an axis normal to its mating face. On this remote that face lies between the ring and the pod, so the axis is in the plane of the clamp. A quarter turn about it swings the pod's 85 mm length across the bar, into the grip, levers and switchgear, where the manual gives only 23 mm of free bar.

A dovetail sliding in the plane of the clamp avoids that sweep. It needs a flat platform on the round ring, which adds material and pushes the pod away from the bar.

A bayonet that turns around the bar axis keeps the remote in its 23 mm slot, uses the round ring directly, and stays in the plane the pod already occupies.

### Bayonet

- **Base.** The ring carries two short circumferential lugs on its outer surface.
- **Remote.** The saddle has a matching inner groove with an entry gap for each lug. It wraps no more than 180°, so it can go on over the ring from the front.
- **Fitting.** Offer the remote to the ring turned by an entry angle, with the lugs in the gaps. Push it home and turn it about the bar to its working position. The lugs slide under the groove lips, which hold the remote against pull-off.
- **Stops.** A hard stop ends the turn. A steel spring plunger in the saddle drops into a notch in the ring and stops it turning back. A printed spring would wear and creep, so the spring must be steel.
- **Release.** Pull the plunger knob and turn the remote back to the entry angle.
- **Tether.** A short lanyard from the remote to the base or the bar keeps a remote that comes loose off the trail.

### Loads

Button presses and joystick pushes make a torque about the bar axis:
- Buttons A and B are on one side of the bar axis, at Y = 32 and 14 mm.
- Button C (Y = −4 mm) and the joystick, below the fold, are on the other side.

So presses load the bayonet in both directions. Put the hard stop on the side of A and B, the most used buttons. The plunger then takes the torque from the joystick and button C, plus shocks and vibration. Size the plunger force and the notch angle for that, and test both off the bike before riding.

Pull-off loads go into the lugs and groove lips. Their strength in printed PETG or ASA has not been checked. Layer direction matters: the lips should not split along a layer line.

### Geometry to check in CAD

- **Radial build.** Today the clamp ring is 10 mm thick, from the Ø24 mm bore to Ø44 mm. Either the base ring stays at Ø44 mm and the saddle sits outside it, or the ring gets thinner and the saddle takes part of its section.
  - **Saddle outside a Ø44 mm ring.** The pod moves out by the saddle thickness (about 3–4 mm). That changes reach to the turn-signal switch, which set the 20° fold. The pouch still fits; see [Fit method](#fit-method).
  - **Thinner ring.** The clamp loses section, and its strength is not validated even now.
- **Width.** Lugs, groove and plunger must stay inside 23 mm along the bar.
- **Entry angle.** The remote turns through the entry angle near the brake lever, reservoir and mirror. A small angle (20–30°) sweeps less but gives shorter lugs. See [Universal fit](#universal-fit) for the release direction.
- **Angle setting.** Today the rider sets the pod angle by turning the clamp before tightening. With a base, the angle is set by turning the base before tightening; the bayonet then always returns to the same angle.

## Charging without bike wiring

The remote is charged off the bike. The XIAO USB-C socket is inside the pod and can only be reached with the cover off, which disturbs the gasket. It stays for firmware recovery only.

- **Charge contacts.** Two pads or a 2-pin magnetic pogo connector on the remote's back, inside the saddle. They are wired to the joystick PCB 5 V input and GND in place of the bike cable, so they go through its TVS diode and PTC fuse to the XIAO 5V pin.
- **Covered when mounted.** On the base the contacts face the ring, out of the rain and mud.
- **Dead when off the charger.** The XIAO feeds VIN from VBUS through a Schottky diode, and the battery reaches VIN through the power-path MOSFET. Neither path drives VBUS, so the pads carry no voltage when the remote runs on its battery. They cannot corrode from bias, and shorting them does no harm. This comes from the netlist and has not been measured.
- **Charger.** A matching magnetic USB cable, or a small charging dock printed to the saddle shape with two spring pins.
- **No cable gland.** The bike cable goes, so the gland and its lock nut go too. The gland lock nut set the 20° fold limit. The freed space at the bottom of the pod has not been searched for a larger cell.

Points to solve:
- **Sealing.** The pads or connector are a new sealed feature on the remote's back wall. Moulded-in pads or a connector with its own seal, potted from inside.
- **Reverse polarity.** A magnetic connector is keyed; bare pads are not. On the joystick PCB a reversed supply makes the TVS diode D1 conduct and the PTC fuse F1 trip ([joystick PCB notes](../electronics/joystick-pcb/README.md#circuit)). So a reversed charger should not reach the XIAO, but it heats D1 and F1 until it is removed. Prefer a keyed connector or a keyed dock.
- **USB-C and pads together.** Both are the XIAO VBUS net. Do not connect both at once; with the cover off on the bench this is the user's care.

## Universal fit

The remote is meant for any bike, so the design cannot rely on measuring bikes. The rule is: **the remote is one universal part; everything that varies between bikes goes into the base.**

- **Bar diameter.** The remote never touches the bar. Each bar size gets its own base: a bore and liner for 22.2 mm (7/8 in) bars, and a variant for 25.4 mm (1 in) bars. Tapered 28.6 mm bars come down to 22.2 mm at the controls, where the remote sits. The liner takes up tolerance, as now.
- **Width.** 23 mm along the bar, from the NAVCOMM manual's minimum free space between grip and switchgear, as now. It is an assumption taken from that manual, not a survey of bikes.
- **Side.** The remote goes on the left side of the bar only, never the right. One remote and one base handedness are enough; nothing needs mirroring.
- **Entry sweep.** The remote stays in its 23 mm slot while it turns, so only parts that cross that slot can be hit. On the left side the likely one is the clutch lever blade, or the rear brake lever on scooters, which runs in front of the grip. So:
  - keep the entry angle small (20–30°);
  - turn the remote toward the rider to release it, away from the lever blade;
- **Angle setting.** The rider sets the remote angle by turning the base on the bar before tightening, as with the clamp today.

Not all bikes can be covered this way. A bike with less than 23 mm between grip and switchgear, or with a lever that crosses the slot close to the bar, will need its own base or will not take the remote. That limit should be stated in the user notes.

## Open measurements

These are bench measurements on the parts, not on bikes:
1. **Current.** Average current of the XIAO with this firmware, connected over BLE and idle, with a multimeter in series on the battery lead. It decides whether a 250 mAh pouch is enough.
2. **Pouch.** The chosen pouch's real thickness, outline and protection board, and its maximum charge current against the XIAO's 50 or 100 mA.

## Firmware

- **Battery level.** Read AIN7 with P0.14 low. Report it over the BLE Battery Service; Bluefruit has `BLEBas`. Warn below about 3.5 V. Go to System OFF below about 3.3 V, ahead of the cell's protection cut-off.
- **Charging.** Read P0.17 (`CHG`). Drive P0.13 low for 100 mA only if the cell allows it.
- **Charger present.** The nRF52840 VBUS pin is on the same net as the 5V pin. Its USB power events can tell the firmware that the charge contacts are powered, for example to show charging or to stop advertising while on the charger.
- **Sleep and wake.** When parked, or idle for a set time, go to System OFF and wake on any button or joystick switch through GPIO sense. Measure how long a bonded phone takes to reconnect, and whether the first press after wake is lost.
- **Connection parameters.** Measure average current against connection interval and peripheral latency, against the input delay the rider notices.

## Risks

- **Primary CR123A in the 16340 tube.** It is the same size as the RCR123A, and with architecture A the XIAO would charge it whenever 5 V is present. Charging a primary lithium cell can make it vent or catch fire. Mark the tube "Li-ion 3.7 V only", and document it in the assembly and user notes. There is no electrical way to refuse a CR123A with architecture A.
- **Unprotected cells.** The BQ25101 is a charger, not a protection circuit. Use protected 16340 cells only.
- **Heat.** A black remote in the sun can pass 45 °C, the usual maximum for charging Li-ion. The BQ25101 TS input is fixed by a resistor on the XIAO, so the XIAO has no cell temperature cut-off. Check the cell's charge temperature range.

With the fixed pouch chosen, the CR123A risk goes away: the pouch is soldered in and nobody can swap it for a primary cell. It applies again only if the 16340 alternative is taken up.

## Decisions

Made:
1. Removable remote with a fixed LiPo pouch; no swappable cell.
2. Architecture A: the pouch on the XIAO `BAT` pad, charged on board.
3. No bike wiring and no base contacts. The base is mechanical only.

Still open, after the [measurements](#open-measurements):
1. Pouch size: 6 mm or 8 mm thick.
2. Saddle outside the Ø44 mm ring, or a thinner ring.
3. Bare pads or a magnetic connector for charging.

## Sources

- Seeed XIAO nRF52840 [wiki](https://wiki.seeedstudio.com/XIAO_BLE/) and [V1.2 KiCad project](https://files.seeedstudio.com/wiki/XIAO-BLE/Res/260828_Seeed_Studio_XIAO_nRF52840_v1.2.zip) (charger, power path, divider and pin nets).
- 16340 cells:
  - [Keeppower ICR16340 datasheet (NKON)](https://www.nkon.nl/en/amfile/file/download/file/138/product/4135);
  - [Keeppower RCR123A 950 mAh](https://illumn.com/16340-keeppower-950mah-rcr123a2-protected-button-top.html);
  - [Nitecore NL169](https://www.batteryjunction.com/nitecore-nl169);
  - [Olight 16340 test](https://budgetlightforum.com/t/test-review-of-olight-16340-rcr123a-650mah-cyan/38182).
- 14250 cells:
  - [1/2 AA vs 14250](https://batteryequivalents.com/1-2-aa-battery-vs-14250-battery.html);
  - [14250 3.7 V listing](https://makerselectronics.com/product/rechargeable-li-ion-battery-14250-1-2-aa-3-7v-600mah/).
- LiPo pouch listings:
  - [502030, 250 mAh](https://probots.co.in/3-7v-250mah-lipo-battery-502030-open-ended.html);
  - [402025, 150 mAh](https://probots.co.in/3-7v-150mah-lipo-battery-402025-open-ended.html).
- Current figures:
  - [XIAO BLE drawing 570 µA with Zephyr (Nordic DevZone)](https://devzone.nordicsemi.com/f/nordic-q-a/97377/xiao-ble-drawing-570ua-with-zephyr);
  - [nRF52840 battery life estimation (Nordic DevZone)](https://devzone.nordicsemi.com/f/nordic-q-a/63521/nrf52840-battery-life-estimation);
  - [Current consumption for BLE nRF52840 (Nordic DevZone)](https://devzone.nordicsemi.com/f/nordic-q-a/122135/current-consumption-for-ble-nrf52840);
  - [Zephyr XIAO nRF52840 low power](https://github.com/qarnet/Zephyr-XIAO-nRF52840-Ultra-Low-Power).
- [Remotek One](https://www.remotek.no/product-page/remote1) (CR2450, "will last for years"; no current or interval published).

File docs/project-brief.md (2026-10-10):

# Open Rally Remote — Initial Project Brief

## Goal

Design a wireless motorcycle handlebar remote for navigation and roadbook use that is repairable and reproducible by individual makers. The project will publish a complete set of designs so anyone can build one unit for themselves; it is not intended for large-batch production.

Priorities are reliable operation with riding gloves, resistance to rain, dust, and vibration, compatibility with Android and iOS where supported by each app, minimal handlebar space, and low cost without sacrificing reliability.

The Hesa Parts NAVCOMM is a functional reference for a Bluetooth navigation/roadbook remote. This project will create an original design and will not copy its industrial design or firmware.

## Proposed first version (V0)

- Three physical buttons and a joystick as the lowest control. The joystick provides directional input for map or roadbook interaction and has a center press. To preserve a lower-cost option, evaluate two build variants: a joystick with center press and one without. The PCB and firmware should support both variants, with the center-press function disabled when the switch is absent, subject to finding compatible parts and comparing their cost and durability.
- Each of the three buttons supports distinct short-press, long-press, and double-press actions. The joystick center press, when fitted, can also be configured for all three gestures. Joystick directions are separate events.
- Standard BLE HID keyboard input with firmware key profiles. One key map cannot guarantee compatibility with every app, so evaluate profiles for TerraPirata, OsmAnd, DMD² on Android, and a generic keyboard profile, with remapping where feasible.
- A low-power BLE microcontroller module with an integrated antenna. Compare nRF52 and ESP32-C3 options before selecting components.
- Main power from a motorcycle USB outlet at 5 V. The USB connector stays at the outlet end of a cable that enters the remote through a sealed cable gland, avoiding an exposed USB port on the enclosure. Include suitable input protection. A replaceable battery may be considered as a standalone variant after measuring actual power use and runtime. Direct 12 V input may be considered for a future variant.
- A simple two-layer PCB, locking connectors, and mechanical strain relief.
- A two-piece printable enclosure for prototypes; a final design should use a perimeter gasket and sealed buttons. A 3D-printed enclosure alone is not proof of waterproofing.
- A modular handlebar mount for a 22 mm tube in the control area. Builders will need to check clearance with their stock controls and levers.
- The remote mounts on the left side of the handlebar only, between the grip and the left switchgear. There is no right-hand version.

## Expected compatibility and known limits

| App | Platform | Integration to validate | Scope note |
|---|---|---|---|
| TerraPirata Rally Roadbooks | Android and iOS | Dedicated TerraPirata profile and short/long/double press events | The app documentation describes broad remote compatibility and recommends TerraPirata mode. On iOS, it calls for that mode or the app's compatibility mode. |
| OsmAnd | Android and iOS | Configurable keyboard/external-device profile | OsmAnd documents external keys and custom assignments on both platforms. Available actions and behavior must be checked by app version and OS. |
| DMD² / DMD Next | Android | Generic HID keyboard profile and in-app key mapping | DMD² documents support for generic keyboard/HID remotes. The DMD² navigation app is Android-only; do not claim iOS navigation support. |
| Other apps | Android and iOS | Generic BLE HID keyboard profile; additional community profiles | Each app decides which input events it accepts. Universal app control cannot be guaranteed. |

The remote will interpret short, long, and double presses locally and emit clear HID events. Validation must check that gestures do not generate duplicate or conflicting events.

## Installation requirement

The remote project does not include or install the motorcycle's USB outlet. The builder must provide a suitable 5 V USB outlet; the remote receives power through its sealed cable.

## Firmware update requirement

The finished product must let its owner install firmware updates over Bluetooth LE from an Android or iOS phone, without connecting the remote to a computer. Updates must use authenticated firmware packages and a recovery-safe bootloader that can retain or restore the last working firmware if an update is interrupted or fails. This is a product requirement, not a requirement for the USB-powered bench prototype. The XIAO nRF52840 remains suitable for initial HID experiments, but its bootloader's BLE update path must be verified before selecting it or a related module for the final design.

## Design and component selection criteria

1. Prefer parts available from more than one supplier and backed by public datasheets.
2. Compare total BOM cost, including 5 V input protection, cable and sealed cable gland, enclosure sealing, mount, and assembly—not just the microcontroller.
3. Minimize the remote's width and volume on the handlebar while avoiding interference with stock controls and keeping it usable with gloves.
4. Keep the design buildable with common tools: two-layer PCB, hand soldering, and a printable enclosure.
5. Design for rain, dust, vibration, and gloved operation. Define tests before claiming an IP rating.
6. Keep electronics replaceable and publish editable source files, manufacturing files, and a BOM with alternatives.
7. Select the final controller and bootloader with secure BLE updates from both Android and iOS in mind; weigh the update flow and recovery strategy alongside module price and size.

## Planned open deliverables

- Editable schematic and PCB files, Gerbers, and a BOM with alternatives.
- Firmware, build and update instructions, and button-remapping guidance.
- Parametric CAD for the enclosure, buttons, and mount, plus printable STL files.
- Assembly, verification, and troubleshooting guides.
- Single-unit build instructions covering tools, part alternatives, solder points, and step-by-step checks.
- Explicit licenses for hardware, firmware, and documentation.

## Individual build and fit

The project targets individual builders: anyone should be able to assemble one unit from the published files and guide. The process will not be designed around mass production.

The variety of gloves, handlebars, and stock control assemblies is open-ended and cannot be captured by one fixed requirement. The design will aim for a compact shape and controls usable with motorcycle gloves. Published dimensions and editable models will let each builder check fit on their own bike and adapt the mount. Ergonomics will be evaluated against representative examples without claiming universal fit.

## Development plan

1. Review the [draft control mapping](control-mapping.md) and validate app-specific button actions.
2. Build the bench proof of concept in the [prototype plan](prototype-plan.md); compare BLE controllers, switches, sealed cable entry, and input protection using current prices and availability.
3. Prototype BLE HID profiles and validate them on real Android and iPhone devices with TerraPirata, OsmAnd, and DMD².
4. Design the PCB and 22 mm mount/enclosure; check ergonomics and installation on a motorcycle.
5. Prototype a signed BLE firmware-update workflow on Android and iOS, including interruption and rollback recovery.
6. Iterate through water, dust, vibration, drop, and USB power tests. Document results and limits before making any protection rating claim.

## Reference documentation

- [Hesa Parts NAVCOMM](https://hesaparts.com/product/navcomm/)
- [TerraPirata Rally Roadbooks](https://terrapirata.com/rally-roadbooks/)
- [OsmAnd external input devices](https://www.osmand.net/docs/user/map/interact-with-map/)
- [DMD² devices and generic remotes](https://docs.dmdnavigation.com/dmdnext/devices/)
- [DMD² FAQ: iOS support](https://docs.dmdnavigation.com/faq/)

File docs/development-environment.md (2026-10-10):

# Development Environment — XIAO nRF52840

**Status:** setup guide for the first bench prototype. An initial diagnostic sketch is available; it still needs to be uploaded and verified on the purchased hardware.

## What you need

- A computer running Windows, macOS, or Linux.
- [Arduino IDE 2](https://www.arduino.cc/en/software/).
- A USB-C cable that supports data transfer (a charge-only cable will power the XIAO but cannot upload code).
- The purchased Seeed Studio XIAO nRF52840 with its headers already soldered.
- An internet connection for the initial IDE and board-package installation.

No separate programmer, phone app, Python installation, or PlatformIO setup is needed for the first prototype. The phone is used later to test Bluetooth; firmware is uploaded from Arduino IDE over USB.

## Install Arduino IDE and Seeed board support

1. Install and open Arduino IDE 2 from the [Arduino software page](https://www.arduino.cc/en/software/).
2. Open the IDE settings/preferences and add this URL to **Additional Boards Manager URLs**:

   ```text
   https://files.seeedstudio.com/arduino/package_seeeduino_boards_index.json
   ```

3. Open **Boards Manager**, search for **Seeed nRF52 Boards**, and install the latest stable version offered by the manager. Record the installed version so firmware builds can later be reproduced.
4. Connect the XIAO to the computer with the USB-C data cable.
5. In **Tools → Board**, select **Seeed nRF52 Boards → Seeed XIAO nRF52840**. Do not select the Sense or Plus model; the purchased board is the standard nRF52840 model.
6. In **Tools → Port**, select the port that appears when the XIAO is connected. If unsure, note the list, unplug the board, and see which port disappears; reconnect it and select that port.

Seeed recommends its **Seeed nRF52 Boards** package for Bluetooth functions. Its package includes the Adafruit Bluefruit nRF52 examples, including a BLE HID keyboard example, so a separate BLE library should not be necessary for the first HID experiment. Seeed's [XIAO nRF52840 guide](https://wiki.seeedstudio.com/XIAO_BLE/) and [Bluetooth usage guide](https://wiki.seeedstudio.com/XIAO-BLE-Sense-Bluetooth_Usage/) describe this setup.

## Confirm the computer can upload code

Before wiring the switches, confirm the environment with a simple example:

1. In Arduino IDE, open **File → Examples → 01.Basics → Blink** (the exact menu grouping may vary slightly by IDE/package version).
2. Confirm the board and port are still set to **Seeed XIAO nRF52840** and the connected XIAO port.
3. Click **Verify** (checkmark). The IDE should compile the example without errors.
4. Click **Upload** (right arrow). Wait for the upload-complete message.
5. Confirm the onboard LED changes state. If the example uses a different LED pattern or polarity, the important result is that upload succeeds and the sketch runs.

Arduino IDE's [upload guide](https://docs.arduino.cc/software/ide-v2/tutorials/getting-started/ide-v2-uploading-a-sketch/) explains the Verify and Upload controls.

## Serial Monitor for debugging

The GPIO test firmware will print input changes to Arduino IDE's **Serial Monitor**. Use **Tools → Serial Monitor** and select the baud rate specified by the sketch (the prototype will start at 115200 baud). The serial monitor is optional for BLE HID operation; it is only a development aid.

If a sketch using `Serial` fails to compile with the Seeed nRF52 package, Seeed documents a package-specific workaround: add `#include <Adafruit_TinyUSB.h>` to the sketch. Try this only when the compiler reports that issue; do not switch to the mbed-enabled board package as a first workaround, since the project needs the Seeed nRF52 Bluetooth stack.

## Open the project firmware when it is added

The initial sketch is [open-rally-remote.ino](../firmware/xiao-nrf52840/open-rally-remote.ino). Open it in Arduino IDE, verify that the Seeed board package and XIAO model are selected, then use **Verify** and **Upload** as above. The [firmware folder README](../firmware/xiao-nrf52840/README.md) gives the pin map and diagnostic test procedure. The sketch compiles with `arduino-cli` (see the firmware README for the toolchain used); it has not yet run on the purchased hardware.

The first project sketch should be uploaded in this order:

1. GPIO input test with the switches wired as documented in the [breadboard assembly guide](breadboard-assembly.md).
2. BLE HID diagnostic profile that sends a simple, distinguishable key for each input.
3. Gesture handling and app-specific mappings after key press/release and reconnection behavior are confirmed.

## Troubleshooting

| Symptom | Check |
|---|---|
| The board does not appear under Ports | Try a known USB-C data cable, connect directly to another USB port, and reopen the Port menu. Charge-only cables are a common cause. |
| The board is missing from the board list | Confirm **Seeed nRF52 Boards** installed successfully in Boards Manager, then restart Arduino IDE. |
| Upload fails or the port disappears during upload | Double-press the XIAO's reset button to enter its USB bootloader, then reselect the port and retry. The board may appear as a USB drive while in bootloader mode. |
| Compilation cannot find a BLE HID header | Confirm the selected board is **Seeed XIAO nRF52840** and the Seeed nRF52 package is installed; then open the Bluefruit `blehid_keyboard` example to check the available library/API. |
| `Serial` does not compile | Follow the Serial note above and the current Seeed documentation for the installed package version. |

## References

- [Arduino IDE downloads](https://www.arduino.cc/en/software/)
- [Arduino IDE 2: board manager](https://docs.arduino.cc/software/ide-v2/tutorials/ide-v2-board-manager/)
- [Arduino IDE 2: upload a sketch](https://docs.arduino.cc/software/ide-v2/tutorials/getting-started/ide-v2-uploading-a-sketch/)
- [Seeed Studio: XIAO nRF52840 setup](https://wiki.seeedstudio.com/XIAO_BLE/)
- [Seeed Studio: Bluetooth HID keyboard example](https://wiki.seeedstudio.com/XIAO-BLE-Sense-Bluetooth_Usage/)
- [Firmware behavior and OTA requirement](firmware-spec.md)
- [Breadboard assembly](breadboard-assembly.md)

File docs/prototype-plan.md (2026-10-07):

# Prototype Plan — BLE Input Proof of Concept

**Status:** recommendation; no board or component has been purchased or selected for the final design.

## Why prototype before the custom PCB

The main unknown is whether the selected BLE HID reports and press gestures reach the intended actions in TerraPirata, OsmAnd, and DMD² on the target operating systems. A temporary wired-on-bench input fixture lets us answer that without committing to a small enclosure or production PCB.

## Controller candidates

| Candidate | Current reference | Strengths | Trade-offs / checks |
|---|---|---|---|
| Seeed XIAO nRF52840 development board | Listed at $9.99 by Seeed; 21 × 17.8 mm board | Small complete board with integrated antenna, 5 V input, GPIO for the controls, low-power BLE, and published board files. Good candidate for the first HID compatibility prototype. | Costs more than a bare module; verify BLE HID pairing and app behavior on an iPhone and Android device before choosing it for the final unit. |
| ESP32-C3-WROOM-02 module on a custom breakout | Espressif lists a sample reference price around $1.90; module body is 18 × 20 mm | Potentially lower final electronics cost; Espressif's ESP-IDF includes a BLE HID device example that supports ESP32-C3. | The $1.90 figure is a sample reference, not a landed or single-unit total. Requires a carrier PCB and more firmware integration. Verify iOS BLE HID behavior and reconnection before selecting it. |

**Recommended first bench prototype:** use a complete nRF52840 board to reduce bring-up work. Keep ESP32-C3 as the cost-down candidate for the custom PCB, subject to the same app compatibility checks. This is a prototype convenience choice, not a final MCU decision.

Prices above were checked on 2026-10-07 and can change. They exclude shipping, taxes, headers, wiring, and any additional components.

## Purchase options for the nRF52840 prototype board (Spain)

The exact board to search for is Seeed part **102010448**, the standard XIAO nRF52840 without the Sense microphone/IMU. Prices and stock below were checked on 2026-10-07:

| Store | Listing | Price / stock shown | Notes |
|---|---|---|---|
| [Reichelt Spain](https://www.reichelt.com/es/es/shop/producto/xiao_nrf52840_bt5_0_sin_cabezal-358357) | XIAO nRF52840, no headers | €9.56 including VAT, plus shipping; available, estimated 4–5 business days | Lowest verified price found for the standard board. |
| [RS Spain](https://es.rs-online.com/web/p/placas-y-kits-compatibles-con-arduino/2500967) | Manufacturer part 102010448 | €14.59 including VAT; 1,046 units shown available | Higher price, with the exact manufacturer part number and stock clearly listed. |
| [Tiendatec](https://www.tiendatec.es/maker-zone/microcontroladores/xiao/2253-seeed-xiao-nrf52840-ble-8472496026444.html) | Standard XIAO nRF52840 BLE | €11.04; out of stock when checked | Tiendatec identifies itself as an official Seeed distributor in Spain. The Sense variant was listed separately at €18.95 and available, but its extra sensors are unnecessary for this project. |

Amazon.es search results did not provide a reliably verified listing for the exact standard part, so verify the seller, board variant, and manufacturer number **102010448** before ordering there. The links above are direct product pages; stock and prices may change.
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

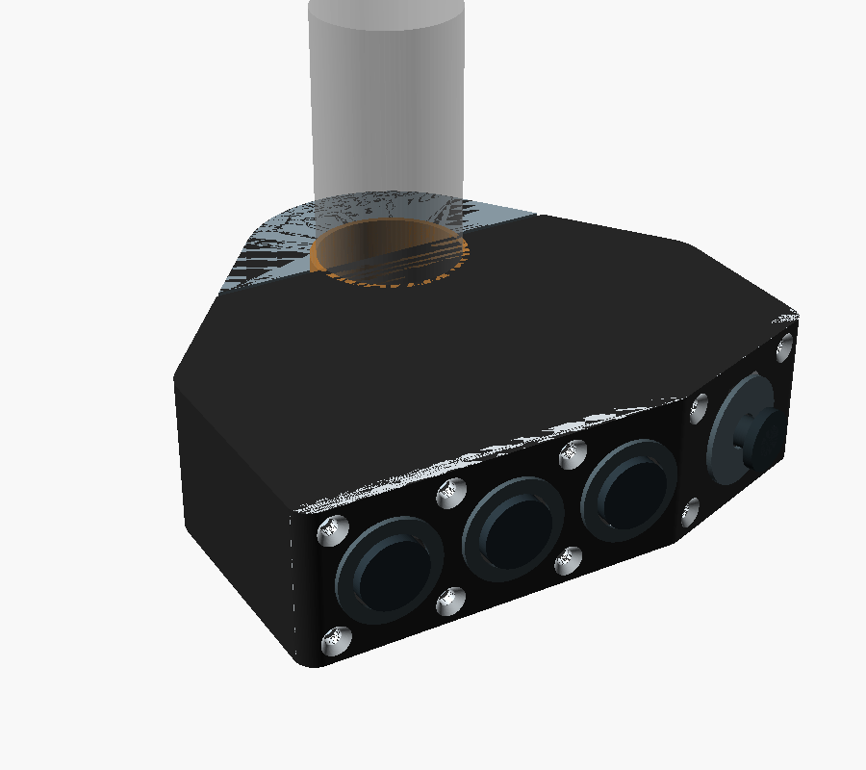
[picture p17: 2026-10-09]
docs/images/complete-remote-v0.20-iso.png

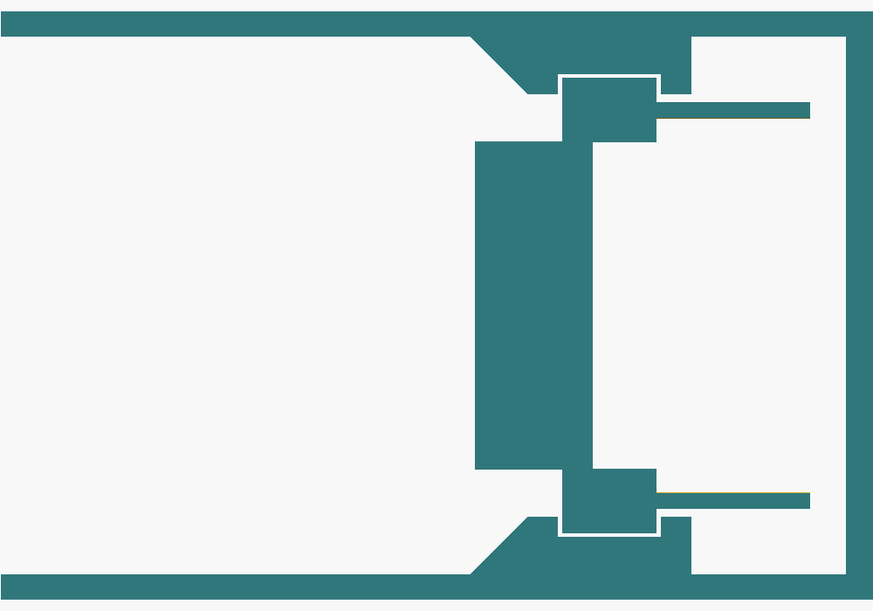
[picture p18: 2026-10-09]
docs/images/complete-remote-v0.19-xiao-section.png

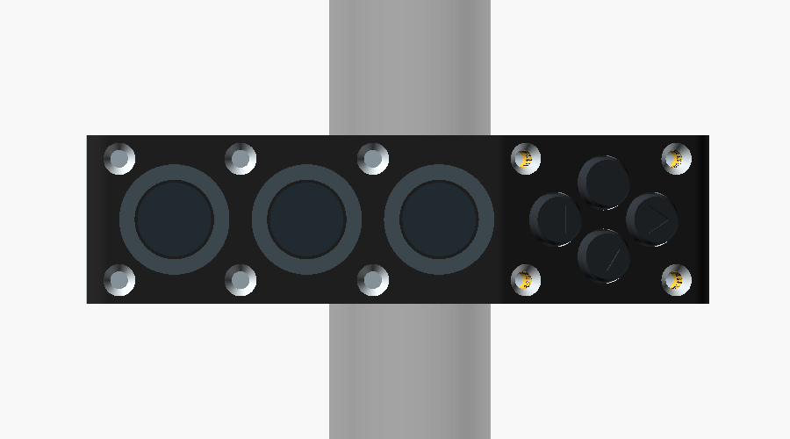
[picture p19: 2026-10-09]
docs/images/complete-remote-v0.21-front.png

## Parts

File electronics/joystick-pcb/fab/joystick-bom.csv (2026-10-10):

Reference | Value | Footprint | Manufacturer | MPN | LCSC | Qty
D1 | SMBJ5.0A | Diode_SMD:D_SMB | Littelfuse | SMBJ5.0A | C83333 | 1
F1 | MF-MSMF050-2 | Fuse:Fuse_1812_4532Metric | Bourns | MF-MSMF050-2 | C17313 | 1
SW1-SW4 | KSC222JLFS | orr:KSC2_SMD_6.2x6.2mm | C&K | KSC222JLFS | C221728 | 4

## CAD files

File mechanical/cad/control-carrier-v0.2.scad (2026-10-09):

// Open Rally Remote — button + joystick carrier, V0.2
// Based on APEM IS reduced-bezel buttons and Ruffy MHS joystick dimensions.
// The joystick's full profiled panel opening needs drawing/sample verification;
// this model shows the published Ø0.622 in (15.80 mm) nominal opening only.

$fn = 96;

button_cutout_diameter = 13.6;
button_bezel_diameter = 15.0; // APEM IS reduced-bezel option
button_pitch = 20.0;
panel_thickness = 2.5;        // APEM 1.5–4 mm; Ruffy MHS 2–3 mm
button_edge_margin = 2.75;    // derived from 20.5 mm width and 15 mm bezel
joystick_opening_diameter = 15.80; // Ruffy drawing: Ø0.622 in
control_pitch = 20.0;

button_count = 3;
control_count = button_count + 1;
panel_width = 20.5;
panel_length = button_bezel_diameter + 2 * button_edge_margin
             + control_pitch * (control_count - 1);

difference() {
    // Outline: 20.5 × 80.5 × 2.5 mm.
    translate([0, 0, panel_thickness / 2])
        cube([panel_width, panel_length, panel_thickness], center=true);

    // Buttons A, B, C. The lower joystick occupies the fourth control position.
    for (i = [0 : button_count - 1]) {
        y = -panel_length / 2 + button_edge_margin + button_bezel_diameter / 2
          + i * control_pitch;
        translate([0, y, -0.1])
            cylinder(d=button_cutout_diameter, h=panel_thickness + 0.2);
    }

    // Joystick mounting opening, centered 20 mm below button C.
    // See file header and mechanical guide: the manufacturer's drawing also
    // shows a 0.291 in profile detail not represented by this round opening.
    joystick_y = -panel_length / 2 + button_edge_margin + button_bezel_diameter / 2
               + button_count * control_pitch;
    translate([0, joystick_y, -0.1])
        cylinder(d=joystick_opening_diameter, h=panel_thickness + 0.2);
}

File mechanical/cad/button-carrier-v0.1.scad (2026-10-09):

// Open Rally Remote — three-button carrier fit plate, V0.1
// Dimensions use the APEM IS series published panel cutout and spacing.
// This is a fit-check plate, not the complete enclosure or handlebar clamp.

$fn = 96;

switch_cutout_diameter = 13.6;
switch_bezel_diameter = 17.5;
switch_pitch = 20.0;
panel_thickness = 2.5; // APEM IS specified panel range: 1.5–4.0 mm
edge_margin = 3.0;     // Explicit design allowance beyond bezel edge
button_count = 3;

panel_width = switch_bezel_diameter + 2 * edge_margin;
panel_length = switch_bezel_diameter + 2 * edge_margin
             + switch_pitch * (button_count - 1);

difference() {
    // XY outline is 23.5 × 63.5 mm; bottom face is at Z=0.
    translate([0, 0, panel_thickness / 2])
        cube([panel_width, panel_length, panel_thickness], center=true);

    // One column of three Ø13.6 mm panel cutouts, on 20 mm centers.
    for (i = [0 : button_count - 1]) {
        y = -panel_length / 2 + edge_margin + switch_bezel_diameter / 2
          + i * switch_pitch;
        translate([0, y, -0.1])
            cylinder(d=switch_cutout_diameter, h=panel_thickness + 0.2);
    }
}

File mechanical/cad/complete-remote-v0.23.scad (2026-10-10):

// Open Rally Remote — concept, V0.23
// Units: mm. Ring lies in XY; handlebar axis is Z. Controls are on the side face (YZ).
//
// V0.20 folds the control face between button C and the lower control: the upper facet (A, B, C)
// stays normal to X, the lower facet turns fold_angle toward the bar so the lower end of the
// pod clears the thumb's path to the turn-signal switch.
//
// V0.22 puts a joystick back on the lower facet, built from low-cost parts: a printed stick
// with a ball that pivots in a seat in the joystick plate, and a cross-shaped disc under the
// ball resting on four C&K KSC2 sealed tact switches. The switches' own springs centre the
// stick. Pushing the stick straight in presses all four; the firmware reads that as the centre
// press. The gasket's lower-facet sheet (from V0.21) grips the stick and seals the opening.
//
// V0.23 fits the joystick to a real PCB: the KSC2 land pattern (LCSC C221728) puts its pads
// 0.95 mm outside the body, so all four switches turn 90 degrees (pad rows radial for up/down,
// tangential for the bar-axis pair), the standoffs move to clear the pads, the PCB becomes an
// octagon shared with the KiCad board (electronics/joystick-pcb), and the rear keeps
// joy_pcb_rear for the input protection parts (PTC fuse, SMB TVS) and the wire pads.
//
// V0.22 also widens the control end of the pod to pod_width with pod_wall walls, while the
// clamp ring and everything within pod_wide_x of the bar keep axial_width.
//
// One outer solid (convex hull of the pod outline and the Ø44 clamp circle, axial_width wide,
// plus the pod_width front part) is cut into printed parts by offsets of the folded front and
// by the diametral clamp split:
//   - face cover:  0 .. face_cover_thickness behind the folded front
//   - gasket:      the next gasket_gap (compressed thickness); wall land on the upper facet,
//                  a full sheet on the lower facet
//   - joystick plate: behind the lower-facet sheet, joy_plate_t thick
//   - housing:     behind that, up to the split plane X = body_face_x
//   - clamp cap:   X >= cap_face_x
//
// Values marked MEASURE are supplier or purchase unknowns; check them on the real parts.

$fn = 96;
part_to_render = "assembly"; // assembly, interior, section, housing, clamp_cap, cover, gasket, stick,
                             // ball_disc, knob, joy_plate, liner_main, liner_cap, print_housing,
                             // print_cap, print_cover, print_gasket, print_ball_disc, print_knob,
                             // print_joy_plate
show_internals = true;       // component envelopes in section

// --- Handlebar and clamp -------------------------------------------------------------
bar_diameter = 22.0;         // MEASURE the straight section of the bar
liner_radial = 1.0;          // TPU liner; tune to measured bar and print process
clamp_bore = bar_diameter + 2*liner_radial;
clamp_outer = 44.0;
axial_width = 23.0;          // clamp and rear pod; NAVCOMM manual: at least 23 mm free between grip and switchgear
pod_width = 26.0;            // control end of the pod, beyond pod_wide_x from the bar
pod_wall = 2.0;              // axial walls of the wide part
pod_wide_x = -38.0;          // the pod is pod_width wide for X below this
pod_step = 1.5;              // 45-degree chamfer from pod_width down to axial_width ending at pod_wide_x
pod_z0 = (axial_width-pod_width)/2;
pod_z1 = pod_z0+pod_width;
pod_in0 = pod_z0+pod_wall;   // inner faces of the wide part's axial walls
pod_in1 = pod_z1-pod_wall;

split_gap = 0.8;             // total gap between body and cap faces; closes as bolts clamp the liner
clamp_bolt_y = 17.0;
clamp_bolt_d = 4.3;          // M4 clearance
bolt_length = 16.0;          // ISO 4762 M4 x 16
bolt_head_d = 7.0;
bolt_head_h = 4.0;
bolt_head_clear_d = 7.6;
cap_seat_x = 8.0;
insert_hole_d = 5.6;         // M4 heat-set insert hole; MEASURE against insert datasheet
insert_depth = 8.1;
bolt_tip_clearance = 2.0;

// --- Pod and folded front --------------------------------------------------------------
case_wall = 1.0;             // end walls, and axial walls of the narrow part
face_cover_thickness = 2.5;  // panel range: APEM IS 1.5-4 mm
gasket_gap = 0.6;            // compressed gasket thickness between cover and housing
gasket_print_thickness = 0.8;// printed or cut thickness; 25 % compression
cover_front_x = -57.5;       // upper facet outer plane
fold_y = -12.5;              // fold line on the outer surface, between button C and the joystick
fold_angle = 20;             // lower facet turns this far toward the bar; 30 deg needs the gland at the top
                             // (V0.20 joystick values: centre 16.5, lower_facet_length 32, lower screws at 5 and 27.6)
lower_facet_length = 30.0;   // outer surface, fold to lower end; sized for the corner cover screws
pod_top_y = 44.0;
pod_max_x = -15.0;
pod_rear_corner = 7.0;       // sets the tangent diagonals to the clamp ring
pod_front_corner = 3.0;
pod_cavity_x1 = pod_max_x-case_wall-6.0;
pod_cavity_front_corner = 2.0;
pod_cavity_rear_corner = 6.0;
lip_width = 3.0;             // gasket land added inside the axial walls along the upper facet
lip_depth = 2.0;

fold_d = [sin(fold_angle), -cos(fold_angle)];   // down the lower facet
fold_n = [cos(fold_angle), sin(fold_angle)];    // inward normal of the lower facet
fold_p = [cover_front_x, fold_y];
pod_end = fold_p + lower_facet_length*fold_d;   // outer lower corner before rounding
pod_bottom_y = pod_end[1];

cover_back_off = face_cover_thickness;
housing_front_off = face_cover_thickness+gasket_gap;

// Point on the folded front: facet 0 = upper (u is Y), facet 1 = lower (u is distance from fold).
function front_point(facet,u) = facet==0 ? [cover_front_x,u] : fold_p+u*fold_d;
function front_normal(facet) = facet==0 ? [1,0] : fold_n;

// --- Controls (envelopes from supplier drawings; MEASURE exact order codes) ------------
button_cutout = 13.6;        // APEM IS
button_y = [32.0, 14.0, -4.0];  // A, B, C on the upper facet, 18 mm pitch
button_body_d = 12.0;
switch_depth = 13.0;
button_head_projection = 1.8;
button_head_diameter = 10.0;
teardrop_cap = 0.0;          // flat cutout top this far above the circle (cover prints on its side)
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

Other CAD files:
mechanical/cad/complete-remote-v0.1.scad
mechanical/cad/complete-remote-v0.10.scad
mechanical/cad/complete-remote-v0.11.scad
mechanical/cad/complete-remote-v0.12.scad
mechanical/cad/complete-remote-v0.13.scad
mechanical/cad/complete-remote-v0.14.scad
mechanical/cad/complete-remote-v0.15.scad
mechanical/cad/complete-remote-v0.16.scad
mechanical/cad/complete-remote-v0.17.scad
mechanical/cad/complete-remote-v0.18.scad
mechanical/cad/complete-remote-v0.19.scad
mechanical/cad/complete-remote-v0.2.scad
mechanical/cad/complete-remote-v0.20.scad
mechanical/cad/complete-remote-v0.21.scad
mechanical/cad/complete-remote-v0.22.scad
mechanical/cad/complete-remote-v0.3.scad
mechanical/cad/complete-remote-v0.4.scad
mechanical/cad/complete-remote-v0.5.scad
mechanical/cad/complete-remote-v0.6.scad
mechanical/cad/complete-remote-v0.7.scad
mechanical/cad/complete-remote-v0.8.scad
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

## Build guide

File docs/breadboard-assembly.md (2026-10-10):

# XIAO nRF52840 Breadboard Assembly

**Status:** bench prototype instructions. This temporary switch fixture is for firmware and BLE experiments; it is not a riding-ready remote.

This guide uses a Seeed XIAO nRF52840 and eight momentary switches to represent the three buttons and a joystick with four directions and an optional center press. It keeps the XIAO off the breadboard and connects it with Dupont leads. Power and programming come from the XIAO's USB-C connector.

## Parts and Spain purchase options

Prices and stock were checked on 2026-10-07. The list is consolidated into two shops: Kiwi Electronics for the XIAO and Conectrol for the remaining parts. Prices include VAT where the shop displays it, but exclude shipping. Stock and delivery charges can change.

| Qty | Part | Example purchase | Price checked | Notes |
|---:|---|---|---:|---|
| 1 | Seeed XIAO nRF52840, standard pre-soldered model (MPN `102010631`) | [Kiwi Electronics](https://www.kiwi-electronics.com/en/seeed-studio-xiao-nrf52840-pre-soldered-20402) | €9.99 before VAT; approx. €12.09 with Spain's 21% VAT | This is the board purchased for this prototype. It has headers already soldered and is the non-Sense model. The product page showed stock when checked. |
| 1 | 400-point solderless breadboard | [Conectrol](https://conectrol.com/producto/placa-protoboard-400-puntos-84x55x85mm/) | €2.00 | Includes side power rails. |
| 1 set | 40 Dupont jumper wires, male-to-female, 20 cm | [Conectrol](https://conectrol.com/producto/kit-cables-dupont-1p-para-protoboard-m-h-40-unds/) | €3.00 | Use at least nine: eight GPIO signals and one XIAO GND lead. Female ends fit the XIAO headers; male ends fit the breadboard. |
| 1 set | 65 Dupont jumper wires, male-to-male | [Conectrol](https://conectrol.com/producto/kit-cables-dupont-1p-para-protoboard-m-m-65-unds/) | €3.00 | Use eight to connect the switches' ground-side rows to the blue rail. |
| 8 | 6×6×5 mm normally-open tactile switch | [Conectrol](https://conectrol.com/producto/pulsador-tactil-off-on-no-6x6x5mm-pcb-rojo/) | €0.20 each; €1.60 total | Three buttons, four joystick directions, and one center press. These tiny switches are only bench stand-ins. |
| 1 | USB-A to USB-C data cable, 1 m | [Conectrol](https://conectrol.com/producto/cable-usb-3-0-tipo-a-usb-tipo-c-3-1-m-m-1mt/) | €6.90 | Optional if you already have a data-capable cable. A charge-only cable will not allow programming. |

**Estimated parts total:** approx. €21.69 without a USB cable, or €28.59 with the listed cable, before shipping. The XIAO total uses the seller's €9.99 pre-tax listing plus an estimated 21% Spanish VAT; confirm the final tax and shipping at checkout. The parts are available from two shops. For a lower-cost alternative, the unheadered standard XIAO (MPN `102010448`) was listed at €9.56 including VAT by [Reichelt Spain](https://www.reichelt.com/es/es/shop/producto/xiao_nrf52840_bt5_0_sin_cabezal-358357); it would need 2×7 2.54 mm headers soldered on, available from Conectrol.

## Tools

- Soldering iron and solder, only if using the unheadered board alternative.
- Small side cutters to cut pin strips, only if using that alternative.
- A USB data cable and a computer for programming.
- Optional multimeter to identify which two switch legs form each electrical side.

## Pin assignment

The firmware should configure these GPIOs as inputs with internal pull-ups. Each switch closes its GPIO to ground when pressed, so the released state reads HIGH and the pressed state reads LOW.

| XIAO pin | Breadboard switch | Function |
|---|---|---|
| D0 | SW1 | Button A |
| D1 | SW2 | Button B |
| D2 | SW3 | Button C |
| D3 | SW4 | Joystick up |
| D4 | SW5 | Joystick down |
| D5 | SW6 | Joystick left |
| D6 | SW7 | Joystick right |
| D7 | SW8 | Joystick center press (breadboard only) |
| GND | Blue/negative rail | Shared switch ground |

The enclosure joystick has no center switch; the firmware reads a straight push as the center. On the breadboard that push cannot be made, so SW8 on D7 stands in for it: set `CENTER_FROM_CHORD` to `false` in the sketch. With the default `true`, D7 is not read. No 3.3 V or 5 V rail connection is needed for this switch circuit.

## Breadboard wiring diagram

Keep the XIAO beside the breadboard rather than forcing the small board into it. Each switch straddles the breadboard's center trench. One electrical side goes to its GPIO row; the other side goes to the blue ground rail. On a standard breadboard, the five holes on each side of a numbered row are connected together, but the two groups across the center trench are separate.

Non-crossing XIAO nRF52840 wiring diagram for eight temporary switches

```text
XIAO nRF52840 (kept beside the breadboard)
  D0 ───────────────────────────────────────────────────────┐
  D1 ────────────────────────────────────────────────────┐  │
  D2 ─────────────────────────────────────────────────┐  │  │
  D3 ──────────────────────────────────────────────┐  │  │  │
  D4 ───────────────────────────────────────────┐  │  │  │  │
  D5 ────────────────────────────────────────┐  │  │  │  │  │
  D6 ─────────────────────────────────────┐  │  │  │  │  │  │
  D7 ──────────────────────────────────┐  │  │  │  │  │  │  │
 GND ──────────────────────────────────┼──┼──┼──┼──┼──┼──┼──┼──── blue (−) rail

Breadboard rows (switches straddle the center trench):
                       a b c d e  ║  f g h i j
 Button A / D0 row:    GPIO ──────║───o/ o─────── GND ─── blue (−)
 Button B / D1 row:    GPIO ──────║───o/ o─────── GND ─── blue (−)
 Button C / D2 row:    GPIO ──────║───o/ o─────── GND ─── blue (−)
 Joystick UP / D3:     GPIO ──────║───o/ o─────── GND ─── blue (−)
 Joystick DOWN / D4:   GPIO ──────║───o/ o─────── GND ─── blue (−)
 Joystick LEFT / D5:   GPIO ──────║───o/ o─────── GND ─── blue (−)
 Joystick RIGHT / D6:  GPIO ──────║───o/ o─────── GND ─── blue (−)
 Center press / D7:    GPIO ──────║───o/ o─────── GND ─── blue (−)
                                     switch

USB-C on XIAO ── data cable ── computer / USB supply
```

The SVG is a wiring view, not a scale drawing of the physical jumper routes. Place the eight switches in separate numbered rows and connect each switch's opposite side to the ground rail. The two five-hole groups in each row (a–e and f–j) are not connected across the center trench. Switch leg layout can vary, so check the switch drawing or use continuity mode to identify the internally joined pairs before wiring.

### Wiring steps

1. **Fit the headers.** Solder one 1×7 male header to each long edge of the XIAO, with the pins projecting downward. Avoid solder bridges between adjacent pads. If using a pre-soldered board, skip this step.
2. **Place the switches.** Insert all eight tactile switches across the breadboard's center trench, each on its own row. Keep them spaced and label the rows A, B, C, UP, DOWN, LEFT, RIGHT, and CENTER.
3. **Connect ground.** Use one jumper from a XIAO GND pin to the breadboard's blue/negative rail. If the rail is split halfway along its length, bridge the two rail sections with another jumper.
4. **Connect the GPIO leads.** Use eight male-to-female leads to connect D0 through D7 to one electrical side of the corresponding switch. Use the pin map above. D7 is optional.
5. **Ground the other switch side.** Use eight male-to-male leads to connect the opposite electrical side of each switch to the blue ground rail. Connect the XIAO GND pin to that rail with a separate male-to-female lead.
6. **Inspect before power.** Check that no GPIO row is accidentally connected to the red rail. Check that the switch legs span the trench and that each GPIO and ground wire reaches opposite electrical sides of its switch.
7. **Power over USB.** Connect the XIAO's USB-C port to a computer or USB supply using a data-capable cable when programming. Do not feed 5 V into a GPIO, and do not connect a second supply to the breadboard while USB is connected.

## Scope and limitations

This assembly is intended for a desk or bench. Solderless breadboards, exposed Dupont leads, and small tactile switches are not vibration-proof, weatherproof, or glove-friendly. Do not mount or use this prototype on a moving motorcycle. The fixture tests button input and firmware behavior; it does not prove the final joystick mechanism, enclosure, USB power protection, or Android/iOS app compatibility.

## References

- [Seeed XIAO nRF52840 documentation: pinout, power, and board details](https://wiki.seeedstudio.com/XIAO_BLE/)
- [Seeed XIAO nRF52840 product page](https://www.seeedstudio.com/Seeed-XIAO-BLE-nRF52840-p-5201.html)
- [Kiwi Electronics: the pre-soldered XIAO nRF52840 purchased for this prototype](https://www.kiwi-electronics.com/en/seeed-studio-xiao-nrf52840-pre-soldered-20402)
- [Reichelt Spain: lower-cost XIAO nRF52840 without headers](https://www.reichelt.com/es/es/shop/producto/xiao_nrf52840_bt5_0_sin_cabezal-358357)
- [Conectrol: 40-pin male header strip for the unheadered-board alternative](https://conectrol.com/producto/tira-de-pines-macho-40p-2-54mm-1-fila-plano-recto-pcb-2/)
- [Conectrol: 400-point breadboard](https://conectrol.com/producto/placa-protoboard-400-puntos-84x55x85mm/)
- [Conectrol: male-to-female Dupont jumper set](https://conectrol.com/producto/kit-cables-dupont-1p-para-protoboard-m-h-40-unds/)
- [Conectrol: male-to-male Dupont jumper set](https://conectrol.com/producto/kit-cables-dupont-1p-para-protoboard-m-m-65-unds/)
- [Conectrol: 6×6×5 mm tactile switch](https://conectrol.com/producto/pulsador-tactil-off-on-no-6x6x5mm-pcb-rojo/)
- [Conectrol: USB-A to USB-C data cable](https://conectrol.com/producto/cable-usb-3-0-tipo-a-usb-tipo-c-3-1-m-m-1mt/)

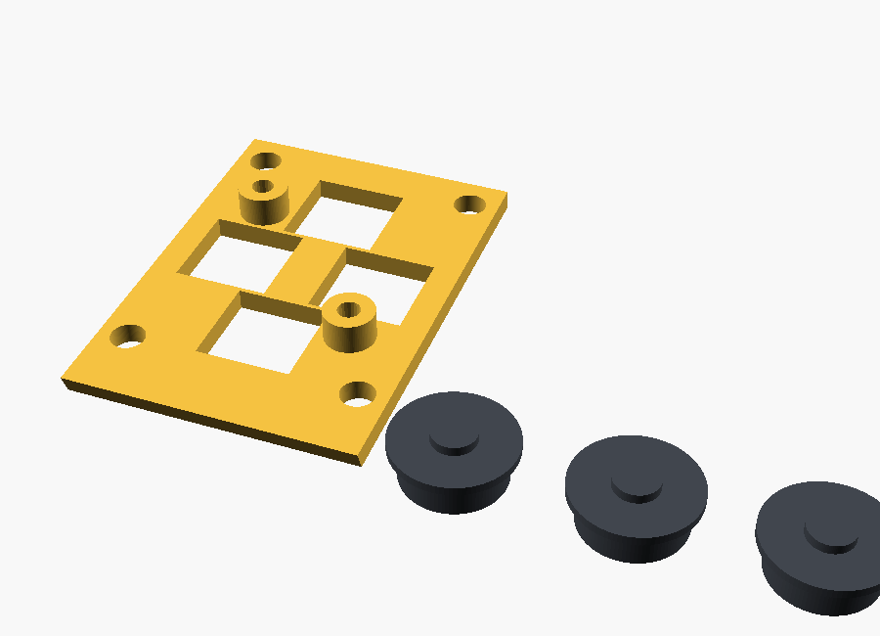
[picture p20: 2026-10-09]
docs/images/complete-remote-v0.21-print-pad.png

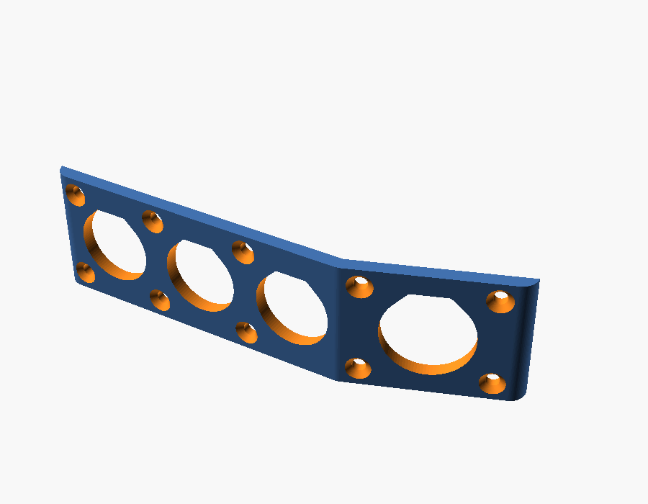
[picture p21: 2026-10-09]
docs/images/complete-remote-v0.20-print-cover.png

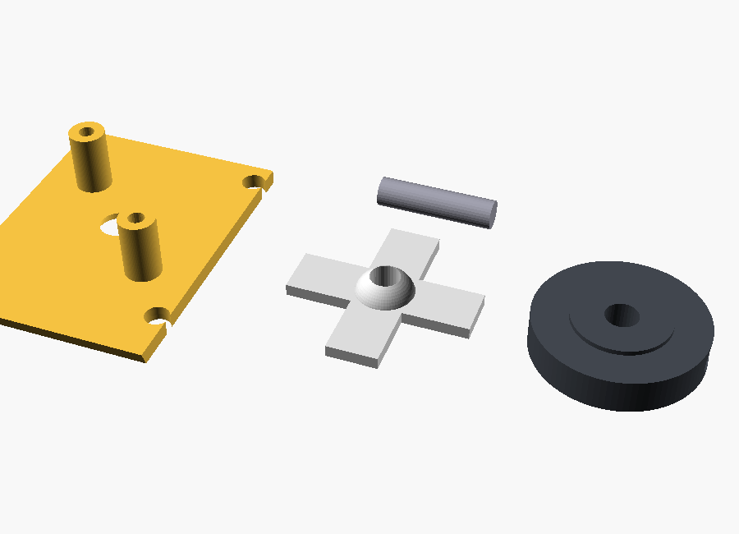
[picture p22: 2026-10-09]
docs/images/complete-remote-v0.22-print-joy.png

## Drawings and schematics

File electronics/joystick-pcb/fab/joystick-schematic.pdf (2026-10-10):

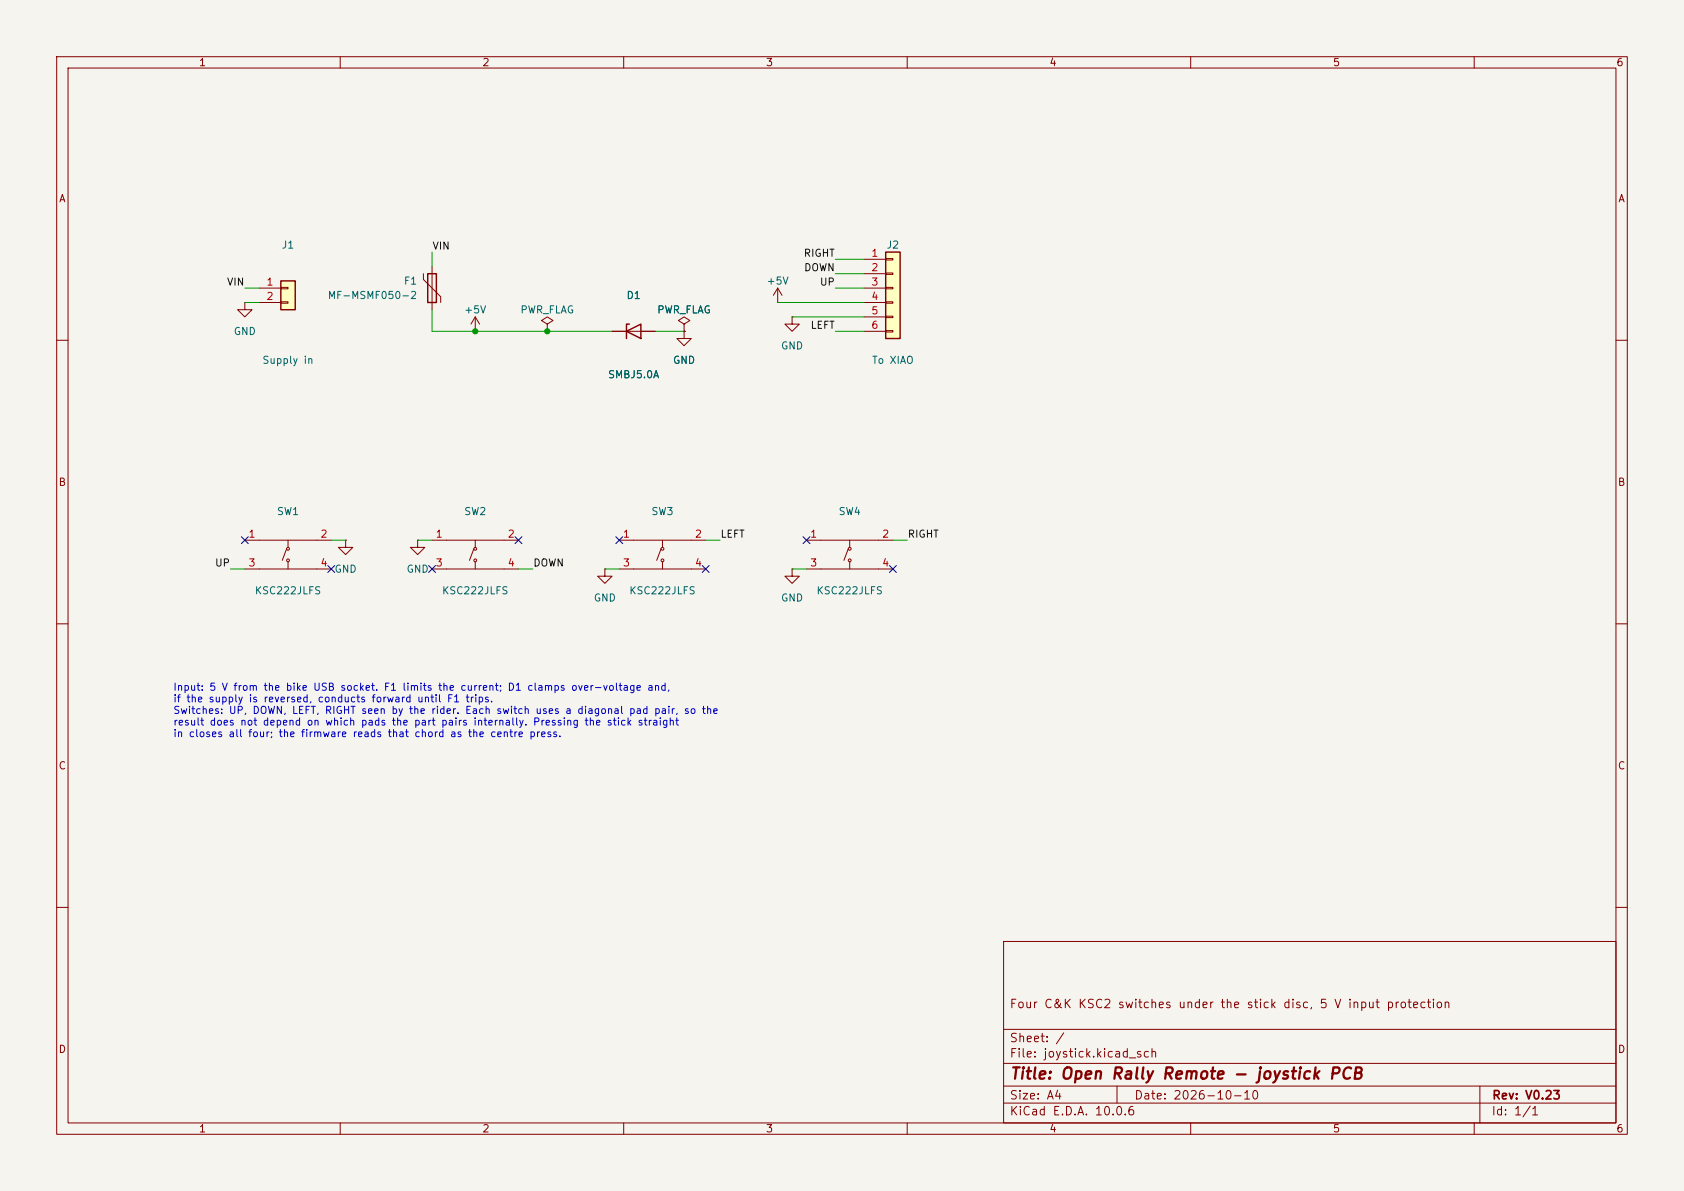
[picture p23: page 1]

Input: 5 V from the bike USB socket. F1 limits the current; D1 clamps over-voltage and,
if the supply is reversed, conducts forward until F1 trips. Switches: UP, DOWN, LEFT, RIGHT seen by the rider. Each switch uses a diagonal pad pair, so the

result does not depend on which pads the part pairs internally. Pressing the stick straight

Four C&K KSC2 switches under the stick disc, 5 V input protection

Sheet: /
File: joystick.kicad_sch
Title: Open Rally Remote - joystick PCB

Size: A4 | Rev: V0.23
KiCad E.D.A. 10.0.6 | Id: 1/1

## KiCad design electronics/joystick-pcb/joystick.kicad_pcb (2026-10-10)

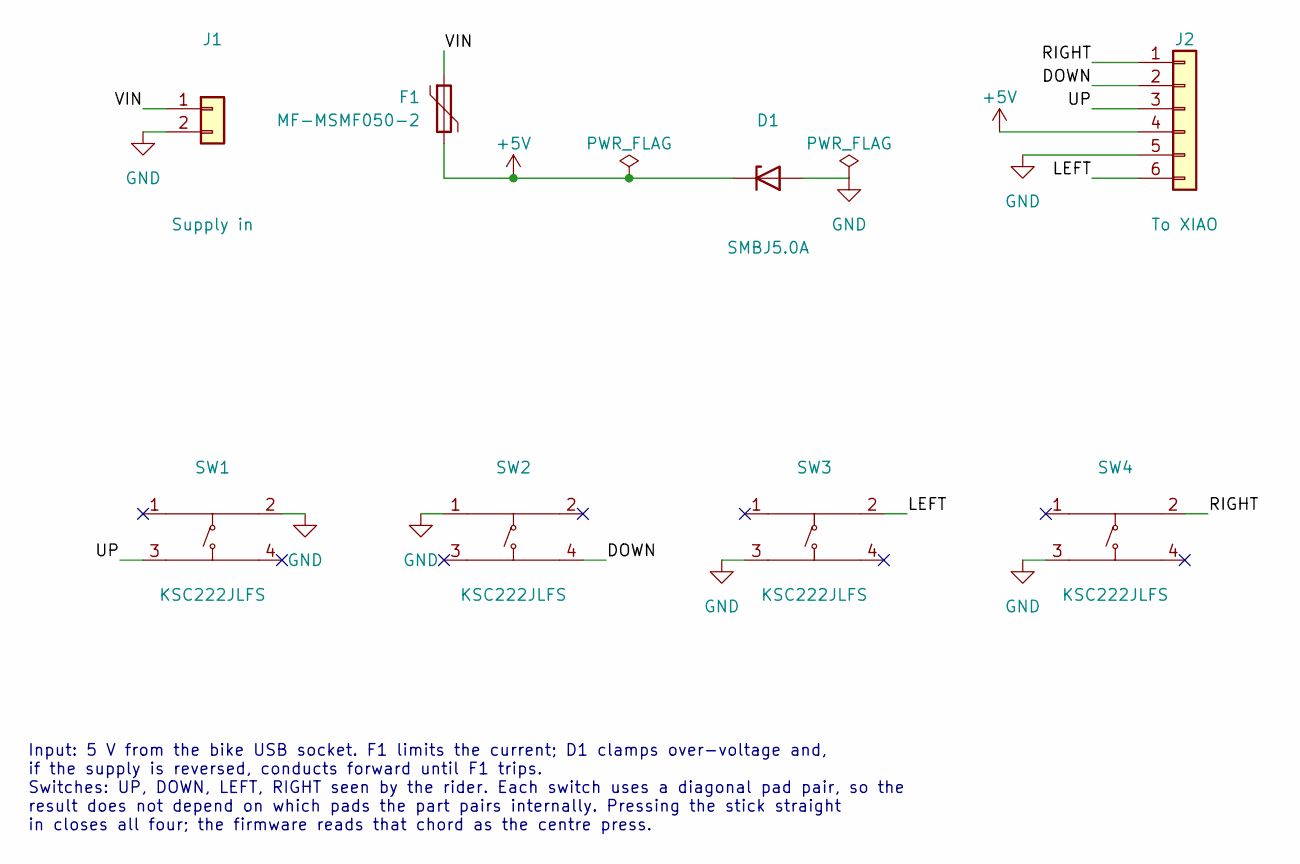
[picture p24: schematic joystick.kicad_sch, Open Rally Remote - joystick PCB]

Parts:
D1: SMBJ5.0A; D_SMB; MPN SMBJ5.0A; LCSC C83333
F1: MF-MSMF050-2; Fuse_1812_4532Metric; MPN MF-MSMF050-2; LCSC C17313
J1: Supply in; WirePads_1x02_P2.4mm
J2: To XIAO; WirePads_1x06_P2.1mm
SW1, SW2, SW3, SW4: KSC222JLFS; KSC2_SMD_6.2x6.2mm; MPN KSC222JLFS; LCSC C221728

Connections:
+5V: D1.1 (K), F1.2, J2.4
/DOWN: J2.2, SW2.4
/LEFT: J2.6, SW3.2
/RIGHT: J2.1, SW4.2
/UP: J2.3, SW1.3
/VIN: F1.1, J1.1
GND: D1.2 (A), J1.2, J2.5, SW1.2, SW2.1, SW3.3, SW4.3

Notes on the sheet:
Input: 5 V from the bike USB socket. F1 limits the current; D1 clamps over-voltage and, if the supply is reversed, conducts forward until F1 trips. Switches: UP, DOWN, LEFT, RIGHT seen by the rider. Each switch uses a diagonal pad pair, so the result does not depend on which pads the part pairs int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

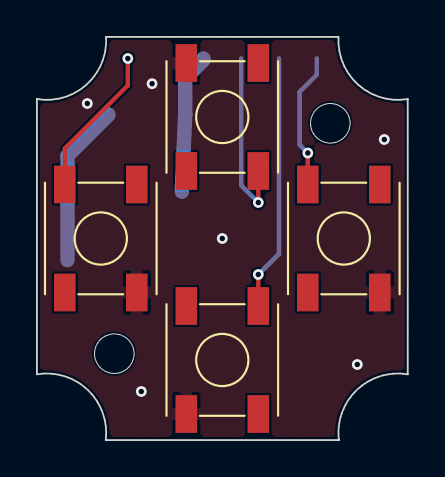
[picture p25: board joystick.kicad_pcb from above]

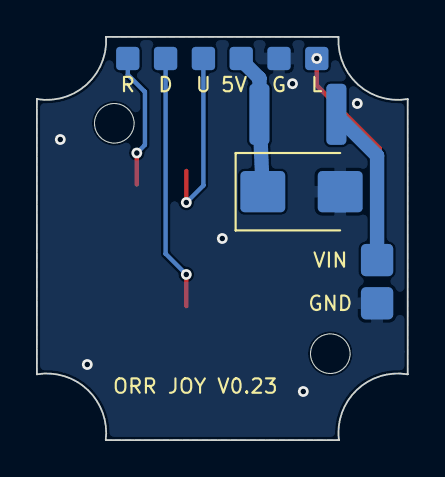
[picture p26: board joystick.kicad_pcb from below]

Board: 2 copper layers, 20.6 x 22.4 mm, 10 parts (4 on the bottom side), 7 nets.

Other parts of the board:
H1, H2: M2 standoff; Standoff_M2_PCB

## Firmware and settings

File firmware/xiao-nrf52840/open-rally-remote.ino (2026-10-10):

/*
 * Open Rally Remote - XIAO nRF52840 bench firmware
 *
 * Purpose: read the active-low switches (three buttons, four joystick
 * directions) and send diagnostic keyboard events over BLE HID. The joystick
 * center press is the chord of three or more directions, or optionally a
 * separate switch on D7. This is a desk prototype, not riding firmware.
 *
 * Board package: Seeed nRF52 Boards
 * Board: Seeed XIAO nRF52840
 * BLE HID API: Adafruit Bluefruit nRF52 library bundled with the Seeed package
 */

#include <Adafruit_TinyUSB.h>
#include <bluefruit.h>

// ---------- Build options ----------

// Center press source. true: three or more direction switches closed
// together, as on the V0.22+ joystick (D7 unused). false: a separate switch
// on D7, as on the breadboard prototype.
constexpr bool CENTER_FROM_CHORD = true;

// Enable Serial Monitor diagnostics while developing.
constexpr bool SERIAL_DEBUG = true;

// ---------- Timing (initial prototype values) ----------

constexpr uint32_t DEBOUNCE_MS = 30;
constexpr uint32_t LONG_PRESS_MS = 600;
constexpr uint32_t DOUBLE_PRESS_MS = 300;
constexpr uint32_t TAP_HOLD_MS = 50;
// Direction key-down is held back this long after the first direction closes,
// so a straight push is reported as the center and not as a direction.
constexpr uint32_t CHORD_WINDOW_MS = 40;

// ---------- Hardware mapping ----------

enum ControlIndex : uint8_t {
  BUTTON_A = 0,
  BUTTON_B,
  BUTTON_C,
  JOYSTICK_UP,
  JOYSTICK_DOWN,
  JOYSTICK_LEFT,
  JOYSTICK_RIGHT,
  JOYSTICK_CENTER,
  CONTROL_COUNT
};

const uint8_t CONTROL_PINS[CONTROL_COUNT] = {
  D0, D1, D2, D3, D4, D5, D6, D7
};

const char *const CONTROL_NAMES[CONTROL_COUNT] = {
  "Button A", "Button B", "Button C", "Joystick up", "Joystick down",
  "Joystick left", "Joystick right", "Joystick center"
};

// Diagnostic-only key assignments:
// A: short/long/double = A/B/C
// B: short/long/double = D/E/F
// C: short/long/double = G/H/I
// Center: short/long/double = J/K/L
const uint8_t GESTURE_KEYS[4][3] = {
  { HID_KEY_A, HID_KEY_B, HID_KEY_C },
  { HID_KEY_D, HID_KEY_E, HID_KEY_F },
  { HID_KEY_G, HID_KEY_H, HID_KEY_I },
  { HID_KEY_J, HID_KEY_K, HID_KEY_L }
};

enum GestureType : uint8_t {
  GESTURE_SHORT = 0,
  GESTURE_LONG = 1,
  GESTURE_DOUBLE = 2
};

BLEDis deviceInfo;
BLEHidAdafruit bleHid;

struct DebouncedInput {
  uint8_t pin;
  bool rawPressed;
  bool stablePressed;
  uint32_t rawChangedAt;
};

struct GestureState {
  bool isDown;
  bool longSent;
  bool hasPendingShort;
  bool secondPressCandidate;
  uint32_t pressedAt;
  uint32_t pendingShortAt;
};

DebouncedInput inputs[CONTROL_COUNT];
GestureState gestures[CONTROL_COUNT] = {};

constexpr uint8_t TAP_QUEUE_SIZE = 16;
uint8_t tapQueue[TAP_QUEUE_SIZE];
uint8_t tapQueueHead = 0;
uint8_t tapQueueTail = 0;
uint8_t droppedTapCount = 0;

bool tapIsActive = false;
uint8_t activeTapKey = HID_KEY_NONE;
uint32_t activeTapStartedAt = 0;

bool previousBleConnected = false;
bool lastReportValid = false;
uint8_t lastReportKeys[6] = {};
bool ignoreUntilRelease[CONTROL_COUNT] = {};

// Joystick direction handling (see docs/firmware-spec.md, section 5).
enum JoystickMode : uint8_t {
  JOY_IDLE,        // no direction closed
  JOY_PENDING,     // a direction closed; waiting out the chord window
  JOY_DIRECTIONS,  // reporting the held directions
  JOY_SUPPRESSED,  // opposite directions closed: no keys until a chord or release
  JOY_CENTER,      // chord: center held, no direction keys until all released
  JOY_BLOCKED      // held at (re)connect: ignored until all released
};

JoystickMode joyMode = JOY_IDLE;
uint32_t joyPendingSince = 0;
uint8_t joySeenMask = 0;

// Bits: up = 1, down = 2, left = 4, right = 8.
constexpr uint8_t DIR_VERTICAL = 0x3;
constexpr uint8_t DIR_HORIZONTAL = 0xC;
const uint8_t DIRECTION_KEYS[4] = {
  HID_KEY_ARROW_UP, HID_KEY_ARROW_DOWN, HID_KEY_ARROW_LEFT, HID_KEY_ARROW_RIGHT
};

// A physical input on its pin; in chord mode the center has no pin.
bool controlIsInstalled(uint8_t control) {
  return control != JOYSTICK_CENTER || !CENTER_FROM_CHORD;
}

void printControlEvent(uint8_t control, const char *eventName) {
  if (!SERIAL_DEBUG) return;
  Serial.print(CONTROL_NAMES[control]);
  Serial.print(": ");
  Serial.println(eventName);
}

void resetGestureState() {
  for (uint8_t i = 0; i < CONTROL_COUNT; ++i) {
    gestures[i] = {};
  }
}

void clearTapQueue() {
  tapQueueHead = 0;
  tapQueueTail = 0;
  tapIsActive = false;
  activeTapKey = HID_KEY_NONE;
}

bool enqueueTap(uint8_t keyCode) {
  if (!Bluefruit.connected()) return false;

  const uint8_t nextTail = (tapQueueTail + 1) % TAP_QUEUE_SIZE;
  if (nextTail == tapQueueHead) {
    if (droppedTapCount < 255) ++droppedTapCount;
    return false;
  }

  tapQueue[tapQueueTail] = keyCode;
  tapQueueTail = nextTail;
  return true;
}

void addKey(uint8_t keys[6], uint8_t keyCode) {
  if (keyCode == HID_KEY_NONE) return;

  for (uint8_t i = 0; i < 6; ++i) {
    if (keys[i] == keyCode) return;
  }
  for (uint8_t i = 0; i < 6; ++i) {
    if (keys[i] == HID_KEY_NONE) {
      keys[i] = keyCode;
      return;
    }
  }
}

uint8_t directionMask() {
  uint8_t mask = 0;
  for (uint8_t i = 0; i < 4; ++i) {
    if (inputs[JOYSTICK_UP + i].stablePressed) mask |= 1 << i;
  }
  return mask;
}

// Opposing directions cancel; perpendicular directions may be held together.
uint8_t cancelOpposites(uint8_t mask) {
  if ((mask & DIR_VERTICAL) == DIR_VERTICAL) mask &= ~DIR_VERTICAL;
  if ((mask & DIR_HORIZONTAL) == DIR_HORIZONTAL) mask &= ~DIR_HORIZONTAL;
  return mask;
}

void buildCurrentReport(uint8_t keys[6]) {
  memset(keys, HID_KEY_NONE, 6);

  if (joyMode == JOY_DIRECTIONS) {
    const uint8_t mask = cancelOpposites(directionMask());
    for (uint8_t i = 0; i < 4; ++i) {
      if (mask & (1 << i)) addKey(keys, DIRECTION_KEYS[i]);
    }
  }

  if (tapIsActive) addKey(keys, activeTapKey);
}

void publishReport() {
  if (!Bluefruit.connected()) return;

  uint8_t keys[6];
  buildCurrentReport(keys);

  if (lastReportValid && memcmp(keys, lastReportKeys, sizeof(keys)) == 0) {
    return;
  }

  if (bleHid.keyboardReport(0, keys)) {
    memcpy(lastReportKeys, keys, sizeof(keys));
    lastReportValid = true;
  }
}

void publishAllKeysReleased() {
  if (!Bluefruit.connected()) return;
  uint8_t releasedKeys[6] = {};
  if (bleHid.keyboardReport(0, releasedKeys)) {
    memset(lastReportKeys, HID_KEY_NONE, sizeof(lastReportKeys));
    lastReportValid = true;
  } else {
    lastReportValid = false;
  }
}

void emitGesture(uint8_t control, GestureType gesture) {
  uint8_t tableRow;
  if (control <= BUTTON_C) {
    tableRow = control;
  } else if (control == JOYSTICK_CENTER) {
    tableRow = 3;
  } else {
    return;
  }

  const uint8_t keyCode = GESTURE_KEYS[tableRow][gesture];
  if (enqueueTap(keyCode)) {
    if (SERIAL_DEBUG) {
      Serial.print(CONTROL_NAMES[control]);
      Serial.print(" gesture: ");
      Serial.print(gesture == GESTURE_SHORT ? "short" :
                   gesture == GESTURE_LONG ? "long" : "double");
      Serial.print(" -> HID key ");
      Serial.println((char)('A' + keyCode - HID_KEY_A));
    }
  }
}

void startGesture(uint8_t control, uint32_t now) {
  GestureState &state = gestures[control];
  if (state.hasPendingShort &&
      (uint32_t)(now - state.pendingShortAt) >= DOUBLE_PRESS_MS) {
    state.hasPendingShort = false;
    emitGesture(control, GESTURE_SHORT);
  }
  state.isDown = true;
  state.longSent = false;
  state.pressedAt = now;
  state.secondPressCandidate = state.hasPendingShort &&
      (uint32_t)(now - state.pendingShortAt) < DOUBLE_PRESS_MS;
  printControlEvent(control, "pressed");
}

void finishGesture(uint8_t control, uint32_t now) {
  GestureState &state = gestures[control];
  state.isDown = false;
  printControlEvent(control, "released");

  if (state.longSent) {
    state.secondPressCandidate = false;
    return;
  }

  if (state.secondPressCandidate) {
    state.hasPendingShort = false;
    state.secondPressCandidate = false;
    emitGesture(control, GESTURE_DOUBLE);
    return;
  }

  state.hasPendingShort = true;
  state.pendingShortAt = now;
}

void handleStableTransition(uint8_t control, bool pressed, uint32_t now) {
  if (!controlIsInstalled(control)) return;

  if (ignoreUntilRelease[control]) {
    if (!pressed) ignoreUntilRelease[control] = false;
    printControlEvent(control, "input synchronized; event ignored until released");
    return;
  }

  if (control <= BUTTON_C || control == JOYSTICK_CENTER) {
    if (pressed) startGesture(control, now);
    else finishGesture(control, now);
    return;
  }

  // Directions are reported by updateJoystick().
  printControlEvent(control, pressed ? "direction closed" : "direction opened");
}

void pressChordCenter(uint32_t now) {
  joyMode = JOY_CENTER;
  startGesture(JOYSTICK_CENTER, now);
}

// Turns the debounced direction switches into held arrow keys or, in chord
// mode, the center press. Runs every loop so the chord window can expire.
void updateJoystick(uint32_t now) {
  const uint8_t mask = directionMask();
  const uint8_t count = __builtin_popcount(mask);
  const bool opposite = mask != cancelOpposites(mask);

  switch (joyMode) {
    case JOY_IDLE:
      if (!mask) break;
      if (!CENTER_FROM_CHORD) {
        joyMode = JOY_DIRECTIONS;
        break;
      }
      joyMode = JOY_PENDING;
      joyPendingSince = now;
      joySeenMask = 0;
      [[fallthrough]];

    case JOY_PENDING:
      joySeenMask |= mask;
      if (count >= 3) {
        pressChordCenter(now);
      } else if (!mask) {
        // Released inside the window: send the tilt as a tap so it is not lost.
        const uint8_t tapped = cancelOpposites(joySeenMask);
        for (uint8_t i = 0; i < 4; ++i) {
          if (tapped & (1 << i)) enqueueTap(DIRECTION_KEYS[i]);
        }
        joyMode = JOY_IDLE;
      } else if ((uint32_t)(now - joyPendingSince) >= CHORD_WINDOW_MS) {
        joyMode = opposite ? JOY_SUPPRESSED : JOY_DIRECTIONS;
      }
      break;

    case JOY_DIRECTIONS:
      if (!mask) {
        joyMode = JOY_IDLE;
      } else if (CENTER_FROM_CHORD && count >= 3) {
        // A slow push: direction keys already sent are released here.
        pressChordCenter(now);
      } else if (CENTER_FROM_CHORD && opposite) {
        joyMode = JOY_SUPPRESSED;
      }
      break;

    case JOY_SUPPRESSED:
      if (count >= 3) pressChordCenter(now);
      else if (!mask) joyMode = JOY_IDLE;
      break;

    case JOY_CENTER:
      if (!mask) {
        finishGesture(JOYSTICK_CENTER, now);
        joyMode = JOY_IDLE;
      }
      break;

    case JOY_BLOCKED:
      if (!mask) joyMode = JOY_IDLE;
      break;
  }

  publishReport();
}

void synchronizeInputs(uint32_t now) {
  for (uint8_t i = 0; i < CONTROL_COUNT; ++i) {
    if (!controlIsInstalled(i)) continue;
    const bool pressed = digitalRead(inputs[i].pin) == LOW;
    inputs[i].rawPressed = pressed;
    inputs[i].stablePressed = pressed;
    inputs[i].rawChangedAt = now;
    ignoreUntilRelease[i] = pressed;
  }
  resetGestureState();
  joyMode = directionMask() ? JOY_BLOCKED : JOY_IDLE;
}

void scanInputs(uint32_t now) {
  for (uint8_t i = 0; i < CONTROL_COUNT; ++i) {
    if (!controlIsInstalled(i)) continue;

    const bool rawPressed = digitalRead(inputs[i].pin) == LOW;
    if (rawPressed != inputs[i].rawPressed) {
      inputs[i].rawPressed = rawPressed;
      inputs[i].rawChangedAt = now;
    }

    if (inputs[i].stablePressed != inputs[i].rawPressed &&
        (uint32_t)(now - inputs[i].rawChangedAt) >= DEBOUNCE_MS) {
      inputs[i].stablePressed = inputs[i].rawPressed;
      handleStableTransition(i, inputs[i].stablePressed, now);
    }
  }
}

void processGestureTimers(uint32_t now) {
  if (!Bluefruit.connected()) return;

  // Directions never start a gesture; the chord center has no pin but does.
  for (uint8_t i = 0; i < CONTROL_COUNT; ++i) {
    GestureState &state = gestures[i];

    if (state.isDown && !state.longSent &&
        (uint32_t)(now - state.pressedAt) >= LONG_PRESS_MS) {
      state.longSent = true;
      state.secondPressCandidate = false;
      state.hasPendingShort = false;
      emitGesture(i, GESTURE_LONG);
    }

    if (!state.isDown && state.hasPendingShort &&
        (uint32_t)(now - state.pendingShortAt) >= DOUBLE_PRESS_MS) {
      state.hasPendingShort = false;
      emitGesture(i, GESTURE_SHORT);
    }
  }
}

void processTapQueue(uint32_t now) {
  if (!Bluefruit.connected()) {
    clearTapQueue();
    return;
  }

  if (tapIsActive && (uint32_t)(now - activeTapStartedAt) >= TAP_HOLD_MS) {
    tapIsActive = false;
    activeTapKey = HID_KEY_NONE;
    publishReport(); // send the key-up report
    return;           // leave a report interval before starting the next tap
  }

  if (!tapIsActive && tapQueueHead != tapQueueTail) {
    activeTapKey = tapQueue[tapQueueHead];
    tapQueueHead = (tapQueueHead + 1) % TAP_QUEUE_SIZE;
    tapIsActive = true;
    activeTapStartedAt = now;
    publishReport(); // send the key-down report
  }
}

void beginBleKeyboard() {
  Bluefruit.begin();
  Bluefruit.setTxPower(4);
  Bluefruit.setName("Open Rally Remote");

  deviceInfo.setManufacturer("Open Rally Remote Project");
  deviceInfo.setModel("XIAO nRF52840 Bench Prototype");
  deviceInfo.setSoftwareRev("0.2.0-diagnostic");
  deviceInfo.begin();

  bleHid.begin();

  Bluefruit.Advertising.addFlags(BLE_GAP_ADV_FLAGS_LE_ONLY_GENERAL_DISC_MODE);
  Bluefruit.Advertising.addTxPower();
  Bluefruit.Advertising.addAppearance(BLE_APPEARANCE_HID_KEYBOARD);
  Bluefruit.Advertising.addService(bleHid);
  Bluefruit.Advertising.addName();
  Bluefruit.Advertising.restartOnDisconnect(true);
  Bluefruit.Advertising.setInterval(32, 244);
  Bluefruit.Advertising.setFastTimeout(30);
  Bluefruit.Advertising.start(0);
}

void setup() {
  if (SERIAL_DEBUG) {
    Serial.begin(115200);
    const uint32_t serialWaitStarted = millis();
    while (!Serial && (uint32_t)(millis() - serialWaitStarted) < 2000) {
      delay(10);
    }
    Serial.println("Open Rally Remote diagnostic firmware 0.2.0");
    Serial.println("Released switch = HIGH; pressed switch = LOW");
  }

  for (uint8_t i = 0; i < CONTROL_COUNT; ++i) {
    inputs[i].pin = CONTROL_PINS[i];
    if (!controlIsInstalled(i)) continue;
    pinMode(inputs[i].pin, INPUT_PULLUP);
  }

  synchronizeInputs(millis());
  beginBleKeyboard();

  if (SERIAL_DEBUG) {
    Serial.println("BLE advertising as: Open Rally Remote");
    Serial.println("Diagnostic letters: A-C = Button A, D-F = Button B,");
    Serial.println("G-I = Button C, arrows = joystick, J-L = joystick center.");
    Serial.println(CENTER_FROM_CHORD ? "Center: chord of three or more directions."
                                     : "Center: separate switch on D7.");
  }
}

void loop() {
  const uint32_t now = millis();
  const bool connected = Bluefruit.connected();

  if (connected != previousBleConnected) {
    previousBleConnected = connected;
    clearTapQueue();
    synchronizeInputs(now); // do not turn a held control into a reconnect event
    lastReportValid = false;
    if (connected) {
      publishAllKeysReleased(); // held controls are ignored until released
      if (SERIAL_DEBUG) Serial.println("BLE HID host connected");
    } else if (SERIAL_DEBUG) {
      Serial.println("BLE HID host disconnected");
    }
  }

  scanInputs(now);
  updateJoystick(now);
  processGestureTimers(now);
  processTapQueue(now);

  if (droppedTapCount && SERIAL_DEBUG) {
    Serial.print("Warning: diagnostic tap queue overflow count = ");
    Serial.println(droppedTapCount);
    droppedTapCount = 0;
  }

  delay(5);
}

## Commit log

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2026-10-09 Redesign remote as integrated split-ring clamp
    [complete-remote-v0.2.scad]
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2026-10-09 Add cutaway view and reinforce shoulder joins
    [complete-remote-v0.10.scad]
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2026-10-09 Split clamp diametrally and move bolts beside the bar
    V0.18 cuts the hull-defined housing silhouette through the handlebar
    axis, so the body and rear cap each wrap 180 degrees (less a 0.8 mm
    clamping gap) and the bar can enter the body. Two parallel M4 x 16
    socket-head bolts at +/-17 mm from the bar axis seat in counterbores
    in the rear cap and thread into heat-set inserts in the solid body
    shoulders; the old split ears are removed.
    V0.17 introduced the hull silhouette (pod outline + clamp circle) and
    fixed the missing fixed clamp ring of V0.15/V0.16, but its 250-degree
    body could not pass the handlebar. V0.13-V0.16 are added for history
    only. The mechanical concept guide now points to V0.1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
    [complete-remote-v0.13.scad, complete-remote-v0.14.scad, complete-remote-v0.15.scad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]
2026-10-09 Complete V0.19 enclosure for printing
    Make the front cover a slice of the pod/clamp silhouette so it matches
    the housing, fasten it with four M2 countersunk screws into heat-set
    inserts, add XIAO slide rails, a cable gland boss, shifted controls
    with joystick clearance, and print-orientation export modes.
    Rewrite the mechanical concept for V0.19 with the interior fit checks,
    print settings, assembly steps, hardware BOM and open unknowns.
    [complete-remote-v0.19.scad]
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2026-10-09 Replace joystick with four-key direction pad in V0.21
    Swap the Ruffy MHS panel joystick for four printed round keys over
    C&K KSC2 sealed tact switches, laid out as a diamond like the Remotek
    One arrow keys. On the lower facet the gasket becomes a full sheet that
    also serves as the key membrane, clamped by a printed keypad plate
    under the existing lower cover screws. Update the mechanical concept
    docs and renders.
    [complete-remote-v0.21.scad]
2026-10-09 Add low-cost joystick and wider control end in V0.22
    Drop the V0.21 key pad, whose 7 mm keys are too small for gloves and
    hard to press on the folded facet. Build a joystick from a steel dowel
    pin and a printed ball and cross disc that pivots in the joystick plate
    and rests on four KSC2 sealed tact switches; pushing it straight in
    gives the centre press as a four-switch chord. The 16 mm knob is held
    by a grub screw and stops on the cover before the switches bottom out.
    Widen the control end of the pod to 26 mm with 2 mm walls while the
    clamp keeps 23 mm on the bar. Update the mechanical concept docs and
    renders.
    [complete-remote-v0.22.scad]
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2026-10-10 Add joystick PCB and V0.23 enclosure
    Design the joystick PCB in KiCad: four C&K KSC2 switches on the front,
    5 V input protection (MF-MSMF050-2 PTC, SMBJ5.0A TVS) and wire pads on
    the rear. Board and schematic are generated from design.py; ERC, DRC
    and schematic parity are clean. Gerbers, drill, BOM, placement file
    and schematic PDF are in fab/.
    V0.23 enclosure follows the board: switches rotated 90 degrees for the
    real pad extent, standoffs moved clear of the pads, rear clearance split
    into zones to clear a USB-C plug in the XIAO, button-head M2 screws.
    The centre press becomes a chord of three or more directions; D7 is no
    longer used. Docs and renders updated.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
    [complete-remote-v0.23.scad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]
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2026-10-10 Add battery and removable remote study
    Compare battery options for the V0.23 enclosure, document the XIAO
    nRF52840 power path and charger limits, and sketch a removable remote
    on a fixed handlebar base (issue #1). No design change yet.
2026-10-10 Choose a removable remote with a fixed LiPo pouch
    Share one remote between bikes without bike wiring: a bayonet that
    turns around the bar on a base per bike, a fixed LiPo pouch, and
    charge contacts on the remote's back. Recheck the pouch fit with a
    grown ring keep-out, drop the swappable 16340, and list the
    measurements needed before CAD work.
2026-10-10 Design the removable remote for any bike
    Replace per-bike measurements with design rules: one universal
    remote, bases per bar size, a small entry angle released toward the
    rider, and a stated limit for bikes with less than 23 mm of free bar.
    Keep only the bench measurements on the parts.
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2026-10-11 Charge V0.24 through a sealed USB-C receptacle
    Replace the two brass charge contacts and the planned charging dock
    with a charge-only IP67 USB-C receptacle in the remote's rear face,
    above the dovetail groove. A small breakout PCB carries the 5.1 kohm
    CC pull-downs; VBUS and GND go to the joystick PCB input. The wall is
    thinned from inside for the panel gasket, and the base platform grows
    to Y = 33.5 mm so it covers the receptacle on the bike.
    No part is chosen yet: the receptacle sizes are typical values marked
    MEASURE. Renders, the fitting animation and the docs are updated.
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2026-10-11 Use GCT USB4736 for V0.24 charging
    Choose the GCT USB4736-GF-A-KIT: a charge-only, six-contact USB-C
    receptacle, IP67 with its USBTJ-06 gasket. It is the only part found
    that is sealed and keeps the CC lines; the waterproof USB-C parts on
    Amazon lack CC pins or are too large for the rear face.
    Model GCT's recommended panel from drawing USB4736 rev. A: a 1.80 mm
    wall, a 9.14 x 3.36 mm slot and an 11.00 x 5.90 x 0.60 mm gasket
    pocket, with the gasket squeezed about 41 %. Docs list the part and
    the small receptacle PCB still to design.
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2026-10-13 Add cost estimates to the bill of materials
    Give an estimated cost for each section of docs/bom.md, with the
    source and check date for each figure, and mark the figures that have
    not been checked against a shop.
    Record that the KSC222JLFS is out of stock at LCSC and compare it with
    the KSC221JLFS, which LCSC has in stock. The KSC221JLFS has the same
    force and land pattern but up to 0.65 mm of travel, which fails the
    V0.24 knob push-stop check unless the knob gap is increased.
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2026-10-14 Add BLE OTA through the factory bootloader
    The XIAO's factory bootloader (Adafruit 0.6.1) has a legacy BLE OTA
    mode. Add the BLEDfu service so a phone can start it, and record the
    bench test: an Android update works once the MTU request is disabled,
    but the bootloader accepts unsigned images and a failed transfer
    leaves no application. Print the BLE address at boot.
2026-10-14 Record the BLE OTA test with USB connected
    A second update, back to 0.3.0-diagnostic, ran with the XIAO on a
    computer's USB port. It completed at about 3.2 kB/s and the board
    started the new application without a manual reset, so the OTAFIX
    USB-host issue did not appear with bootloader 0.6.1.
2026-10-14 Add TerraPirata and keyboard profiles
    Bench tests on Android showed that one key map cannot serve every app:
    TerraPirata needs media keys (Play/Pause resets the total trip, volume
    adjusts it), OsmAnd accepts only keyboard keys, and TerraPirata and
    DMD2 time long presses themselves. Add two profiles with held button
    keys, switched by holding the joystick center for 5 s, stored in flash
    and shown by the LED colour. Record the key test results.
2026-10-14 Add a gestures profile for OsmAnd
    OsmAnd assigns one action per key and does not time long presses, so
    held keys give it only one action per button and repeat toggles. Add
    a third profile that sends a separate letter for each short, long and
    double press, shown by a white LED blink. The center keeps no long
    action because a long hold switches the profile.
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2026-10-14 Add the V0.26 no-solder assembly design and plan
    V0.25 needs about 25 hand-soldered joints, several under the XIAO rail
    lips. The design replaces them with three assembled boards, bought
    cables, a TPU keypad and a plug-in XIAO; the control board carries its
    own charger because the XIAO's BAT pads are not on its pins. The plan
    orders the work with a CAD fit check as the first gate.
2026-10-14 Record how the V0.26 control board powers the XIAO
    Seeed's XIAO nRF52840 v1.1 schematic shows the 3V3 pin is the direct
    output of its regulator, fed from BAT or VBUS. Feeding 3V3 from the
    control board works if that board's regulator blocks reverse current,
    for when the XIAO's own USB-C is plugged in. The schematic also
    confirms the 1 MOhm / 510 kOhm battery divider the firmware assumed.
    Ignore the plan workspace.
2026-10-14 Choose the V0.26 control board parts
    Pick parts the JLCPCB library stocks: MCP73831 charger, TPS70933
    regulator with reverse current protection, AO3401A for battery
    reverse polarity, SH-compatible and PH sockets and 5.7 mm female
    headers. The XIAO has no JLCPCB stock, which confirms the plug-in
    choice; the GCT USB-C receptacle is only available through global
    sourcing. Record the cable sources and the open measurements.
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2026-10-14 Add the V0.26 control board
    A 21.4 x 49 mm two-layer board behind the upper facet: three KSC2
    under the keys on the front; on the back the XIAO headers, MCP73831
    charger, TPS70933 regulator feeding the XIAO's 3V3 pin, AO3401A
    battery reverse-polarity protection, sense dividers and the JST
    sockets. It is generated from design.py and routed with Freerouting;
    ERC and DRC pass. The button plate standoffs move 3.95 mm off centre
    so the key web holes no longer cut them.
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2026-10-14 Add the V0.26 assembly video spec
    The assembly video is for design review: it shows each assembly step
    and checks the part paths for collisions at key poses. The spec
    records the agreed format (one MP4 with chapters) and the OpenSCAD
    plus Python approach.
2026-10-14 Add the V0.26 assembly video plan
    Five tasks: part list, timeline, collision check, frames and video,
    docs. Each task carries the tests that pin it.
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2026-10-14 Check the V0.26 assembly paths for collisions
    The check moves each part along its assembly path and intersects it
    with the parts in place at five poses, and checks every pair in the
    final pose. It finds that the housing cannot close onto the stack in a
    straight line: the lower-facet bosses meet the joystick board notches
    at 20 degrees. The vent label also runs into the lower-facet stack.
    It also finds a clear path for the USB-C board onto its rib. The report
    and the open unknowns record these.
2026-10-14 Add the V0.26 assembly video
    56 s, 1280 x 720, one chapter per assembly step, with the step text
    burned in. Parts in a colliding interval of the path check show in
    red. Assembly step 2 now describes the USB-C board path the check
    found, since the captions come from the assembly steps.
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2026-10-14 Add the joystick board rev C
    Rev B lets the lower cover bosses hit the board when the housing
    closes along X. Rev C turns the two notches toward the fold into 3 mm
    slots, moves both screws to the lower half and centres J1 between
    them. ERC and DRC with schematic parity: 0 errors.
2026-10-14 Add V0.27 so the housing closes in a straight line
    V0.27 uses the joystick board rev C: slots at the upper notches and
    both PCB screws in the lower half. The housing now moves along X onto
    the stack, and the cover comes off, without an overlap over 0.01 mm3
    except the J1 contact V0.26 already had. The assembly video tool now
    works per version; the V0.26 video and report stay as the record of
    the collision. Docs, BOM and renders follow.
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2026-10-14 Match the USB4736 footprint to GCT's layout
    The signal pads sat 0.10 mm closer to the board edge than GCT's
    recommended layout (drawing USB4736 rev. A). Every other feature
    matched. The USB-C board rev B is regenerated; ERC and DRC show no
    errors. Rev A has the same offset and is noted, not changed.
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2026-10-15 Add V0.29 without heat-set inserts
    No print service found fits M2 inserts (JLC3DP fits M3 to M5 only),
    so V0.29 drops all four inserts. The cover and clamp screws cut their
    own thread in printed pilots, the joystick knob takes an M2 square
    nut in a slot, and the lock knob an M3 nut in a hex pocket. The build
    now needs no hot tool.
    The battery cap's front screw boss is 0.3 mm lower, clear of the
    joystick board's J1. The assembly path check finds no collision.
2026-10-15 Add the cover seal spec
    The V0.29 keypad sheet cannot be squeezed 0.2 mm over the plates by
    M2 screws: it would need kilonewtons. The spec makes the sheet a
    loose membrane, seals the perimeter with a bought closed-cell foam
    strip on a lowered housing rim, sets the cover on small stop pads and
    seals each screw by the sheet stretched over it.
2026-10-15 Add the cover seal plan
    Five tasks: loose sheet stack, foam strip on a widened rim, stop pads
    and screw holes, regression checks and video, docs.
2026-10-15 Loosen the keypad sheet in V0.30
    The sheet is drawn at its free 0.8 mm and the plates sit 0.1 mm behind
    it, so it is no longer squeezed. The housing rim drops to leave room
    for the foam strip, and the plates, switches and bosses move back.
    The joystick knob's pin hole is 0.3 mm shallower so the 3 x 12 pin
    still reaches it.
2026-10-15 Add the V0.30 foam strip on a widened rim
    A 2 mm closed-cell foam strip, compressed to 1.0 mm, runs round both
    facets on the housing rim, under the loose sheet's edge. The rim
    widens to 2 mm at the two end walls, and the plates stop 2.15 mm
    from the outline to clear it. The strip is about 221 mm long.
2026-10-15 Add the V0.30 stop pads and stretch-sealed screw holes
    A Ø4 mm ring on each plate round every cover screw stands 0.15 mm
    proud and pinches the loose sheet 0.05 mm: about 8.5 N per screw
    instead of kilonewtons. The sheet's screw holes shrink to Ø1.4 mm so
    it grips the M2 shank, as it grips the joystick pin.
2026-10-15 Add the V0.30 assembly video
    The foam strip is a part: it goes onto the housing rim in step 7 and
    moves with the housing. The stop pads' pinch on the sheet is a
    contact by design. The path check finds no collision, and the older
    stack, removal and tilt checks give the V0.29 results.
2026-10-15 Document V0.30
    mechanical-concept.md gets Changes from V0.29 with the seal numbers,
    the V0.30 checks table, the sealing and printing notes, and new open
    unknowns: the foam strip's real force and joints, and the battery cap
    gasket, which has the problem V0.30 removed from the cover. The BOM
    gains the foam tape.
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2026-10-15 Mark the battery polarity at J5
    "+" and "-" on the control board's rear silkscreen beside J5 let a
    builder check a pouch's plug against pin 1 (BAT) before plugging it
    in. JST's PH drawing does not settle which side of the plug the latch
    is on, so the marks and a meter are the check. The board is routed
    again; ERC and DRC show no errors.
2026-10-15 Apply the control board review fixes
    An independent review found no critical defect. R3 and R5 become
    150k so D8 and D9 stay under the XIAO's pin limit with a low cell; C3
    and C4 become 4.7 uF, above the TPS709's output minimum and the same
    part as C1/C2; D1 becomes the 65 uA leakage SMBJ5.0A. The README
    records the open points: charge termination with the XIAO's load,
    overvoltage above the charger's rating, and a reversed cell with USB
    plugged in.
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2026-10-15 Document bare-board ordering and hand soldering
    Full double-sided assembly of the control and joystick boards was
    quoted at about 134 EUR, and JLCPCB could not source the USB4736
    receptacle. Bare boards cost 22.86 EUR for all three, so builders
    who can solder get a much cheaper path.
    The BOM now lists three ways to order the boards with their quotes:
    bare boards, Economic assembly of the bottom side only, and
    Standard double-sided assembly. lcsc-parts.csv loads into LCSC's
    BOM tool with quantities for two remotes. The economic-bottom
    BOM and placement files support the middle option.
    It also fixes a wrong claim: JLCPCB's C9900206672 is the
    USB4736-GF-A without the USBTJ-06 gasket. The kit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
2026-10-19 Consolidate consumables and M2 screws in the BOM
    Fewer distinct purchases for one build. Plain M2 x 4 button-head
    screws replace the M2 x 5 and M2 x 4 thread-forming screws: both
    cut their own thread in the printed pilots. One clear two-part epoxy
    covers the USB potting and the LED window, so the UV resin and the
    neutral-cure silicone go. The battery cap gasket is cut from the
    foam round a printed paper template instead of a TPU print.
2026-10-19 Add V0.32 with fewer parts to buy
    The lock screw becomes an M3 x 20: V0.31's M3 x 22 is not an
    ISO 4762 length. It passes 1.0 mm through the knob's nut, which the
    clear epoxy fixes, so the lock nut goes.
    The anti-rattle strips, and optionally the clamp liner, are cut from
    a bike inner tube. The strip pocket follows the measured thickness,
    so the squeeze stays 0.3 mm for tubes from 0.8 to 1.2 mm. The foam
    pads come in layers from the seal foam sheet.
    The joystick knob keeps its square nut: an M2 hex nut, corner up so
    it cannot spin, needs 5.3 mm where the knob has 4.8 mm.
    The V0.31 video keeps the remote, which V0.32 does not change; it is
    rebuilt so its chapter titles match the edited ass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
2026-10-20 Record the import charges on the bare-board order
    A JLCPCB bare-board order for the three boards was charged EUR 31.56
    in import charges on 2026-10-20, more than the boards themselves. The
    breakdown is not known. With it the bare boards cost about EUR 64,
    so the BOM's board cost was too low.
2026-10-20 Add checked hardware prices and cost per remote count
    The first build costs far more than each later one, because boards,
    LCSC minimums, customs duty, shipping, fastener packs and consumables
    are paid once. A builder needs to see that before starting.
    Add a cost table for 1, 2 and 5 remotes. Replace the assortment kit
    estimate with single-size AliExpress packs, including the import
    charges its checkout showed on 2026-10-20 (it seems to charge per
    listing, not per tariff class). Add Amazon.es prices for the spring,
    the foam sheet, the conformal coating and the epoxy.
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2026-10-20 Add a key probe sketch for app key discovery
    TerraPirata's screen lock and trip reset keys were unknown. The probe
    sends one candidate key at a time over BLE HID, selected with the
    bench buttons and logged on the serial port, so each key's effect in
    an app can be recorded on its own.
    The candidates come from the key codes a commercial rally remote's
    ESP32 firmware sends; only its key codes were read. The results for
    TerraPirata on Android are in the README: x locks the screen, r opens
    the trip reset, z resets the total, F6/F7 scroll the roadbook. A first
    pass guided by the LED was offset by one candidate and was discarded.
2026-10-20 Map TerraPirata's lock and resets in firmware 0.9.0
    The TerraPirata profile held media keys on the buttons, which also
    change the phone's volume or playback in any app in front, and it had
    no screen lock or trip reset. With the keys found by the key probe:
    - C sends x on release: lock or unlock the screen.
    - A held 2 s sends r: the trip reset dialog, confirmed on the screen.
    - B held 2 s sends z: reset the total.
    - Short and double presses of A and B send nothing.
    The joystick keeps the held arrows (trip -/+ and roadbook scroll). The
    long press for these resets is 2 s, not 600 ms, so a bump or a glove
    does not reset a counter. A control with no double action now sends
    its short action on r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
2026-10-20 Add host tests for the bench firmware
    The profile and gesture logic was only checked by hand on the bench.
    The sketch now also builds on a computer against stand-ins for the
    Arduino core, Bluefruit, TinyUSB and LittleFS: simulated switches,
    clock, BLE link and flash, with the HID reports recorded. Twenty tests
    drive switch timelines and check the keys sent, for the three
    profiles, the joystick chord, the profile switch, the power off and
    reconnecting. `make -C firmware/xiao-nrf52840/test` runs them on both
    BOARD_V026 builds, each test in its own process.
    They found a stale startup message that still described the 0.8.0
    TerraPirata keys; it now describes the 0.9.0 map. Three bugs injected
    by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
2026-10-20 Update open unknowns and translate the mechanical notes
    Four open unknowns can be updated from the CAD and the parts chosen:
    - XIAO: the 8.5 mm header alternative also clears (4.5 mm to the
    pouch, 4 foam layers).
    - Lock: the 0.5 x 5 x 10 mm spring fits the pocket and the shank;
    its solid length must stay under the 4.0 mm of lock_spring_solid,
    or the lock cannot release, so its coils must be counted.
    - USB-C: JLCPCB's footprint for the receptacle no longer matters; it
    is soldered by hand in every ordering option.
    - Vent: a 8 mm label is available in small packs and clears in the
    CAD; whether it seals is left to the leak test.
    Add the Spanish translation, mechanical-concept.es.md,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
2026-10-20 Add the profile selection design
    The profile cycles on a 5 s hold of the joystick center, and the only
    sign of the result is the XIAO's LED, hidden in the housing. The
    design replaces the cycle with a direct choice: hold the center 5 s,
    release, then press A, B or C for TerraPirata, keyboard or gestures.
    The button pressed tells the rider the profile set. No hardware
    changes; the boards are already ordered.
    Also record that TerraPirata's trip reset dialog is confirmed on the
    screen by choice, instead of listing a key for it as not found.
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2026-10-21 Add V0.33 with 2 mm walls and the materials study
    The 1 mm walls of the narrow part and the ends gave two FDM
    perimeters, which can leak, and little margin in a fall. The 23 mm
    width behind them came from the NAVCOMM manual, a reference only.
    V0.33 grows the walls to 2 mm outward: the remote and the base are
    25 mm wide and the remote 2 mm taller; the cavity is unchanged.
    The materials study compares print materials against sun, rain,
    fuel, cold and falls, and records EU print quotes. The material is
    not chosen yet. Add Blender photo renders, the V0.33 video and path
    check, and the Spanish BOM.
2026-10-21 Record the USB-C gasket squeeze and PCB edge unknowns
    Dry fits on the first JLCPCB boards put the receptacle nose 1.5-1.9 mm
    past the board edge, against 1.70 mm in the design, so the milled
    outline varies by about 0.2 mm. The V0.33 board edge has 0.43 mm to
    the wall.
    GCT's drawing shows the gasket bears on the receptacle body, and asks
    for a 0.09 mm squeeze window. Print and part tolerances are larger,
    and rigid shims would add a joint that does not seal. Record the
    options and the measurement to take once the board is soldered.
2026-10-22 Record the measured lock spring in the BOM
    The bought 0.5 x 5 x 10 mm spring was measured: 7 coils with closed,
    unground ends, 5-6 active, 3.6 mm solid. The lock compresses it to
    4.0 mm, so it never goes solid. With 5-6 active coils it is stiffer
    than first estimated: about 4-4.7 N locked and 6-7 N pulled instead of
    3.4 and 5 N. Note which end faces the pocket floor, so the cut tip does
    not rub the screw head.
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
